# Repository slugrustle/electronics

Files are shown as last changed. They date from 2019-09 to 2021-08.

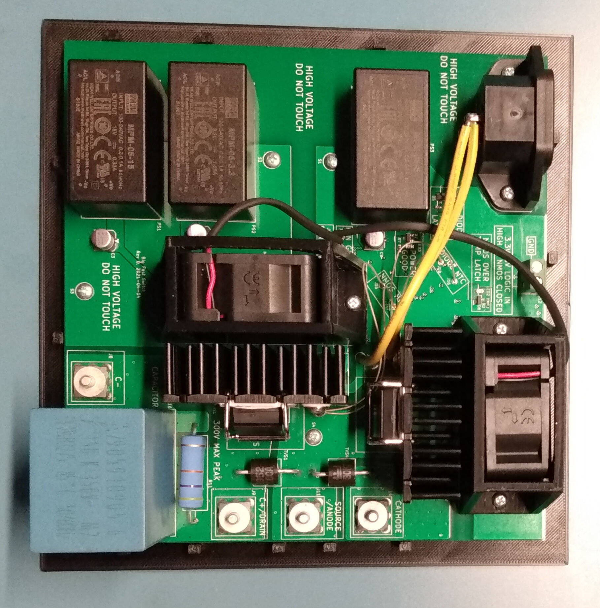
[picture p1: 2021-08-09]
Big_Fast_Switch/Assembled_Unit_Top.jpg

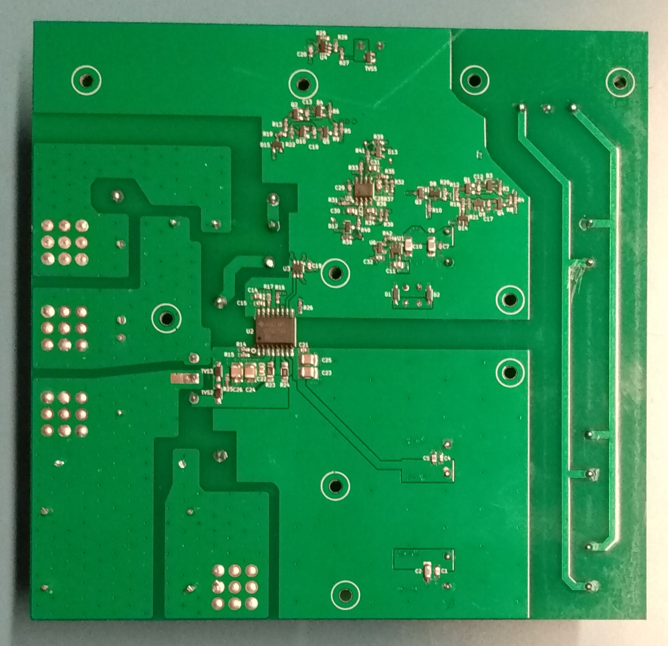
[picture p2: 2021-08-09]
Big_Fast_Switch/Board_Bottom_Soldered.jpg

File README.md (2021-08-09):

# Electronics

This repository includes various electronics projects in a sufficient state of completion to publish informally.

HighImpedanceBuffer is a two&#x2011;channel unity gain buffer amplifier with high impedance inputs and a &#xb1;17.5V input range.

SOT23ZenerTester is a fixture and set of software that can be used to obtain the voltage / current curves of SOT23&#x2011;3 case Zener diodes when used in conjunction with other test equipment.

TestSequencer is a fairly simple board that surrounds an 8&#x2011;bit PIC microcontroller with a power supply, programming header, and various inputs and outputs through ESD protected terminal blocks. I use it for controlling other equipment and running tests.

HH509R\_Logger is a command line program to log temperature measurements from an Omega Engineering HH509R thermocouple reader.

Big\_Fast\_Switch is a sizable combination of film capacitor, N-MOSFET, and rectifier intended for generating input voltage transients to test DC->DC converters.

## Getting Started

The README files the individual directories descibed above are a good place to start.

## Contributing

I would love to receive bug reports and user feedback. If you have improvements to the code, please get in touch.

## Author

Ben Tesch &#x2013; [slugrustle](https://github.com/slugrustle)

## License

All files in this repository that have been produced by the author are distributed under the [CC0 1.0 Universal Public Domain Dedication](https://creativecommons.org/publicdomain/zero/1.0/). See also LICENSE.txt in each project directory and the files themselves.

The projects in this repository store copies of datasheets for parts used in each project. These remain under the copyright of their respective owners and are provided for reference.

The SOT23ZenerTester project also includes copies of files from the redistributable software for the Diolan DLN&#x2011;4ME interface adapter. These files belong to Diolan; see https://diolan.com for more information.

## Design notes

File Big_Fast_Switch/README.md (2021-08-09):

## Big\_Fast\_Switch

This project is a single-board assembly containing the following power electronic devices

- Large, high-voltage film capacitor (B32756G8156K000)
- High-voltage, low Rds(on), wide SOA N-Channel MOSFET (STY145N65M5)
- High-voltage, high-current fast rectifier (VS-90EPF06L-M3)

and the following support electronics / devices

- An isolated gate driver for the N-MOSFET
- Input logic (3.3V level, 5V tolerant) to control the N-MOSFET
- Independent heatsinks, fans, and temperature sensors for the N-MOSFET and Rectifier
- Overtemperature detection and latch circuitry that opens the N-MOSFET if either the N-MOSFET or Rectifier exceeds a temperature limit
- Separate AC->DC power supplies for the gate drive voltage supply (floating) and for the input logic, overtemperature circuitry, and cooling fans

This assembly was designed to aid in generating input voltage transients for the testing of DC->DC power supplies, but it could perhaps find other uses.

WARNING: Dangerous high voltages are present on this board including AC line voltage and high DC voltages. The construction or operation of this device is solely at your own risk. Do not attempt unless you are competent to personally evaluate the safety of high voltage electronic systems.

### Other Info

- Pictures of an assembled unit are available in the root of this repository.
- Design files for the board and schematic (as well as PDF / SVG printouts) are stored in the KiCad directory. I ordered the boards from PCBWay as 4-layer FR-4 boards with 3oz copper on all layers.
- STL files for a PCB holder and mounts for the cooling fans are available in the OpenSCAD directory. I printed these with flame retardant ABS filament.
- A full bill of materials can be found in the Bill\_of\_Materials directory.
- I attempted to save datasheets for all utilized components in the Datasheets directory.
- An LTspice simulation of the overtemperature detection and latch circuitry can be found in the Simulation directory. There are ancillary files from my attempt to create a reasonable model of the APT2012SURCK red LED.
- See LICENSE.txt for licensing info. I have endeavored to clarify which data stored here is my own work and which data belongs to others; all work that is my own is released under the CC0 1.0 Universal Public Domain Dedication.

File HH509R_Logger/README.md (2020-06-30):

## Data Logging Program for HH509R Thermocouple Reader

HH509R\_Logger.exe (in the Release\ directory) is a command line program that records temperature data from an Omega Engineering HH509R datalogging thermocouple reader and saves this data to a .xlsx workbook file. Temperature data is also printed live to the screen while the program is running.

To use this program, run

```PS > .\HH509_Logger.exe COM1 output_file.xlsx```

from PowerShell or the command line. COM1 stands in for the COM port to which the HH509R is connected. The thermocouple reader should be powered on before running HH509\_Logger.exe.

The program ceases collecting data and saves its output .xlsx file under four conditions:

1. The user keys Ctrl+C in the PowerShell or command line window.
2. The program receives no data of any kind from the HH509R for 60 seconds.
3. The program receives no valid data from the HH509R for 300 seconds.
4. The amount of collected data has reached the row limit of a .xlsx workbook file.

See Release\example\_data.xlsx for an example output file.

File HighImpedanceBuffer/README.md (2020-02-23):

## 2&#x2011;Channel High Input Impedance Unity&#x2011;Gain Buffer Amplifier

This project is a 2&#x2011;channel unity&#x2011;gain buffer amplifier built around the Texas Instruments OPA192. The amplifier inputs have ESD protection and high input impedance. The amplifier will behave normally with up to &#xb1;17.5V signal on its inputs. It is powered from a 20VAC 200mA supply such as the Triad Magnetics WAU20&#x2011;200 or similar.

There is a 120&#x3a9; impedance inside the amplifier feedback loop after the internal opamp output pin which limits the output voltage range at heavier output loads. Due to this phenomenon and the thermal characteristics of the voltage regulators, it is recommended that the impedance of the load applied to the output of each amplifier be 1.1k&#x3a9; or higher.

To maintain high input impedance, there is no resistance biasing the external amplifier inputs to GND in a default state. Consequently, if a channel is unused, it is recommended to connect IN to COM (or GND) for that channel.

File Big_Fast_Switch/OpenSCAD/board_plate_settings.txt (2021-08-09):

Application version: 2.20.0.0
Estimated print time: 13h 45m
Material usage: 63.69m (152g)
Printer: Zortrax M200 Plus
Profile: Last settings
Support type: Automatic
Support: 30°
Material: ABS-based filament
Nozzle diameter: 0.4 mm
Layer: 0.14 mm
Quality: Default
Infill: 70%
Fan speed: Auto
Seam: Random
Outer contours: 0.00
Holes: 0.00
Contour-infill gap: 0.40
Contour-top gap: 0.30
Surface layers Top: 5
Surface layers Bottom: 5
Support Lite: Yes
Smart bridges: Yes
Max. wall thickness: 3.03 mm
First layer Density: 100%
First layer Print speed: 100%
First layer Flow ratio: 100%
First layer gap: 0.26 mm
Raft Enabled: Yes
Raft layers: 7
Platform-raft gap: 0.22 mm
Raft Density: 100%
Raft Print speed: 100%
Raft Flow ratio: 100%
Print speed: +0%
Extruder flow ratio: +0%
Top layer infill (%): 100
Bottom layer infill (%): 100
Extrusion temp.: 235
Platform temp.: 90
Retraction speed: 36
Retraction distance: 0.8
Support Density: 3.00 mm
Gap XY: 0.36
Cooling tower: No

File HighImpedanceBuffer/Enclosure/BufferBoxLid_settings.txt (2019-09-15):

Application version: 2.11.1.0
Estimated print time: 3h 34m
Material usage: 17.42m (41g)
Printer: Zortrax M200 Plus
Profile: Last settings
Support type: Automatic
Support: 20°
Material: Z-ULTRAT
Nozzle diameter: 0.4 mm
Layer: 0.14 mm
Quality: High
Infill: 70%
Fan speed: Auto
Seam: Normal
Outer contours: 0.00
Holes: 0.00
Surface layers Top: 5
Surface layers Bottom: 5
Support Lite: No
Smart bridges: No
Support offset: Yes
Max. wall thickness: 3.5 mm
First layer Density: 100%
First layer Print speed: 100%
First layer Flow ratio: 100%
First layer gap: 0.30 mm
Raft Enabled: Yes
Raft layers: 7
Platform-raft gap: 0.24 mm
Raft Density: 100%
Raft Print speed: 100%
Raft Flow ratio: 100%
Support Density: 2.00 mm
Gap XY: 0.36

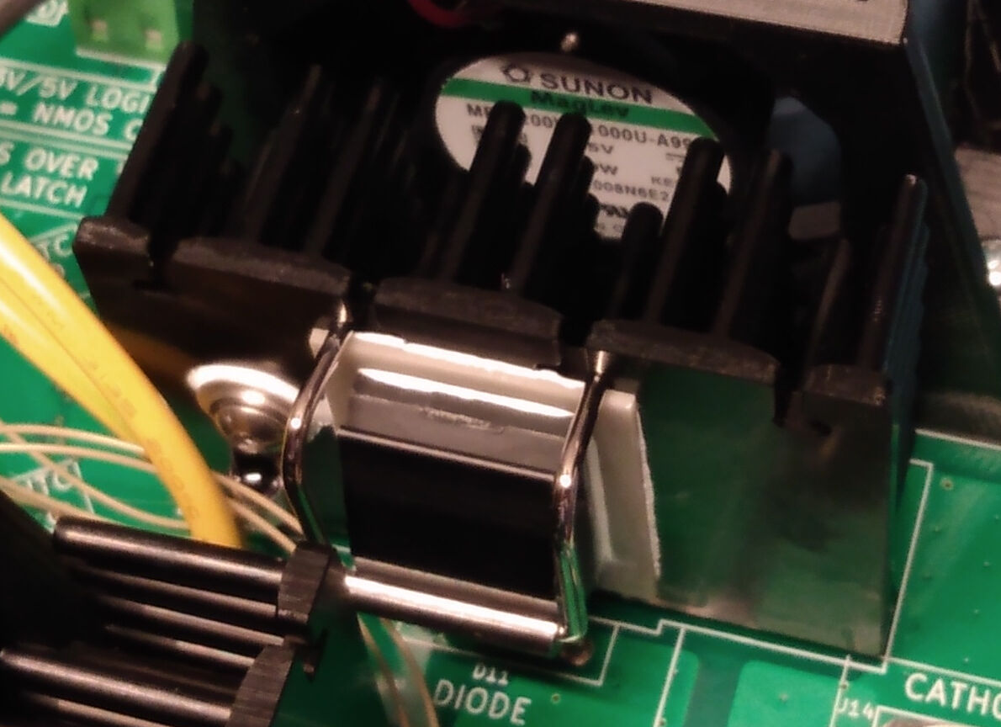
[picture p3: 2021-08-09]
Big_Fast_Switch/Diode_and_NTC_Heatsink_Mounting.jpg

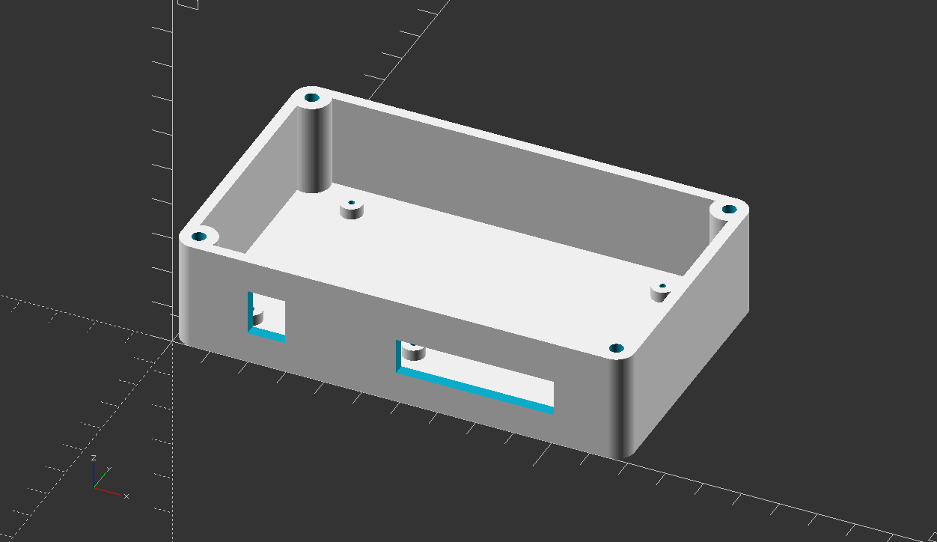
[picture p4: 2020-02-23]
HighImpedanceBuffer/Enclosure/BufferBox_DiagonalView.png

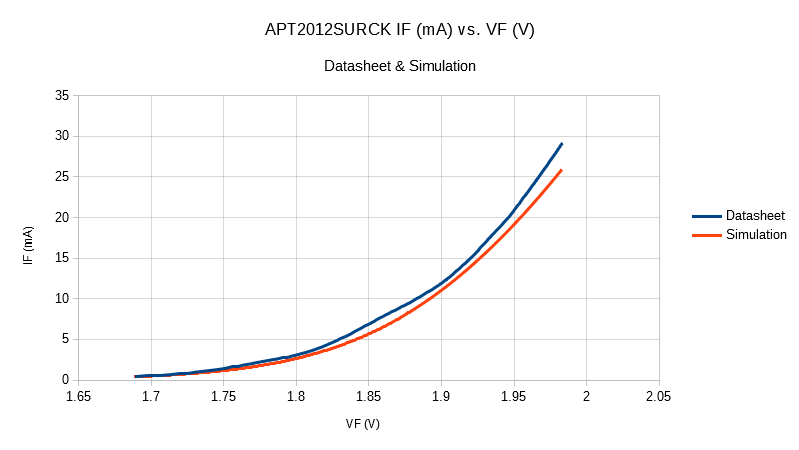
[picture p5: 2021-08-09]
Big_Fast_Switch/Simulation/APT2012SURCK_Model_Check.png

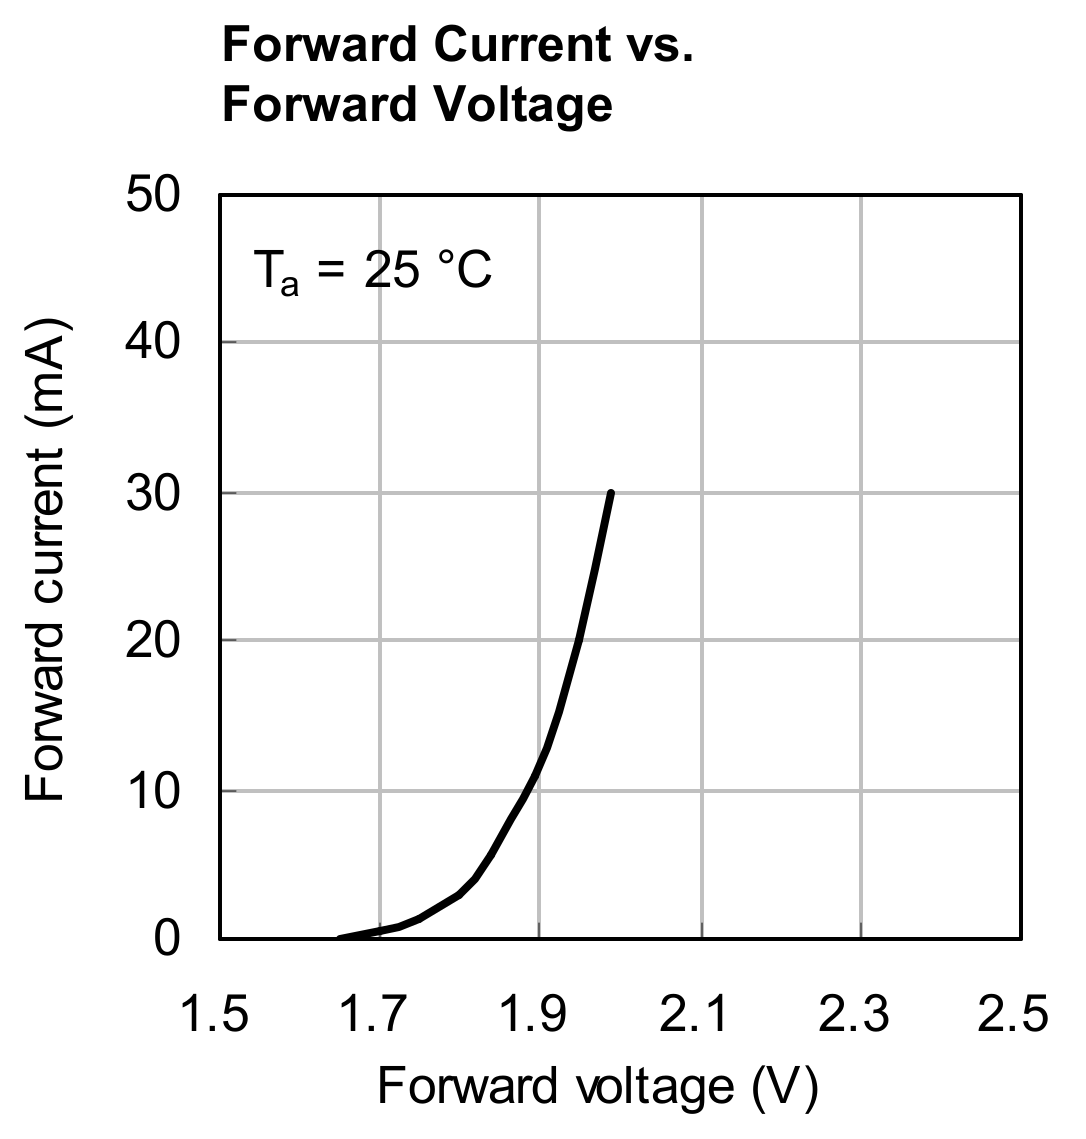
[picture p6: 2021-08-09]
Big_Fast_Switch/Simulation/APT2012SURCK_I-V_298K.png

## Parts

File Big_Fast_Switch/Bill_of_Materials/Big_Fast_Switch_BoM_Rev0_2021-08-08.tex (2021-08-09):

\documentclass[11pt,letterpaper]{article}
\usepackage[T1]{fontenc}
\usepackage{amsmath}
\usepackage{parskip}
\usepackage{longtable}
\usepackage[landscape]{geometry}
\usepackage{titling}
\usepackage{fancyhdr}
\usepackage{lastpage}
\usepackage[math-style=ISO]{unicode-math}
\usepackage{textgreek}
\usepackage{textcomp}
%\usepackage{showframe}

\geometry{
letterpaper,
top=0.5in,
bottom=0.5in,
left=0.5in,
right=0.5in,
includefoot
}

\setlength{\droptitle}{-0.55in}
\pretitle{\begin{flushleft}}
    \posttitle{\end{flushleft}}
\preauthor{\begin{flushleft}}
    \postauthor{\end{flushleft}}
\predate{}
\date{}
\postdate{}

\pagestyle{fancy}
\fancyhf{}
\renewcommand{\headrulewidth}{0pt}
\cfoot{\thepage\ / \pageref{LastPage}}

\begin{document}
\title{Big Fast Switch Rev0 Bill of Materials}
\author{2021{\textendash}08{\textendash}08}
\maketitle
\thispagestyle{fancy}

{\renewcommand{\arraystretch}{1.5}
\begin{longtable}{| l || l | p{4cm} | p{3.5cm} | p{9.5cm} |}
\hline\textbf{Part \#} & \textbf{Quantity} & \textbf{Designators} & \textbf{Manufacturer} & \textbf{Description}\\\hline\hline\endhead
C2012X7R1H104K085AA & 2 & C1, C22 & TDK & 100nF {\textpm}10\% 50V X7R capacitor, 0805 case\\\hline
CL31B225KBHNNNE & 1 & C2 & Samsung & 2.2{\textmu}F {\textpm}10\% 50V X7R capacitor, 1206 case\\\hline
25SVPF47M & 3 & C3, C6, C9 & Panasonic & 47{\textmu}F {\textpm}20\% 25V Aluminum polymer capacitor\\\hline
CL10B104KA8NFNC & 12 & C4, C7, C12, C13, C15, C17{\textendash}C21, C29, C32 & Samsung & 100nF {\textpm}10\% 25V X7R capacitor, 0603 case\\\hline
CL21B225KAFNNWE & 3 & C5, C11, C14 & Samsung & 2.2{\textmu}F {\textpm}10\% 25V X7R capacitor, 0805 case\\\hline
CL31B225KOHNNNE & 2 & C8, C10 & Samsung & 2.2{\textmu}F {\textpm}10\% 16V X7R capacitor, 1206 case\\\hline
B32756G8156K000 & 1 & C16 & TDK & 15{\textmu}F {\textpm}10\% 600V film capacitor\\\hline
CL32B106KAJNNNE & 4 & C23{\textendash}C26 & Samsung & 10{\textmu}F {\textpm}10\% 25V X7R capacitor, 1210 case\\\hline
CL21B475KOFNNNE & 2 & C27, C28 & Samsung & 4.7{\textmu}F {\textpm}10\% 16V X7R capacitor, 0805 case\\\hline
CL21B105KBFNNNG & 2 & C30, C31 & Samsung & 1{\textmu}F {\textpm}10\% 50V X7R capacitor, 0805 case\\\hline
1N4448W-7-F & 2 & D1, D2 & Diodes Inc. & 75V 250mA switching diode, SOD{\textendash}123 case\\\hline
BAS16,215 & 8 & D3{\textendash}D10 & Nexperia & 100V 215mA switching diode, SOT{\textendash}23{\textendash}3 case\\\hline
VS-90EPF06L-M3 & 1 & D11 & Vishay & 600V 90A fast soft recovery rectifier diode, TO{\textendash}247AD 2L case\\\hline
BAV199-7-F & 2 & D12, D13 & Diodes Inc. & Dual 85V 140mA low leakage diode, series connection, SOT{\textendash}23{\textendash}3 case\\\hline
BAS70-7-F & 2 & D14, D15 & Diodes Inc. & 70V 70mA Shottky diode, SOT{\textendash}23{\textendash}3 case\\\hline
PA-T21-38E & 2 & HS1, HS2 & Ohmite & Heatsink with clip for TO{\textendash}247 or TO{\textendash}264 devices\\\hline
NTCALUG02A103F161 & 2 & {\textemdash} & Vishay & 10k{\textOmega} {\textpm}1\% $\text{R}_{25}$ 3984K {\textpm}0.5\% $\text{\textbeta}_{25/85}$ ring lug mount NTC thermistor. Mount one to HS1 and wire to J15 \& J17. Mount the other to HS2 and wire to J16 \& J18.\\\hline
94500A221 & 2 & {\textemdash} & McMaster{\textendash}Carr & M3 x 0.5mm thread, 6mm long 2mm hex drive screw for mounting thermistors to heatsinks\\\hline
93237A102 & 2 & {\textemdash} & McMaster{\textendash}Carr & M3 Belleville washer for mounting thermistors to heatsinks\\\hline
3135-16-1-0500-011-1-TS & {\textemdash} & {\textemdash} & CnC Tech & Stranded 16AWG 600V wire for connecting HS1 (J10) \& HS2 (J13) to earth lug on back of J1\\\hline
703W-00/52 & 1 & J1 & Qualtek & IEC320-C14 AC power input receptacle\\\hline
74651194R & 4 & J8, J9, J11, J14 & Wurth & M4 shank solderable terminal\\\hline
282837-2 & 1 & J12 & TE Connectivity & 5.08mm pitch 2 position rising cage clamp terminal block\\\hline
APT2012SURCK & 3 & LED1{\textendash}LED3 & Kingbright & Red SMT LED, 0805 case\\\hline
{\textemdash} & 2 & M1, M2 & {\textemdash} & 3D printed mount for fan\\\hline
MF40200V1-1000U-A99 & 2 & {\textemdash} & Sunon & 5V 40mm x 40mm x 20mm BLDC fan\\\hline
MPM-05-15 & 1 & PS1 & Meanwell & 15V 5W Medical rated board mount AC/DC converter\\\hline
MPM-05-3.3 & 1 & PS2 & Meanwell & 3.3V 5W Medical rated board mount AC/DC converter\\\hline
MPM-05-5 & 1 & PS3 & Meanwell & 5V 5W Medical rated board mount AC/DC converter\\\hline
MMBT3906LT1G & 2 & Q1, Q2 & ON Semi & 40V 200mA PNP transistor, SOT{\textendash}23{\textendash}3 case\\\hline
MMBT3904LT1G & 3 & Q3{\textendash}Q5 & ON Semi & 40V 200mA NPN transistor, SOT{\textendash}23{\textendash}3 case\\\hline
STY145N65M5 & 1 & Q6 & ST & 650V 15m{\textOmega} 138A N{\textendash}MOSFET, Max247 case\\\hline
{\textemdash} & 2 & {\textemdash} & Shenzhen Jia Rifeng Tai Company & 22mm x 28mm x 1mm Aluminum Nitride insulator for D11 \& Q6. Solid{\textemdash}no mounting hole.\\\hline
249G & {\textemdash} & {\textemdash} & Aavid Thermalloy & Silicone grease for mounting D11 \& Q6.\\\hline
RC0603FR-07620RL & 3 & R1, R2, R7 & Yageo & 620{\textOmega} {\textpm}1\% {\textpm}100ppm/{\textcelsius} 100mW resistor, 0603 case\\\hline
RC0603FR-0733KL & 4 & R3, R6, R21, R22 & Yageo & 33k{\textOmega} {\textpm}1\% {\textpm}100ppm/{\textcelsius} 100mW resistor, 0603 case\\\hline
RC0603FR-0710KL & 7 & R4, R5, R25, R34, R35, R40, R41 & Yageo & 10k{\textOmega} {\textpm}1\% {\textpm}100ppm/{\textcelsius} 100mW resistor, 0603 case\\\hline
RC0603FR-0743KL & 2 & R8, R9 & Yageo & 43k{\textOmega} {\textpm}1\% {\textpm}100ppm/{\textcelsius} 100mW resistor, 0603 case\\\hline
RC0603FR-073K9L & 1 & R10 & Yageo & 3.9k{\textOmega} {\textpm}1\% {\textpm}100ppm/{\textcelsius} 100mW resistor, 0603 case\\\hline
ROX5SJ47K & 1 & R11 & TE Connectivity & 47k{\textOmega} {\textpm}5\% {\textpm}350ppm/{\textcelsius} 5W metal oxide film resistor, axial through hole\\\hline
RC0603FR-076K2L & 2 & R12, R13 & Yageo & 6.2k{\textOmega} {\textpm}1\% {\textpm}100ppm/{\textcelsius} 100mW resistor, 0603 case\\\hline
RC0603JR-07100RL & 2 & R14, R15 & Yageo & 100{\textOmega} {\textpm}5\% {\textpm}100ppm/{\textcelsius} 100mW resistor, 0603 case\\\hline
RC0603JR-0722RL & 2 & R16, R27 & Yageo & 22{\textOmega} {\textpm}5\% {\textpm}100ppm/{\textcelsius} 100mW resistor, 0603 case\\\hline
RC0603JR-071KL & 2 & R17, R26 & Yageo & 1k{\textOmega} {\textpm}5\% {\textpm}100ppm/{\textcelsius} 100mW resistor, 0603 case\\\hline
RC0603FR-072K7L & 2 & R18, R19 & Yageo & 2.7k{\textOmega} {\textpm}1\% {\textpm}100ppm/{\textcelsius} 100mW resistor, 0603 case\\\hline
RC0603FR-0756KL & 1 & R20 & Yageo & 56k{\textOmega} {\textpm}1\% {\textpm}100ppm/{\textcelsius} 100mW resistor, 0603 case\\\hline
CRCW12062R70JNEAHP & 1 & R23 & Vishay & 2.7{\textOmega} {\textpm}5\% {\textpm}200ppm/{\textcelsius} 750mW pulse withstanding resistor, 1206 case\\\hline
CRCW12061R00JNEAHP & 1 & R24 & Vishay & 1{\textOmega} {\textpm}5\% {\textpm}200ppm/{\textcelsius} 750mW pulse withstanding resistor, 1206 case\\\hline
RC0603JR-07100KL & 3 & R28, R29, R42 & Yageo & 100k{\textOmega} {\textpm}5\% {\textpm}100ppm/{\textcelsius} 100mW resistor, 0603 case\\\hline
ERJ-PB3B5230V & 6 & R30, R32, R36{\textendash}R39 & Panasonic & 523{\textOmega} {\textpm}0.1\% {\textpm}50ppm/{\textcelsius} 200mW resistor, 0603 case\\\hline
RC0603FR-077K5L & 2 & R31, R33 & Yageo & 7.5k{\textOmega} {\textpm}1\% {\textpm}100ppm/{\textcelsius} 100mW resistor, 0603 case\\\hline
90417A118 & 4 & S1{\textendash}S4 & McMaster{\textendash}Carr & \#4{\textendash}20 x 3/8" thread forming screw for plastics\\\hline
90417A119 & 6 & {\textemdash} & McMaster{\textendash}Carr & \#4{\textendash}20 x 1/2" thread forming screw for plastics. 2 each applied to J1, M1, and M2.\\\hline
{\textemdash} & 1 & {\textemdash} & {\textemdash} & 3D printed board support plate\\\hline
30KPA300CA & 2 & TVS1, TVS4 & Littelfuse & 300V V\textsubscript{WM} bidirectional TVS diode, P600 axial through hole case\\\hline
SMF15A-E3-08 & 1 & TVS2 & Vishay & 15V V\textsubscript{WM} unidirectional TVS diode, SMF case\\\hline
PTVS3V3S1UR & 1 & TVS3 & Nexperia & 3.3V V\textsubscript{WM} unidirectional TVS diode, SOD{\textendash}123W case\\\hline
DLP05LC-7-F & 1 & TVS5 & Diodes Inc. & 5V V\textsubscript{WM} low capacitance unidirectional TVS diode, SOT{\textendash}23{\textendash}3 case\\\hline
MIC5225-3.3YM5 & 1 & U1 & Microchip & 3.3V linear regulator, SOT{\textendash}23{\textendash}5 case\\\hline
UCC21750 & 1 & U2 & TI & Isolated MOSFET gate driver, Wide SOIC{\textendash}16 case\\\hline
SN74LVC1G11DBVR & 1 & U3 & TI & 3-Input AND gate, SOT{\textendash}23{\textendash}6 case\\\hline
SN74LVC1G17DBVR & 1 & U4 & TI & Non-inverting Schmitt trigger buffer, SOT{\textendash}23{\textendash}5 case\\\hline
LMV762MA & 1 & U5 & TI & Dual precision comparator, SOIC{\textendash}8 case\\\hline
TPS3839G33DBZR & 1 & U6 & TI & 3.08V threshold supply voltage monitor, active low output, SOT{\textendash}23{\textendash}3 case\\\hline
\end{longtable}}
\end{document}

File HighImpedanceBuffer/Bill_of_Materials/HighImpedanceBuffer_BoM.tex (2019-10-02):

\documentclass[11pt,letterpaper]{article}
\usepackage[T1]{fontenc}
\usepackage{amsmath}
\usepackage{parskip}
\usepackage{longtable}
\usepackage{geometry}
\usepackage{titling}
\usepackage{fancyhdr}
\usepackage{lastpage}
\usepackage[math-style=ISO]{unicode-math}
\usepackage{textgreek}
\usepackage{textcomp}
%\usepackage{showframe}

\geometry{
letterpaper,
top=0.5in,
bottom=0.5in,
left=0.5in,
right=0.5in,
includefoot
}

\setlength{\droptitle}{-0.5in}
\pretitle{\begin{flushleft}}
    \posttitle{\end{flushleft}}
\preauthor{\begin{flushleft}}
    \postauthor{\end{flushleft}}
\predate{}
\date{}
\postdate{}

\pagestyle{fancy}
\fancyhf{}
\renewcommand{\headrulewidth}{0pt}
\cfoot{\thepage\ / \pageref{LastPage}}

\begin{document}
\title{High Impedance Buffer Rev4 Bill of Materials}
\author{2019-10-01}
\maketitle
\thispagestyle{fancy}

{\renewcommand{\arraystretch}{1.5}
\begin{longtable}{| l || l | p{2.4cm} | p{3.3cm} | p{4.5cm} |}
\hline\textbf{Part \#} & \textbf{Quantity} & \textbf{Designators} & \textbf{Manufacturer} & \textbf{Description}\\\hline\hline\endhead
PJ-102AH & 1 & J1 & CUI Inc. & Jack for 2.1mm ID, 5.5mm OD barrel plug\\\hline
WAU20-200 & 1 & \textemdash & Triad Magnetics & 120VAC 60Hz input, 20VAC 200mA output wall adapter. 2.1mm ID, 5.5mm OD barrel plug\\\hline
SF-2410FP0375T-2‎ & 1 & F1 & Bourns & 375mA 125V 0.1502$\text{A}^{2}\text{s}$ fast fuse, 2410 case\\\hline
SMBJ36CA-13-F‎ & 1 & D3 & Diodes Inc. & 36V V$_{\text{WM}}$ bidirectional TVS diode, SMB case\\\hline
NRVTSA4100ET3G‎ & 2 & D4, D5 & ON Semiconductor & 100V low leakage, low V$_{\text{F}}$ Schottky diode, SMA case\\\hline
EEV-TG1H471M‎ & 2 & C5, C6 & Panasonic & 470{\textmu}F, 50V, 125{\textdegree}C, low ESR electrolytic capacitor\\\hline
CKG57NX7R2A106M500JH‎ & 4 & C3, C4, C9, C10 & TDK & 10{\textmu}F, 100V, X7R, dual stacked J-Lead capacitor\\\hline
SMBJ18A‎ & 2 & D1, D2 & Taiwan Semiconductor & 18V V$_{\text{WM}}$ unidirectional TVS diode, SMB case\\\hline
TPS7A4901DGNR & 1 & U1 & Texas Instruments & 36V linear regulator, 8-MSOP-EP\\\hline
TPS7A3001DGNR & 1 & U2 & Texas Instruments & 36V negative linear regulator, 8-MSOP-EP\\\hline
GRM1885C1H103JA01D‎ & 4 & C1, C2, C7, C8 & Murata Electronics & 10nF 50V NP0 capacitor, 0603 case\\\hline
DPAD1 & 4 & D6{\textendash}D9 & Linear Systems & Dual 45V picoamp diode, TO-78-5L case\\\hline
CC0805KRX7R9BB104‎ & 4 & C13{\textendash}C16 & Yageo & 100nF 50V X7R capacitor, 0805 case\\\hline
CL31B105KBHNNNE‎ & 4 & C11, C12, C17, C18 & Samsung Electro-Mechanics & 1{\textmu}F 50V X7R capacitor, 1206 case\\\hline
TBD & 2 & C19, C20 & TBD & TBDpF {\textpm}5\% 50V NP0 capacitor, 0603 case\\\hline
OPA192IDR & 2 & U3, U4 & Texas Instruments & {\textpm}18V low offset, low bias current, high input impedance rail-to-rail op amp\\\hline
CMDD6001 & 4 & D10{\textendash}D13 & Central Semiconductor & 75V Low leakage diode, SOD323 case\\\hline
MMBZ27VAL,215 & 2 & D14, D15 & Nexperia & Dual (common anode) low leakage 22V V$_{\text{WM}}$ TVS diode, SOT23-3 case\\\hline
1776540‎ & 1 & J2 & Phoenix Contact & 6 position, 5.08mm pitch right angle socket for terminal block plug\\\hline
1778027‎ & 1 & \textemdash & Phoenix Contact & 6 position 5.08mm pitch terminal block plug, screw clamp\\\hline
ERA-3ARB622V & 2 & R1, R2 & Panasonic & 6.2k{\textOmega} {\textpm}0.1\% {\textpm}10ppm/{\textdegree}C 0.1W resistor, 0603 case\\\hline
RQ73C1J88K7BTD‎ & 2 & R3, R4 & TE Connectivity & 88.7k{\textOmega} {\textpm}0.1\% {\textpm}10ppm/{\textdegree}C 0.1W resistor, 0603 case\\\hline
RC1206JR-072R2L‎ & 2 & R5, R6 & Yageo & 2.2{\textOmega} {\textpm}5\% {\textpm}200ppm/{\textdegree}C 0.25W resistor, 1206 case\\\hline
RC1206FR-0710KL & 2 & R7, R8 & Yageo & 10k{\textOmega} {\textpm}1\% {\textpm}100ppm/{\textdegree}C 0.25W resistor, 1206 case\\\hline
RC1206FR-072K7L‎ & 2 & R11, R13 & Yageo & 2.7k{\textOmega} {\textpm}1\% {\textpm}100ppm/{\textdegree}C 0.25W resistor, 1206 case\\\hline
RC0805FR-071KL & 4 & R9, R10, R12, R14 & Yageo & 1k{\textOmega} {\textpm}1\% {\textpm}100ppm/{\textdegree}C 0.125W resistor, 0805 case\\\hline
RC0805FR-0720RL‎ & 2 & R15, R16 & Yageo & 20{\textOmega} {\textpm}1\% {\textpm}100ppm/{\textdegree}C 0.125W resistor, 0805 case\\\hline
RC1206FR-07100RL‎ & 2 & R17, R18 & Yageo & 100{\textOmega} {\textpm}1\% {\textpm}100ppm/{\textdegree}C 0.25W resistor, 1206 case\\\hline
90380A008 & 6 & S1{\textendash}S6 & McMaster-Carr & \#2-28 thread, 0.3125" long shank, 0.167" head diameter thread forming screw for plastics\\\hline
94997A125 & 2 & \textemdash & McMaster-Carr & M2.2 x 6.5c thread forming screw\\\hline
93365A122 & 4 & \textemdash & McMaster-Carr & \#4-40 heat set threaded insert for plastic, 0.219" tall\\\hline
90272A107 & 4 & \textemdash & McMaster-Carr & \#4-40 thread, 0.3125" long shank machine screw\\\hline
\end{longtable}}

\end{document}

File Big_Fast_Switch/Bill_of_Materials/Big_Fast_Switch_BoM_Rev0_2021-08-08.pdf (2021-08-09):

Big Fast Switch Rev0 Bill of Materials
2021–08–08
Part # | Quantity | Designators | Manufacturer | Description
C2012X7R1H104K085AA | 2 | C1, C22 | TDK | 100nF ±10% 50V X7R capacitor, 0805 case
CL31B225KBHNNNE | 1 | C2 | Samsung | 2.2µF ±10% 50V X7R capacitor, 1206 case
25SVPF47M | 3 | C3, C6, C9 | Panasonic | 47µF ±20% 25V Aluminum polymer capacitor
CL10B104KA8NFNC | 12 | C4, C7, C12, C13, C15, C17–C21, C29, C32 | Samsung | 100nF ±10% 25V X7R capacitor, 0603 case
CL21B225KAFNNWE | 3 | C5, C11, C14 | Samsung | 2.2µF ±10% 25V X7R capacitor, 0805 case
CL31B225KOHNNNE | 2 | C8, C10 | Samsung | 2.2µF ±10% 16V X7R capacitor, 1206 case
B32756G8156K000 | 1 | C16 | TDK | 15µF ±10% 600V film capacitor
CL32B106KAJNNNE | 4 | C23–C26 | Samsung | 10µF ±10% 25V X7R capacitor, 1210 case
CL21B475KOFNNNE | 2 | C27, C28 | Samsung | 4.7µF ±10% 16V X7R capacitor, 0805 case
CL21B105KBFNNNG | 2 | C30, C31 | Samsung | 1µF ±10% 50V X7R capacitor, 0805 case
1N4448W-7-F | 2 | D1, D2 | Diodes Inc. | 75V 250mA switching diode, SOD–123 case
BAS16,215 | 8 | D3–D10 | Nexperia | 100V 215mA switching diode, SOT–23–3 case
VS-90EPF06L-M3 | 1 | D11 | Vishay | 600V 90A fast soft recovery rectifier diode, TO–247AD 2L case
BAV199-7-F | 2 | D12, D13 | Diodes Inc. | Dual 85V 140mA low leakage diode, series connection, SOT–23–3 case
BAS70-7-F | 2 | D14, D15 | Diodes Inc. | 70V 70mA Shottky diode, SOT–23–3 case
PA-T21-38E | 2 | HS1, HS2 | Ohmite | Heatsink with clip for TO–247 or TO–264 devices
NTCALUG02A103F161 | 2 | — | Vishay | 10kΩ ±1% R25 3984K ±0.5% β 25/85 ring lug mount NTC thermistor. Mount one to HS1 and wire to J15 & J17. Mount the other to HS2 and wire to J16 & J18.

Part # | Quantity | Designators | Manufacturer | Description
94500A221 | 2 | — | McMaster–Carr | M3 x 0.5mm thread, 6mm long 2mm hex drive screw for mounting thermistors to heatsinks
93237A102 | 2 | — | McMaster–Carr | M3 Belleville washer for mounting thermistors to heatsinks
3135-16-1-0500-011-1-TS | — | — | CnC Tech | Stranded 16AWG 600V wire for connecting HS1 (J10) & HS2 (J13) to earth lug on back of J1
703W-00/52 | 1 | J1 | Qualtek | IEC320-C14 AC power input receptacle
74651194R | 4 | J8, J9, J11, J14 | Wurth | M4 shank solderable terminal
282837-2 | 1 | J12 | TE Connectivity | 5.08mm pitch 2 position rising cage clamp terminal block
APT2012SURCK | 3 | LED1–LED3 | Kingbright | Red SMT LED, 0805 case
— | 2 | M1, M2 | — | 3D printed mount for fan
MF40200V1-1000U-A99 | 2 | — | Sunon | 5V 40mm x 40mm x 20mm BLDC fan
MPM-05-15 | 1 | PS1 | Meanwell | 15V 5W Medical rated board mount AC/DC converter
MPM-05-3.3 | 1 | PS2 | Meanwell | 3.3V 5W Medical rated board mount AC/DC converter
MPM-05-5 | 1 | PS3 | Meanwell | 5V 5W Medical rated board mount AC/DC converter
MMBT3906LT1G | 2 | Q1, Q2 | ON Semi | 40V 200mA PNP transistor, SOT–23–3 case
MMBT3904LT1G | 3 | Q3–Q5 | ON Semi | 40V 200mA NPN transistor, SOT–23–3 case
STY145N65M5 | 1 | Q6 | ST | 650V 15mΩ 138A N–MOSFET, Max247 case
— | 2 | — | Shenzhen Jia Rifeng Tai Company | 22mm x 28mm x 1mm Aluminum Nitride insulator for D11 & Q6. Solid—no mounting hole.
249G | — | — | Aavid Thermalloy | Silicone grease for mounting D11 & Q6.
RC0603FR-07620RL | 3 | R1, R2, R7 | Yageo | 620Ω ±1% ±100ppm/℃ 100mW resistor, 0603 case
RC0603FR-0733KL | 4 | R3, R6, R21, R22 | Yageo | 33kΩ ±1% ±100ppm/℃ 100mW resistor, 0603 case
RC0603FR-0710KL | 7 | R4, R5, R25, R34, R35, R40, R41 | Yageo | 10kΩ ±1% ±100ppm/℃ 100mW resistor, 0603 case

RC0603FR-0743KL | 2 | R8, R9 | Yageo | 43kΩ ±1% ±100ppm/℃ 100mW resistor, 0603 case
RC0603FR-073K9L | 1 | R10 | Yageo | 3.9kΩ ±1% ±100ppm/℃ 100mW resistor, 0603 case
ROX5SJ47K | 1 | R11 | TE Connectivity | 47kΩ ±5% ±350ppm/℃ 5W metal oxide film resistor, axial through hole
RC0603FR-076K2L | 2 | R12, R13 | Yageo | 6.2kΩ ±1% ±100ppm/℃ 100mW resistor, 0603 case
RC0603JR-07100RL | 2 | R14, R15 | Yageo | 100Ω ±5% ±100ppm/℃ 100mW resistor, 0603 case
RC0603JR-0722RL | 2 | R16, R27 | Yageo | 22Ω ±5% ±100ppm/℃ 100mW resistor, 0603 case
RC0603JR-071KL | 2 | R17, R26 | Yageo | 1kΩ ±5% ±100ppm/℃ 100mW resistor, 0603 case
RC0603FR-072K7L | 2 | R18, R19 | Yageo | 2.7kΩ ±1% ±100ppm/℃ 100mW resistor, 0603 case
RC0603FR-0756KL | 1 | R20 | Yageo | 56kΩ ±1% ±100ppm/℃ 100mW resistor, 0603 case
CRCW12062R70JNEAHP | 1 | R23 | Vishay | 2.7Ω ±5% ±200ppm/℃ 750mW pulse withstanding re-sistor, 1206 case
CRCW12061R00JNEAHP | 1 | R24 | Vishay | 1Ω ±5% ±200ppm/℃ 750mW pulse withstanding resis-tor, 1206 case
RC0603JR-07100KL | 3 | R28, R29, R42 | Yageo | 100kΩ ±5% ±100ppm/℃ 100mW resistor, 0603 case
ERJ-PB3B5230V | 6 | R30, R32, R36–R39 | Panasonic | 523Ω ±0.1% ±50ppm/℃ 200mW resistor, 0603 case
RC0603FR-077K5L | 2 | R31, R33 | Yageo | 7.5kΩ ±1% ±100ppm/℃ 100mW resistor, 0603 case
90417A118 | 4 | S1–S4 | McMaster–Carr | #4–20 x 3/8” thread forming screw for plastics
90417A119 | 6 | — | McMaster–Carr | #4–20 x 1/2” thread forming screw for plastics. 2 each applied to J1, M1, and M2.
— | 1 | — | — | 3D printed board support plate
30KPA300CA | 2 | TVS1, TVS4 | Littelfuse | 300V VWM bidirectional TVS diode, P600 axial through hole case
SMF15A-E3-08 | 1 | TVS2 | Vishay | 15V VWM unidirectional TVS diode, SMF case
PTVS3V3S1UR | 1 | TVS3 | Nexperia | 3.3V VWM unidirectional TVS diode, SOD–123W case

DLP05LC-7-F | 1 | TVS5 | Diodes Inc. | 5V VWM low capacitance unidirectional TVS diode, SOT–23–3 case
MIC5225-3.3YM5 | 1 | U1 | Microchip | 3.3V linear regulator, SOT–23–5 case
UCC21750 | 1 | U2 | TI | Isolated MOSFET gate driver, Wide SOIC–16 case
SN74LVC1G11DBVR | 1 | U3 | TI | 3-Input AND gate, SOT–23–6 case
SN74LVC1G17DBVR | 1 | U4 | TI | Non-inverting Schmitt trigger buffer, SOT–23–5 case
LMV762MA | 1 | U5 | TI | Dual precision comparator, SOIC–8 case
TPS3839G33DBZR | 1 | U6 | TI | 3.08V threshold supply voltage monitor, active low out-put, SOT–23–3 case

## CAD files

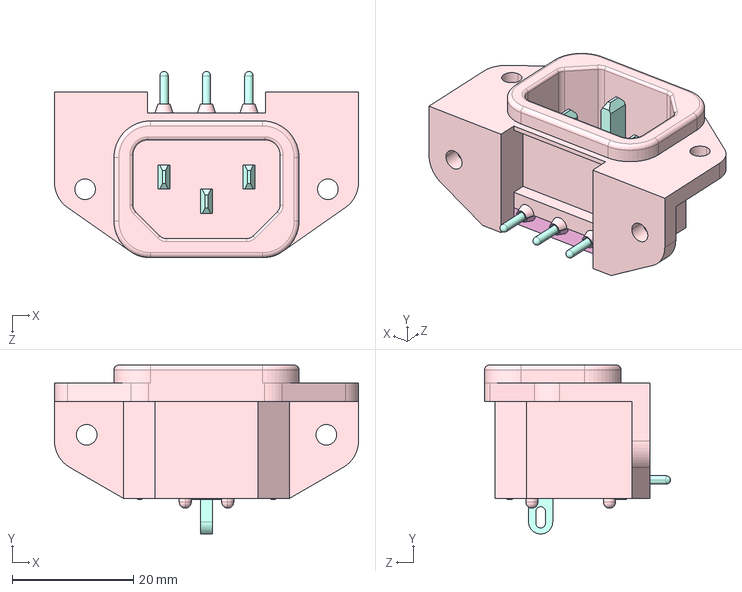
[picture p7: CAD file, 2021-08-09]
Big_Fast_Switch/Datasheets/703W-00-52_Qualtek.step
50.1 x 27.8 x 30.6 mm

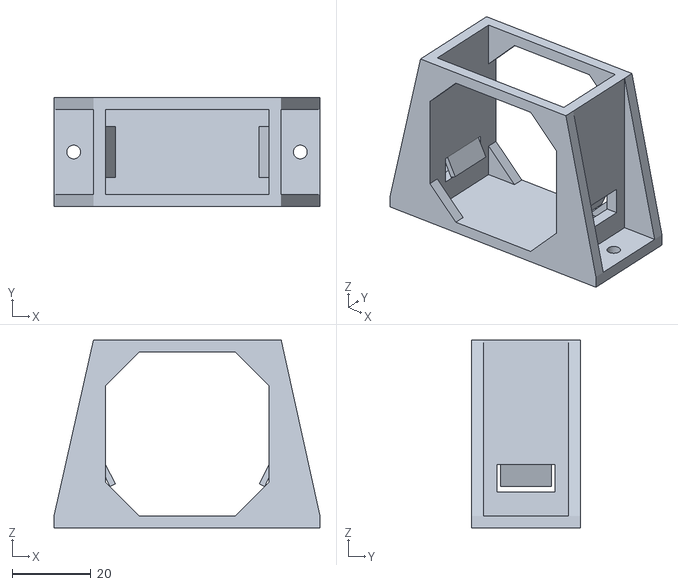
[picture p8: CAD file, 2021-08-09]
Big_Fast_Switch/OpenSCAD/fan_mount.stl
67.5 x 27.7 x 47.7

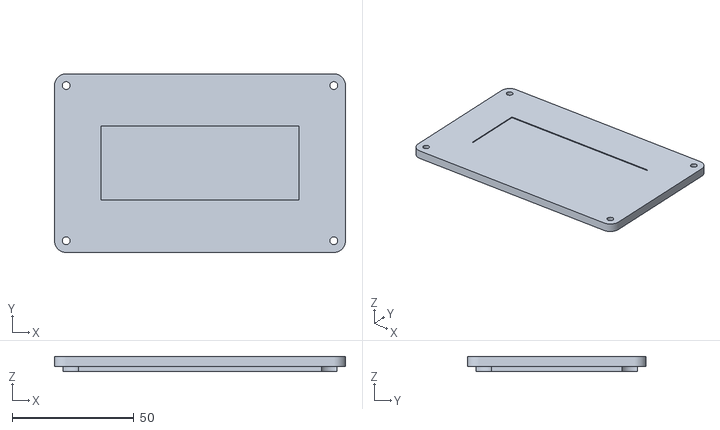
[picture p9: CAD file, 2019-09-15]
HighImpedanceBuffer/Enclosure/BufferBoxLid.stl
119.6 x 76.0 x 6.16

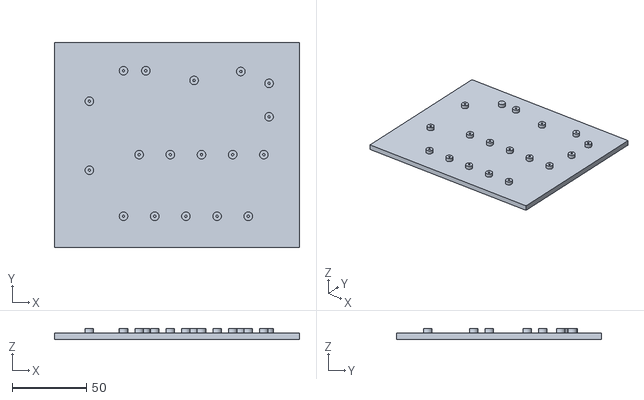
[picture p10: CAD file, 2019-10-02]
SOT23ZenerTester/SupportPlate/SOT23ZenerTester_Plate.stl
165.0 x 138.0 x 7.28

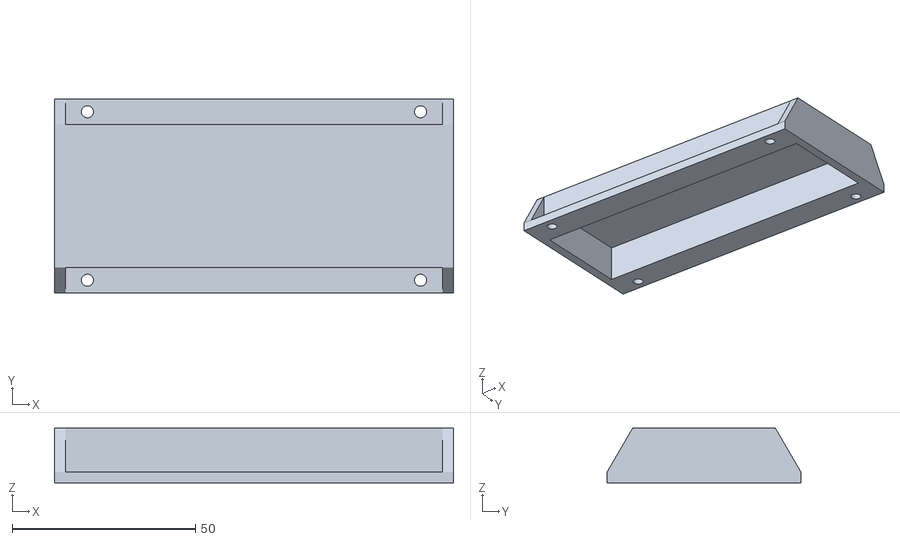
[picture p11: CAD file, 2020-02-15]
TestSequencer/Enclosure/TestSequencer_TopCover.stl
109.0 x 53.0 x 14.9

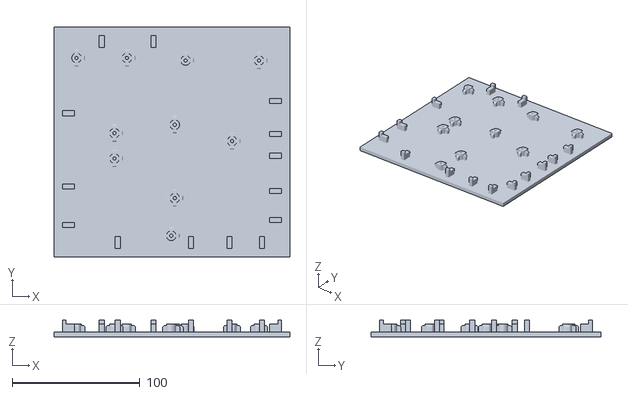
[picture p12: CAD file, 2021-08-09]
Big_Fast_Switch/OpenSCAD/board_plate.stl
185.0 x 180.0 x 13.2

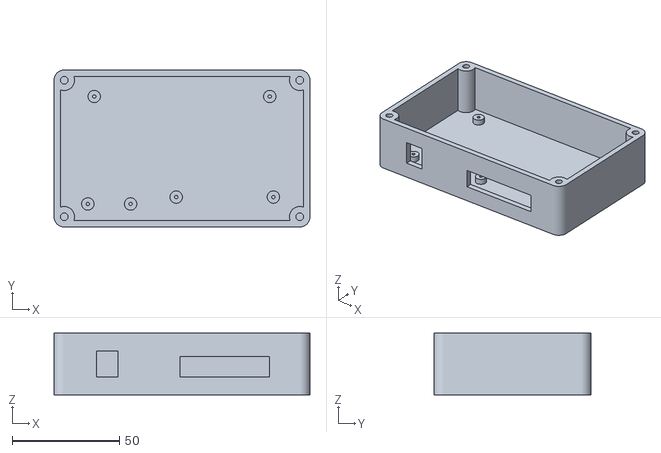
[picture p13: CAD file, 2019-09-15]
HighImpedanceBuffer/Enclosure/BufferBox.stl
119.6 x 73.4 x 28.9

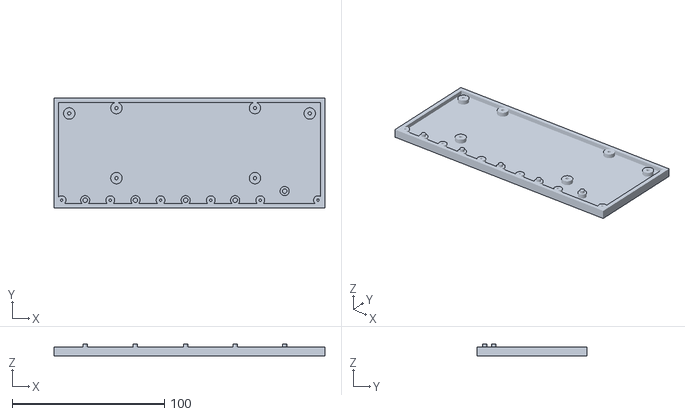
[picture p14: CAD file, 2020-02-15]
TestSequencer/Enclosure/TestSequencer_BottomPlate.stl
178.0 x 72.0 x 7.84

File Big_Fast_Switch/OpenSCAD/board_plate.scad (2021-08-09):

// This file is meant for use with OpenSCAD, a
// constructive solid geometry 3D CAD program.
// See https://www.openscad.org/
$fa = 6;
$fs = 0.05;

// Dimensional constants. Lengths are in millimeters.
// Some dimensions are rounded to 0.14mm layer height
platethick = 4.06;
bossheight = 6.16;
boss_outer_radius = 3.75;
screw_hole_radius = 1.3;
screw_hole_depth = 8.12;
ribthick = 3;
riblength = 3;
ribheight = 4.76;
ribchamfer = 0.98;
supportheight = bossheight;
supportinset = 6;
supportthick = 4;
notchheight = 3;
notchlength = 3;
supportgap = 0.5;
plateborder = 10;
boardwidth = 165;
boardlength = 160;

// Screw boss locations and rib selections
// [[X, Y], [N, S, E, W]]
// First 2 are screw boss center locations on board in millimeters
// Last 4 are ribs to enable (true) or disable (false)
screwbosses = [
  [[7.65, 145.9], [true, true, true, false]], 
  [[47.15, 145.9], [true, true, true, true]],
  [[37.4, 86.9], [true, true, true, true]],
  [[37.4, 67.1], [true, true, true, true]],
  [[81.9, 6.5], [true, false, true, true]],
  [[129.6, 80.7], [true, true, true, true]],
  [[84.7, 36.025], [true, true, true, true]],
  [[84.7, 93.525], [true, true, false, true]],
  [[93.175, 143.9], [true, false, true, true]],
  [[150.675, 143.9], [true, true, true, true]]
];

// Board north side support locations
// millimeters east of northwest board corner
northsupports = [27.4, 68];

// Board south side support locations
// millimeters east of southwest board corner
southsupports = [40, 97.3, 127.5, 153];

// Board east side support locations
// millimeters north of southeast board corner
eastsupports = [19, 41.7, 69.2, 86.3, 112];

// Board west side support locations
// millimeters north of southwest board corner
westsupports = [15, 45, 102.5];

module screwboss(boardloc2d, ribenables)
{
  module bossrib()
  {
    translate([0,ribthick/2,0])
    {
      rotate([90,0,0])
      {
        linear_extrude(height=ribthick)
        {
          polygon(points = [[0,0], [riblength+0.2,0],[riblength+0.2,ribheight-ribchamfer],[riblength+0.2-ribchamfer,ribheight],[0,ribheight]]);
        }
      }
    }
  }
  
  union()
  {
    translate(concat(boardloc2d, [0]) + [plateborder,plateborder,platethick])
    {
      cylinder(r=boss_outer_radius, h=bossheight);
    }
    
    if (ribenables[0])
    {
      translate(concat(boardloc2d, [0]) + [plateborder,plateborder,platethick] + [0, boss_outer_radius-0.2, 0])
      {
        rotate([0,0,90])
        {
          bossrib();
        }
      }
    }
    
    if (ribenables[1])
    {
      translate(concat(boardloc2d, [0]) + [plateborder,plateborder,platethick] + [0, -boss_outer_radius+0.2, 0])
      {
        rotate([0,0,-90])
        {
          bossrib();
        }
      }
    }
    
    if (ribenables[2])
    {
      translate(concat(boardloc2d, [0]) + [plateborder,plateborder,platethick] + [boss_outer_radius-0.2, 0, 0])
      {
        bossrib();
      }
    }
    
    if (ribenables[3])
    {
      translate(concat(boardloc2d, [0]) + [plateborder,plateborder,platethick] + [-boss_outer_radius+0.2, 0, 0])
      {
        rotate([0,0,180])
        {
          bossrib();
        }
      }
    }
  }
}

module boardsupport()
{
  // Default orientation is for an east support centered at 0 along  a fictitious board edge formed by the Y axis
  translate([-supportinset,supportthick/2,0])
  {
    rotate([90, 0, 0])
    {
      linear_extrude(height = supportthick)
      {
        polygon(points = [[0,0], [supportinset+supportgap+notchlength,0], [supportinset+supportgap+notchlength,supportheight+notchheight], [supportinset+supportgap,supportheight+notchheight], [supportinset+supportgap,supportheight], [0,supportheight]]);
      }
    }
  }
}

// Put everything together
difference()
{
  union()
  {
    // Bottom plate
    cube([2*plateborder+boardwidth, 2*plateborder+boardlength, platethick]);
    
    // Screw bosses but not screw holes
    for(sb = screwbosses)
    {
      screwboss(sb[0], sb[1]);
    }
    
    // North side board supports
    for (ns = northsupports)
    {
      translate([plateborder + ns, plateborder + boardlength, platethick])
      {
        rotate([0, 0, 90])
        {
          boardsupport();
        }
      }
    }
    
    // South side board supports
    for (ss = southsupports)
    {
      translate([plateborder + ss, plateborder, platethick])
      {
        rotate([0, 0, -90])
        {
          boardsupport();
        }
      }
    }
    
    // East side board supports
    for (es = eastsupports)
    {
      translate([plateborder + boardwidth, plateborder + es, platethick])
      {
        boardsupport();
      }
    }
    
    // West side board supports
    for (ws = westsupports)
    {
      translate([plateborder, plateborder + ws, platethick])
      {
        rotate([0, 0, 180])
        {
          boardsupport();
        }
      }
    }
    
  }
  
  // Holes for screws
  for(sb = screwbosses)
  {
    translate([plateborder + sb[0][0], plateborder + sb[0][1], platethick + bossheight - screw_hole_depth])
    {
      cylinder(r=screw_hole_radius, h=screw_hole_depth);
    }
  }
}

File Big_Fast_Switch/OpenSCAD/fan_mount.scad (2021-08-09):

$fa = 6;
$fs = 0.05;

$wallthick = 3.08;
$totalwidth = 67.5;
$cornerside = 6*sqrt(2);
$fanside = 41.5;
$totalheight = $fanside+2*$wallthick;
$bendheight = 13+$wallthick;
$bendwidth = 12.88;
$bendgap = 0.98;
$shortvertheight = 6+$wallthick;
$betweenplates = 21.56;
$screwholedia = 3.5;
$screwholecenterinset = 5;
$sidesupport = 2*$screwholecenterinset;

module face_plate()
{
  linear_extrude($wallthick)
  {
    polygon(points=[[0,0],[0,$wallthick],[$sidesupport,$totalheight],[$totalheight+$sidesupport,$totalheight],[$totalwidth,$wallthick],[$totalwidth,0],[$sidesupport+$wallthick+$cornerside,$wallthick],[$sidesupport+$wallthick,$wallthick+$cornerside],[$sidesupport+$wallthick,$fanside+$wallthick-$cornerside],[$sidesupport+$wallthick+$cornerside,$fanside+$wallthick],[$fanside+$sidesupport+$wallthick-$cornerside,$fanside+$wallthick],[$fanside+$sidesupport+$wallthick,$fanside+$wallthick-$cornerside],[$fanside+$sidesupport+$wallthick,$wallthick+$cornerside],[$fanside+$sidesupport+$wallthick-$cornerside,$wallthick]], paths=[[0,1,2,3,4,5],[6,7,8,9,10,11,12,13]]);
  }
}

module bend()
{
  linear_extrude($bendwidth)
  {
    polygon(points=[[-2.5,-2*sqrt(6)],[0,0],[$wallthick/2,0],[-2.5+$wallthick*2*sqrt(6)/11,-2*sqrt(6)-$wallthick*5/22]]);
  }
}

difference()
{
  union()
  {
    // bottom plate
    cube([$totalwidth,2*$wallthick+$betweenplates,$wallthick]);
    
    // left lower side plate
    translate([$sidesupport,0,0])
    {
      cube([$wallthick,2*$wallthick+$betweenplates,$shortvertheight]);
    }
    
    // left bend sides
    translate([$sidesupport,0,0])
    {
      cube([$wallthick,$wallthick+($betweenplates-$bendwidth-2*$bendgap)/2,$wallthick+$bendheight+0.001]);
    }
    
    translate([$sidesupport,$wallthick+$betweenplates-($betweenplates-$bendwidth-2*$bendgap)/2,0])
    {
      cube([$wallthick,$wallthick+($betweenplates-$bendwidth-2*$bendgap)/2,$wallthick+$bendheight+0.001]);
    }
    
    // left upper side plate
    translate([$sidesupport,0,$bendheight])
    {
      cube([$wallthick,2*$wallthick+$betweenplates,$totalheight-$bendheight]);
    }
    
    // leftt bend
    translate([$sidesupport+$wallthick,(2*$wallthick+$betweenplates-$bendwidth)/2,$bendheight])
    {
      rotate([0,0,180])
      {
        rotate([90,0,0])
        {
          bend();
        }
      }
    }
    
    // right lower side plate
    translate([$fanside+$sidesupport+$wallthick,0,0])
    {
      cube([$wallthick,2*$wallthick+$betweenplates,$shortvertheight]);
    }
    
    // right bend sides
    translate([$fanside+$sidesupport+$wallthick,0,0])
    {
      cube([$wallthick,$wallthick+($betweenplates-$bendwidth-2*$bendgap)/2,$wallthick+$bendheight+0.001]);
    }
    
    translate([$fanside+$sidesupport+$wallthick,$wallthick+$betweenplates-($betweenplates-$bendwidth-2*$bendgap)/2,0])
    {
      cube([$wallthick,$wallthick+($betweenplates-$bendwidth-2*$bendgap)/2,$wallthick+$bendheight+0.001]);
    }
    
    // right upper side plate
    translate([$fanside+$sidesupport+$wallthick,0,$bendheight])
    {
      cube([$wallthick,2*$wallthick+$betweenplates,$totalheight-$bendheight]);
    }
    
    // right bend
    translate([$fanside+$sidesupport+$wallthick,(2*$wallthick+$betweenplates+$bendwidth)/2,$bendheight])
    {
      rotate([90,0,0])
      {
        bend();
      }
    }
    
    // rear face
    translate([0,$wallthick,0])
    {
      rotate([90,0,0])
      {
        face_plate();
      }
    }

    // front face
    translate([0,2*$wallthick+$betweenplates,0])
    {
      rotate([90,0,0])
      {
        face_plate();
      }
    }
  }

  // screw holes
  translate([$screwholecenterinset,(2*$wallthick+$betweenplates)/2,0])
  {
    cylinder(r=$screwholedia/2,h=$wallthick);
  }
  
  translate([$totalwidth-$screwholecenterinset,(2*$wallthick+$betweenplates)/2,0])
  {
    cylinder(r=$screwholedia/2,h=$wallthick);
  }  
}

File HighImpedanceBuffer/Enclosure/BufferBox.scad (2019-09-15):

// This file is meant for use with OpenSCAD, a
// constructive solid geometry 3D CAD program.
// See https://www.openscad.org/
// The height dimensions have been rounded to best
// support a 0.14mm layer height.
$fa = 3;
$fs = 0.05;

$wallthick = 3;
$bottomthick = 4.34;
$insertholedia = 3.6;
$insertholedepth = 5.6;
$cornerdia = 2*$wallthick+$insertholedia;
$boardcornerrad = 6;
$screwblind = 0.7;
$standoffheight = 2.94;
$standoff_inner_radius = 0.8;
$standoff_outer_radius = 2.9;
$boardwidth = 110;
$boarddepth = 61.8;
$boardoffsetfront = 0.5*$cornerdia - 0.8;
// $boardoffsetback has extra margin because the connectors
// hang off the front edge of the board by 4mm
$boardoffsetback = 0.5*$cornerdia + 2.8;
$boardoffsetside = 0.5*$cornerdia;
$boardthick = 1.6;
$depth = $boardoffsetfront + $boardoffsetback + $boarddepth;
$width = 2*$boardoffsetside + $boardwidth;
$height = $bottomthick + $standoffheight + $boardthick + 20.02;
$standoff1_boardx = 11;
$standoff1_boardy = 6.8;
$standoff2_boardx = 31;
$standoff2_boardy = 6.8;
$standoff3_boardx = 52.3;
$standoff3_boardy = 10;
$standoff4_boardx = 97.7;
$standoff4_boardy = 10;
$standoff5_boardx = 14;
$standoff5_boardy = 57;
$standoff6_boardx = 96;
$standoff6_boardy = 57;
$standoff1_x = $boardoffsetside + $standoff1_boardx;
$standoff1_y = $boardoffsetfront + $standoff1_boardy;
$standoff2_x = $boardoffsetside + $standoff2_boardx;
$standoff2_y = $boardoffsetfront + $standoff2_boardy;
$standoff3_x = $boardoffsetside + $standoff3_boardx;
$standoff3_y = $boardoffsetfront + $standoff3_boardy;
$standoff4_x = $boardoffsetside + $standoff4_boardx;
$standoff4_y = $boardoffsetfront + $standoff4_boardy;
$standoff5_x = $boardoffsetside + $standoff5_boardx;
$standoff5_y = $boardoffsetfront + $standoff5_boardy;
$standoff6_x = $boardoffsetside + $standoff6_boardx;
$standoff6_y = $boardoffsetfront + $standoff6_boardy;
$dcjack_x = $boardoffsetside + 15;
$dcjack_z = $bottomthick + $standoffheight + $boardthick - 0.62;
$dcjackwidth = 10;
$dcjackheight = 12.18;
$termsocket_x = $boardoffsetside + 54.18;
$termsocket_z = $bottomthick + $standoffheight + $boardthick - 0.62;
$termsocketwidth = 41.64;
$termsocketheight = 9.66;

// circuit board, for debugging. prepended with *
// so it doesn't show up during STL export.
*translate([$boardoffsetside, $boardoffsetfront, $bottomthick+$standoffheight])
{
  difference()
  {
    cube([$boardwidth, $boarddepth, $boardthick]);
    cube([$boardcornerrad, 0.8, $boardthick]);
    translate([$boardwidth-$boardcornerrad, 0, 0])
    {
      cube([$boardcornerrad, 0.8, $boardthick]);
    }
    translate([0, 0.8, 0])
    {
      cylinder(r=$boardcornerrad, h=$boardthick);
    }
    translate([$boardwidth, 0.8, 0])
    {
      cylinder(r=$boardcornerrad, h=$boardthick);
    }
    translate([0, $boarddepth, 0])
    {
      cylinder(r=$boardcornerrad, h=$boardthick);
    }
    translate([$boardwidth, $boarddepth, 0])
    {
      cylinder(r=$boardcornerrad, h=$boardthick);
    }
    translate([$standoff1_boardx, $standoff1_boardy, 0])
    {
      cylinder(r=$standoff_inner_radius, h=$boardthick);
    }
    translate([$standoff2_boardx, $standoff2_boardy, 0])
    {
      cylinder(r=$standoff_inner_radius, h=$boardthick);
    }
    translate([$standoff3_boardx, $standoff3_boardy, 0])
    {
      cylinder(r=$standoff_inner_radius, h=$boardthick);
    }
    translate([$standoff4_boardx, $standoff4_boardy, 0])
    {
      cylinder(r=$standoff_inner_radius, h=$boardthick);
    }
    translate([$standoff5_boardx, $standoff5_boardy, 0])
    {
      cylinder(r=$standoff_inner_radius, h=$boardthick);
    }
    translate([$standoff6_boardx, $standoff6_boardy, 0])
    {
      cylinder(r=$standoff_inner_radius, h=$boardthick);
    }
  }
}

difference()
{
  union()
  {
    // Corner pillars
    translate([0.5*$cornerdia, 0.5*$cornerdia, 0])
    {
      cylinder(d=$cornerdia, h=$height);
    }

    translate([$width-0.5*$cornerdia, 0.5*$cornerdia, 0])
    {
      cylinder(d=$cornerdia, h=$height);
    }

    translate([0.5*$cornerdia, $depth-0.5*$cornerdia, 0])
    {
      cylinder(d=$cornerdia, h=$height);
    }

    translate([$width-0.5*$cornerdia, $depth-0.5*$cornerdia, 0])
    {
      cylinder(d=$cornerdia, h=$height);
    }
    
    // Walls
    translate([0.5*$cornerdia, 0, 0])
    {
      cube([$width-$cornerdia, $wallthick, $height]);
    }
    
    translate([0, 0.5*$cornerdia, 0])
    {
      cube([$wallthick, $depth-$cornerdia, $height]);
    }
    
    translate([0.5*$cornerdia, $depth - $wallthick, 0])
    {
      cube([$width-$cornerdia, $wallthick, $height]);
    }
    
    translate([$width - $wallthick, 0.5*$cornerdia, 0])
    {
      cube([$wallthick, $depth-$cornerdia, $height]);
    }
    
    // Bottom plate
    translate([0.5*$wallthick, 0.5*$wallthick, 0])
    {
      cube([$width - $wallthick, $depth - $wallthick, $bottomthick]);
    }
    
    // Board standoffs
    translate([$standoff1_x, $standoff1_y, $bottomthick])
    {
      cylinder(r=$standoff_outer_radius, h=$standoffheight);
    }
    
    translate([$standoff2_x, $standoff2_y, $bottomthick])
    {
      cylinder(r=$standoff_outer_radius, h=$standoffheight);
    }
    
    translate([$standoff3_x, $standoff3_y, $bottomthick])
    {
      cylinder(r=$standoff_outer_radius, h=$standoffheight);
    }
    
    translate([$standoff4_x, $standoff4_y, $bottomthick])
    {
      cylinder(r=$standoff_outer_radius, h=$standoffheight);
    }
    
    translate([$standoff5_x, $standoff5_y, $bottomthick])
    {
      cylinder(r=$standoff_outer_radius, h=$standoffheight);
    }
    
    translate([$standoff6_x, $standoff6_y, $bottomthick])
    {
      cylinder(r=$standoff_outer_radius, h=$standoffheight);
    }
  }
  
  // Standoff screw holes
  translate([$standoff1_x, $standoff1_y, $screwblind])
  {
    cylinder(r=$standoff_inner_radius, h=$bottomthick+$standoffheight-$screwblind);
  }
  
  translate([$standoff2_x, $standoff2_y, $screwblind])
  {
    cylinder(r=$standoff_inner_radius, h=$bottomthick+$standoffheight-$screwblind);
  }
  
  translate([$standoff3_x, $standoff3_y, $screwblind])
  {
    cylinder(r=$standoff_inner_radius, h=$bottomthick+$standoffheight-$screwblind);
  }
  
  translate([$standoff4_x, $standoff4_y, $screwblind])
  {
    cylinder(r=$standoff_inner_radius, h=$bottomthick+$standoffheight-$screwblind);
  }
  
  translate([$standoff5_x, $standoff5_y, $screwblind])
  {
    cylinder(r=$standoff_inner_radius, h=$bottomthick+$standoffheight-$screwblind);
  }
  
  translate([$standoff6_x, $standoff6_y, $screwblind])
  {
    cylinder(r=$standoff_inner_radius, h=$bottomthick+$standoffheight-$screwblind);
  }
  
  // Holes for lid screw threaded inserts
  translate([0.5*$cornerdia, 0.5*$cornerdia, $height - $insertholedepth])
  {
    cylinder(d=$insertholedia, h=$insertholedepth);
  }
  
  translate([$width-0.5*$cornerdia, 0.5*$cornerdia, $height - $insertholedepth])
  {
    cylinder(d=$insertholedia, h=$insertholedepth);
  }

  translate([0.5*$cornerdia, $depth-0.5*$cornerdia, $height - $insertholedepth])
  {
    cylinder(d=$insertholedia, h=$insertholedepth);
  }

  translate([$width-0.5*$cornerdia, $depth-0.5*$cornerdia, $height - $insertholedepth])
  {
    cylinder(d=$insertholedia, h=$insertholedepth);
  }
  
  // Front wall opening for DC jack
  translate([$dcjack_x, 0, $dcjack_z])
  {
    cube([$dcjackwidth, $wallthick, $dcjackheight]);
  }
  
  // Front wall opening for terminal block socket
  translate([$termsocket_x, 0, $termsocket_z])
  {
    cube([$termsocketwidth, $wallthick, $termsocketheight]);
  }
}

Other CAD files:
HighImpedanceBuffer/Enclosure/BufferBoxLid.scad
SOT23ZenerTester/SupportPlate/SOT23ZenerTester_Plate.scad
TestSequencer/Enclosure/TestSequencer_BottomPlate.scad
TestSequencer/Enclosure/TestSequencer_TopCover.scad

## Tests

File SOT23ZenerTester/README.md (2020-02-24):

## Fixture and Software for Testing SOT23&#x2011;3 Zener Diodes

This project includes a circuit board designed to obtain the voltage / current characteristics
of SOT23&#x2011;3 package Zener diodes when used in conjunction with the following test equipment:

1. A Diolan DLN&#x2011;4ME interface adapter to control the fixture board relays for selecting the Zener diode and pullup resistor to use in testing
2. An ITECH IT6100B series power supply (the IT6123B is a good choice) to bias the Zener diode under test via the selected fixture pullup resistor
3. A Rigol DM3068 digital multimeter to measure the Zener diode cathode voltage when the diode is biased
4. A PC with at least 1 USB2 port (for the Diolan DLN&#x2011;4ME) and at least 2 RS232 ports (for the power supply and DMM)

This project also includes software to control the test equipment, calculate the Zener diode voltage / current characteristics from measurement data, and output the results in a .xlsx workbook.

Many elements of the test setup can be specified in a text&#x2011;based configuration file; examples of these can be found in the FixtureProgram/Release directory. There are two test programs: TestZeners, which obtains a full voltage / current curve, and SingleShot, which measures the Zener diode voltage / current at a single fixture setting after a \~1ms delay. Example output files for each program can be found in the FixtureProgram/Release directory.

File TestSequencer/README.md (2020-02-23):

## Test Sequencer

This project surrounds an 8&#x2011;bit PIC microcontroller (PIC16F15324) with

1. Power supply from a DC barrel jack with both ESD and reverse polarity protection. A 5V linear regulator runs the MCU and output buffers.
2. A 32MHz external oscillator
3. A 6p6c modular jack with ESD protection for ICSP programming with an ICD3 or ICD4
4. 7 32mA capable logic&#x2011;level output buffers broken out to terminal blocks with ESD protection
5. An input for a toggle switch or pushbutton broken out to a terminal block with ESD protection
6. A slightly hacky but functional enclosure

After many times wanting to write some very basic assembly code to debounce a button and generate some simple logic&#x2011;level waveforms
to control other equipment or directly interface with a circuit under test, I decided to build a board to serve this role.

The PIC16F15324 was chosen primarily out of familiarity but also for its reasonable specs and capability (relative to this application) and for having no serious errata.

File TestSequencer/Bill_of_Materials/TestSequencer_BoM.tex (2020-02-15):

\documentclass[11pt,letterpaper]{article}
\usepackage[T1]{fontenc}
\usepackage{amsmath}
\usepackage{parskip}
\usepackage{longtable}
\usepackage{geometry}
\usepackage{titling}
\usepackage{fancyhdr}
\usepackage{lastpage}
\usepackage[math-style=ISO]{unicode-math}
\usepackage{textgreek}
\usepackage{textcomp}
%\usepackage{showframe}

\geometry{
letterpaper,
top=0.5in,
bottom=0.5in,
left=0.5in,
right=0.5in,
includefoot
}

\setlength{\droptitle}{-0.5in}
\pretitle{\begin{flushleft}}
    \posttitle{\end{flushleft}}
\preauthor{\begin{flushleft}}
    \postauthor{\end{flushleft}}
\predate{}
\date{}
\postdate{}

\pagestyle{fancy}
\fancyhf{}
\renewcommand{\headrulewidth}{0pt}
\cfoot{\thepage\ / \pageref{LastPage}}

\begin{document}
\title{Test Sequencer Rev0 Bill of Materials}
\author{2020-02-15}
\maketitle
\thispagestyle{fancy}

{\renewcommand{\arraystretch}{1.5}
\begin{longtable}{| l || l | p{2.4cm} | p{3.3cm} | p{4.5cm} |}
\hline\textbf{Part \#} & \textbf{Quantity} & \textbf{Designators} & \textbf{Manufacturer} & \textbf{Description}\\\hline\hline\endhead
CL10B104KO8NNNC & 9 & C1, C2, C6{\textendash}C11, C13 & Samsung Electro-Mechanics & 100nF {\textpm}10\% 16V X7R 0603\\\hline
HHXA500ARA470MHA0G & 1 & C3 & United Chemi-Con & 47{\textmu}F {\textpm}20\% 50V 8.3mm x 8.3mm x 10.3mm Aluminum-polymer\\\hline
CL31B105KBHNNNE & 1 & C4 & Samsung Electro-Mechanics & 1{\textmu}F {\textpm}10\% 50V X7R 1206\\\hline
CGA5L1X7R1C106K160AC & 1 & C5 & TDK & 10{\textmu}F {\textpm}10\% 16V X7R 1206\\\hline
CL10B103KO8NNNC & 2 & C12, C14 & Samsung Electro-Mechanics & 10nF {\textpm}10\% 16V X7R 0603\\\hline
PMEG60T10ELPX & 1 & D1 & Nexperia & 60V 1A SOD128 Shottky Diode\\\hline
SMAJ15CA-E3 & 1 & D2 & Vishay & Bidirectional 15V V$_{\text{WM}}$ TVS, SMA\\\hline
0685T1500-01 & 1 & F1 & Bel Fuse Inc. & 1.5A slow blow 1206 case fuse\\\hline
PJ-102AH & 1 & J1 & CUI Inc. & Jack for 2.0mm ID, 5.5mm OD barrel plug\\\hline
282837-2 & 8 & J2{\textendash}J9 & TE Connectivity & 2 position 5.08mm pitch through hole terminal block\\\hline
0438600002 & 1 & J10 & Molex & 6p6c right angle through hole RJ25 modular jack\\\hline
CRCW060310R0FKEAHP & 7 & R1, R2, R5, R6, R9, R10, R13 & Vishay Dale & 10{\textOmega} {\textpm}1\% {\textpm}100ppm/{\textdegree}C 0.33W pulse withstanding 0603\\\hline
RMCF0603JT47K0 & 7 & R3, R4, R7, R8, R11, R12, R14 & Stackpole Electronics Inc. & 47k{\textOmega} {\textpm}5\% {\textpm}200ppm/{\textdegree}C 0.1W 0603\\\hline
CRCW0603220RFKEAHP & 1 & R15 & Vishay Dale & 220{\textOmega} {\textpm}1\% {\textpm}100ppm/{\textdegree}C 0.33W pulse withstanding 0603\\\hline
CRCW060310K0JNEAHP & 2 & R16, R19 & Vishay Dale & 10k{\textOmega} {\textpm}5\% {\textpm}200ppm/{\textdegree}C 0.33W pulse withstanding 0603\\\hline
CRCW060322R0FKEAHP & 3 & R17, R20, R21 & Vishay Dale & 22{\textOmega} {\textpm}1\% {\textpm}100ppm/{\textdegree}C 0.33W pulse withstanding 0603\\\hline
ERJ-PA3F2401V & 1 & R18 & Panasonic Electronic Components & 2.4k{\textOmega} {\textpm}1\% {\textpm}100ppm/{\textdegree}C 0.25W pulse withstanding 0603\\\hline
90380A107 & 4 & S1{\textendash}S4 & McMaster-Carr & \#4-20 thread, 0.3125" long shank, 0.219" head diameter thread forming screw for plastics\\\hline
90380A005 & 6 & S5{\textendash}S10 & McMaster-Carr & \#2-28 thread, 0.25" long shank, 0.167" head diameter thread forming screw for plastics\\\hline
90380A106 & 2 & S11, S12 & McMaster-Carr & \#4-20 thread, 0.25" long shank, 0.219" head diameter thread forming screw for plastics\\\hline
DLP05LC-7-F & 11 & TVS1{\textendash}TVS7, TVS10{\textendash}TVS13 & Diodes Inc. & Low capacitance 5V V$_{\text{WM}}$ unidirectional TVS, SOT23-3\\\hline
IFX24401TEV50ATMA1 & 1 & U1 & Infineon & 45V input, 5V {\textpm}2\% output, low quiescent current, low dropout linear regulator, TO252-5\\\hline
NL17SZ17DFT2G & 7 & U2{\textendash}U8 & ON Semiconductor & 32mA capable non-inverting Schmitt trigger buffer, SC-70-5\\\hline
KC5032A32\_0000CMGE00 & 1 & U9 & Kyocera & 32MHz {\textpm}50ppm {\textminus}40{\textdegree}C to 85{\textdegree}C 5V oscillator module\\\hline
PIC16F15324-E/SN & 1 & U10 & Microchip & 4k instruction word, 512 byte RAM, 32MHz / 8MIPS 8-bit MCU, 14-SOIC\\\hline
\end{longtable}}
\end{document}

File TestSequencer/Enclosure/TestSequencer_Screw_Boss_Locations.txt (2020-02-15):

board width: 178mm
board depth: 72mm

#4 screw has 2.2mm dia hole, 7.5mm dia support.
#2 screw has 1.6mm dia hole, 5.8mm dia support.
boss has 6mm dia support, 3mm dia 2mm tall post

#2 screw coordinates relative to board southwest corner
+X points east; +Y points north. Units: mm.
  S5:  135.5, 5
  S6:  5, 5
  S7:  103, 5
  S8:  37, 5
  S9:  173.4, 5
  S10: 70, 5

boss coordinates relative to board southwest corner
+X points east; +Y points north. Units: mm.
  B1: 151.5, 11
  B2: 86.5, 5
  B3: 53.5, 5
  B4: 20.5, 5
  B5: 119, 5

#4 screw coordinates relative to board southwest corner
+X points east; +Y points north. Units: mm.
  S1:  41, 19.5
  S2:  132, 19.5
  S3:  41, 65.5
  S4:  132, 65.5
  S11: 10, 62
  S12: 168, 62

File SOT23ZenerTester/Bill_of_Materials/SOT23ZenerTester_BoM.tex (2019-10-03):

\documentclass[11pt,letterpaper]{article}
\usepackage[T1]{fontenc}
\usepackage{amsmath}
\usepackage{parskip}
\usepackage{longtable}
\usepackage{geometry}
\usepackage{titling}
\usepackage{fancyhdr}
\usepackage{lastpage}
\usepackage[math-style=ISO]{unicode-math}
\usepackage{textgreek}
\usepackage{textcomp}
%\usepackage{showframe}

\geometry{
letterpaper,
top=0.5in,
bottom=0.5in,
left=0.5in,
right=0.5in,
includefoot
}

\setlength{\droptitle}{-0.5in}
\pretitle{\begin{flushleft}}
    \posttitle{\end{flushleft}}
\preauthor{\begin{flushleft}}
    \postauthor{\end{flushleft}}
\predate{}
\date{}
\postdate{}

\pagestyle{fancy}
\fancyhf{}
\renewcommand{\headrulewidth}{0pt}
\cfoot{\thepage\ / \pageref{LastPage}}

\begin{document}
\title{SOT23 Zener Tester Rev1 Bill of Materials}
\author{2019-10-02}
\maketitle
\thispagestyle{fancy}

{\renewcommand{\arraystretch}{1.5}
\begin{longtable}{| l || l | p{2.4cm} | p{3.3cm} | p{4.5cm} |}
\hline\textbf{Part \#} & \textbf{Quantity} & \textbf{Designators} & \textbf{Manufacturer} & \textbf{Description}\\\hline\hline\endhead
PJ-102AH & 1 & J1 & CUI Inc. & Jack for 2.1mm ID, 5.5mm OD barrel plug\\\hline
0679L0375-05‎ & 1 & F1 & Bourns & 375mA 125V 0.04$\text{A}^{2}\text{s}$ fast fuse, 2410 case\\\hline
SMBJ13CA‎ & 1 & D2 & Taiwan Semiconductor & 13V V$_{\text{WM}}$ bidirectional TVS diode, SMB case\\\hline
NRVTSA4100ET3G‎ & 1 & D1 & ON Semiconductor & 100V low leakage, low V$_{\text{F}}$ Schottky diode, SMA case\\\hline
HHXC350ARA680MF80G‎ & 1 & C1 & Nippon Chemi-Con & 68{\textmu}F, 35V, 125{\textdegree}C, polymer hybrid aluminum electrolytic capacitor\\\hline
282837-3 & 1 & J2 & TE Connectivity & 3 position, 5.08mm pitch, through hole terminal block\\\hline
282837-4 & 1 & J4 & TE Connectivity & 4 position, 5.08mm pitch, through hole terminal block\\\hline
L17HTHAS4F1C & 1 & J3 & Amphenol & Female, right angle, through hole, 26 position HD DSUB connector\\\hline
YR1B100RCC & 1 & R1 & TE Connectivity & 100{\textOmega} {\textpm}0.1\% {\textpm}15ppm/{\textdegree}C 0.25W through hole resistor\\\hline
YR1B1K0CC & 1 & R2 & TE Connectivity & 1k{\textOmega} {\textpm}0.1\% {\textpm}15ppm/{\textdegree}C 0.25W through hole resistor\\\hline
YR1B10KCC & 1 & R3 & TE Connectivity & 10k{\textOmega} {\textpm}0.1\% {\textpm}15ppm/{\textdegree}C 0.25W through hole resistor\\\hline
YR1B100KCC & 1 & R4 & TE Connectivity & 100k{\textOmega} {\textpm}0.1\% {\textpm}15ppm/{\textdegree}C 0.25W through hole resistor\\\hline
YR1B1M0CC & 1 & R5 & TE Connectivity & 1M{\textOmega} {\textpm}0.1\% {\textpm}15ppm/{\textdegree}C 0.25W through hole resistor\\\hline
PESD5V0L1UA & 15 & D3{\textendash}D17 & Nexperia & 5V V$_{\text{WM}}$ low capacitance TVS diode, SOD323 case\\\hline
PDTC123JT & 15 & Q1{\textendash}Q15 & Nexperia & Pre-biased 50V V$_{\text{CE}}$ NPN transistor 2.2k{\textOmega}/47k{\textOmega}, SOT23{\textendash}3 case\\\hline
3570.1331.123 & 15 & RLY1{\textendash}RLY15 & COMUS & SPST reed relay, 12V coil, integrated diode\\\hline
{\textemdash} & 5 & J5{\textendash}J9 & CSD Technology Limited & Dual SOT23{\textendash}3 ZIF Socket. Ali Express item 32729140003\\\hline
90380A008 & 18 & S1{\textendash}S18 & McMaster-Carr & \#2-28 thread, 0.3125" long shank, 0.167" head diameter thread forming screw for plastics\\\hline
\end{longtable}}

\end{document}

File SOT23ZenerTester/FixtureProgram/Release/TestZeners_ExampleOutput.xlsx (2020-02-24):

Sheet: J5L
PSU Voltage Setting (V) | Measured PSU Voltage (V) | Measured Zener Voltage (V) | Nominal Test Resistance (Ohms) | Calculated Zener Current (A)
2.000 | 1.997160 | 1.956224 | 1000000.0
3.000 | 2.997470 | 2.483536 | 1000000.0
4.000 | 3.996620 | 2.707873 | 1000000.0
5.000 | 4.996960 | 2.842568 | 1000000.0
6.000 | 5.997140 | 2.938680 | 1000000.0
7.000 | 6.997570 | 3.013511 | 1000000.0
8.000 | 7.997860 | 3.074857 | 1000000.0
9.000 | 8.998220 | 3.126930 | 1000000.0
10.000 | 9.998500 | 3.172201 | 1000000.0
11.000 | 10.998700 | 3.212293 | 1000000.0
12.000 | 11.997800 | 3.248236 | 1000000.0
13.000 | 12.998100 | 3.280904 | 1000000.0
14.000 | 13.998500 | 3.310823 | 1000000.0
15.000 | 14.998600 | 3.338428 | 1000000.0
16.000 | 15.999000 | 3.364073 | 1000000.0
17.000 | 16.999200 | 3.388004 | 1000000.0
18.000 | 17.999600 | 3.410449 | 1000000.0
19.000 | 18.999900 | 3.431584 | 1000000.0
20.000 | 19.998900 | 3.451537 | 1000000.0
21.000 | 20.999200 | 3.470479 | 1000000.0
22.000 | 21.999400 | 3.488482 | 1000000.0
23.000 | 22.999700 | 3.505636 | 1000000.0
24.000 | 24.000000 | 3.522033 | 1000000.0
25.000 | 25.000000 | 3.537725 | 1000000.0
26.000 | 26.000300 | 3.552781 | 1000000.0
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

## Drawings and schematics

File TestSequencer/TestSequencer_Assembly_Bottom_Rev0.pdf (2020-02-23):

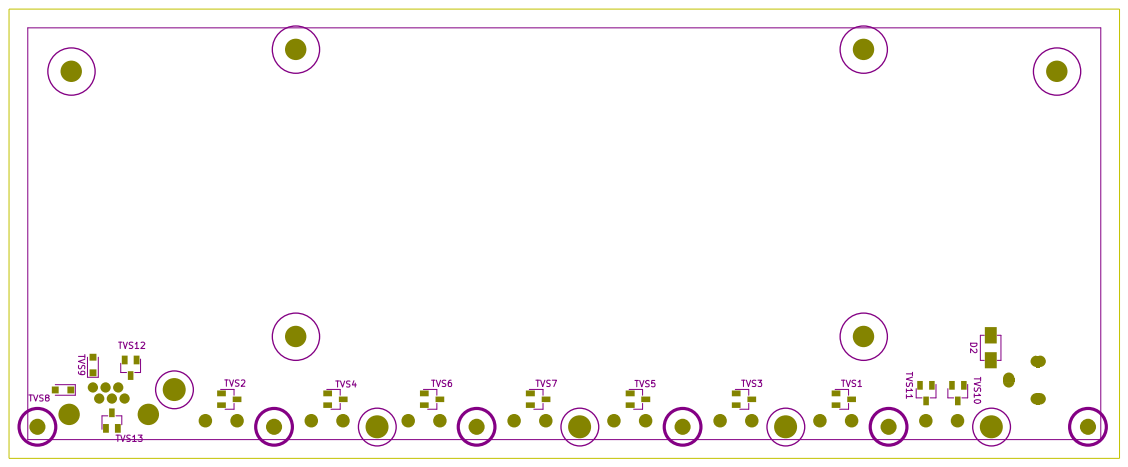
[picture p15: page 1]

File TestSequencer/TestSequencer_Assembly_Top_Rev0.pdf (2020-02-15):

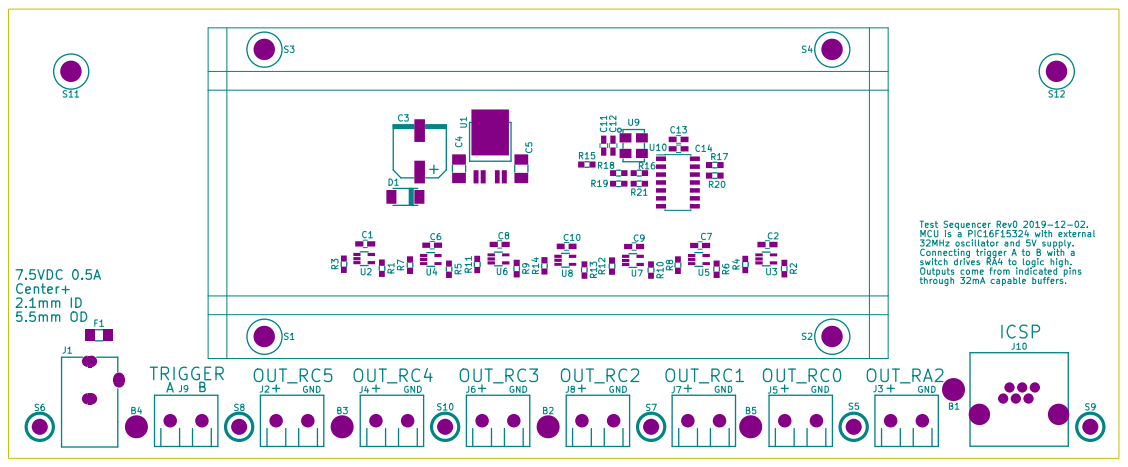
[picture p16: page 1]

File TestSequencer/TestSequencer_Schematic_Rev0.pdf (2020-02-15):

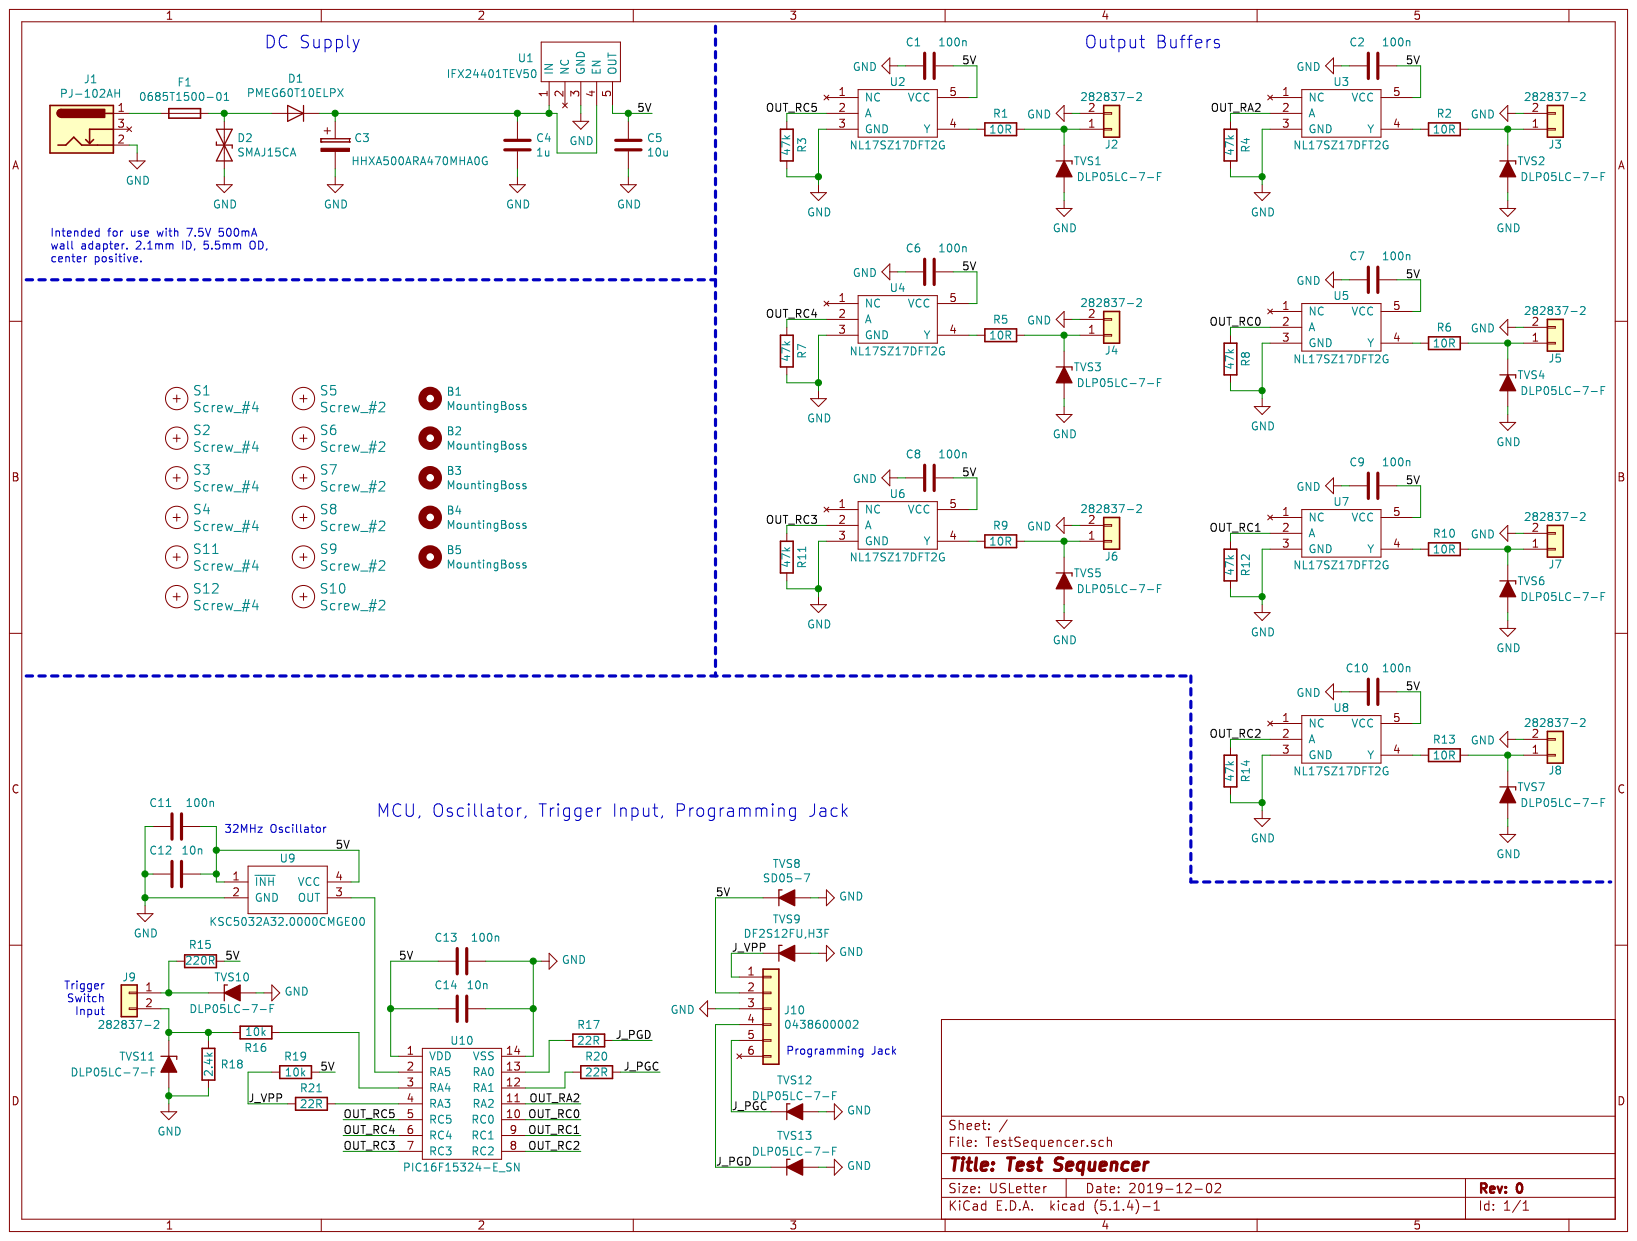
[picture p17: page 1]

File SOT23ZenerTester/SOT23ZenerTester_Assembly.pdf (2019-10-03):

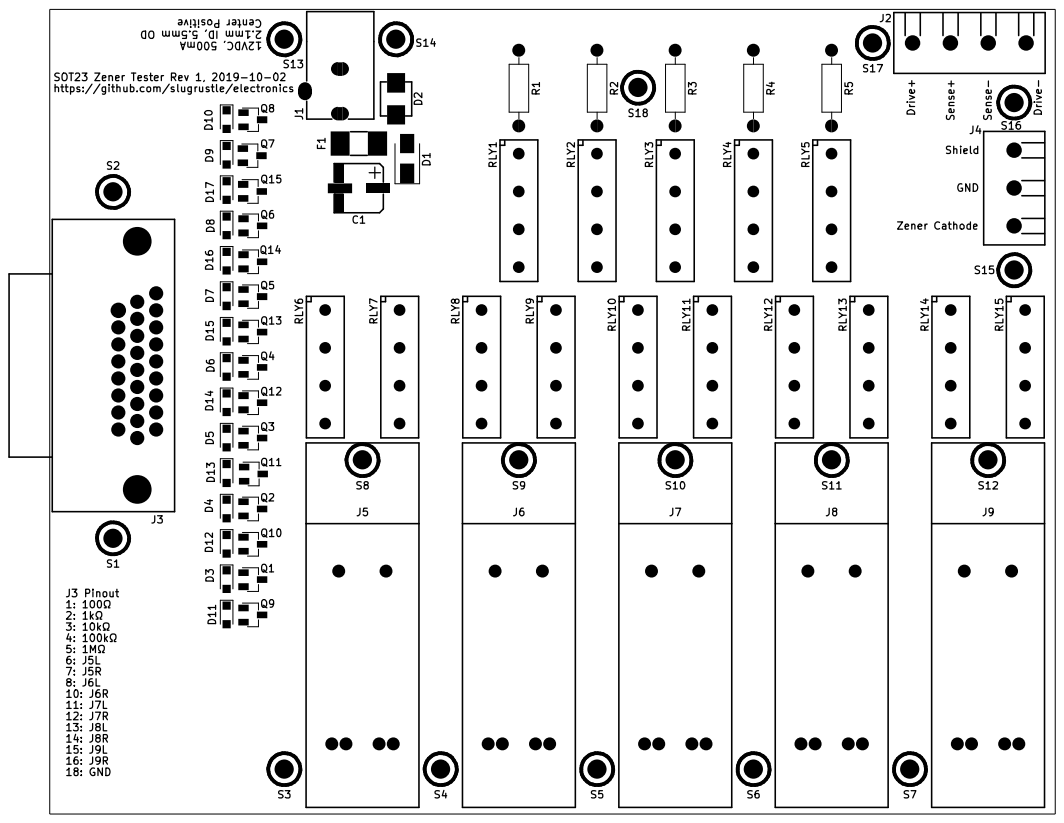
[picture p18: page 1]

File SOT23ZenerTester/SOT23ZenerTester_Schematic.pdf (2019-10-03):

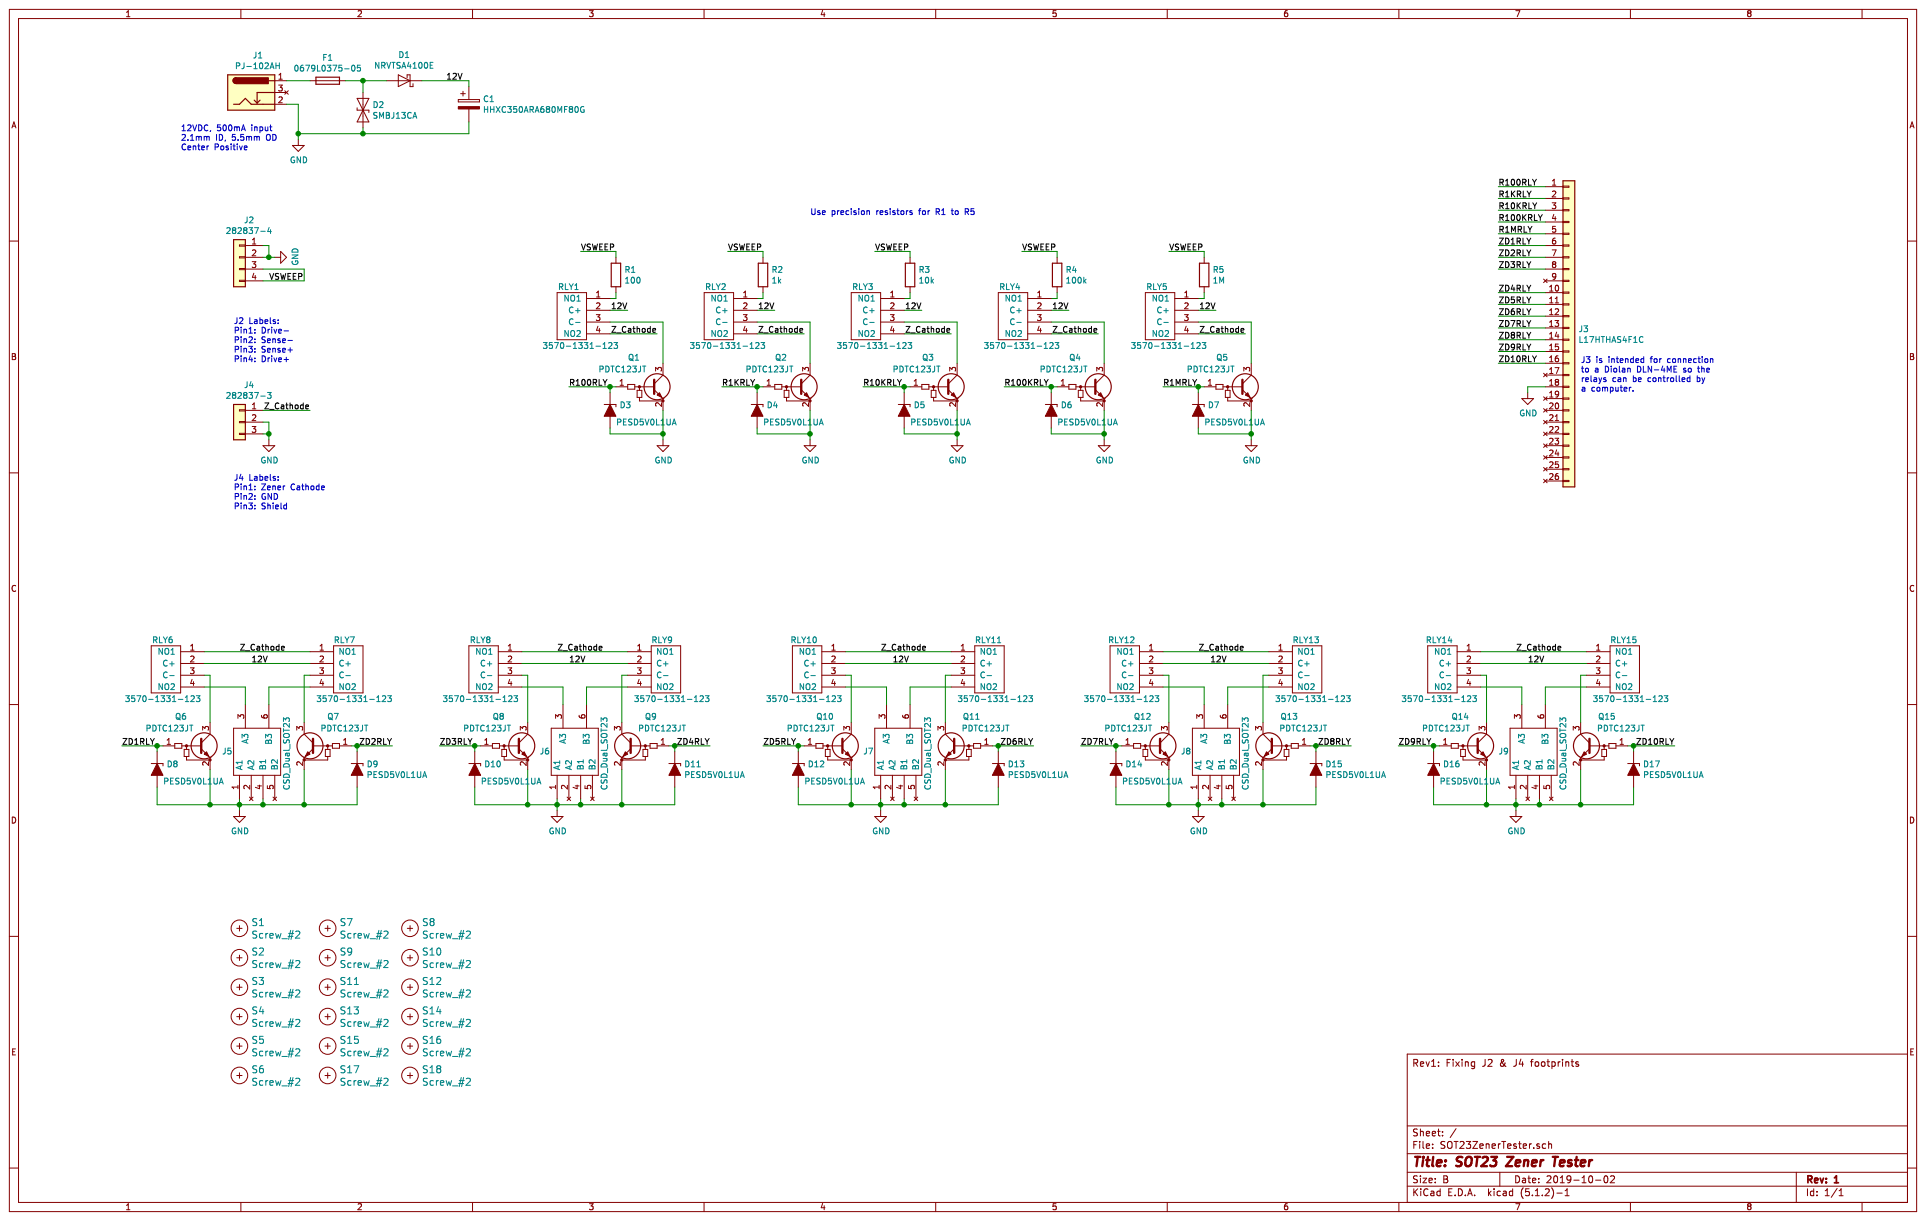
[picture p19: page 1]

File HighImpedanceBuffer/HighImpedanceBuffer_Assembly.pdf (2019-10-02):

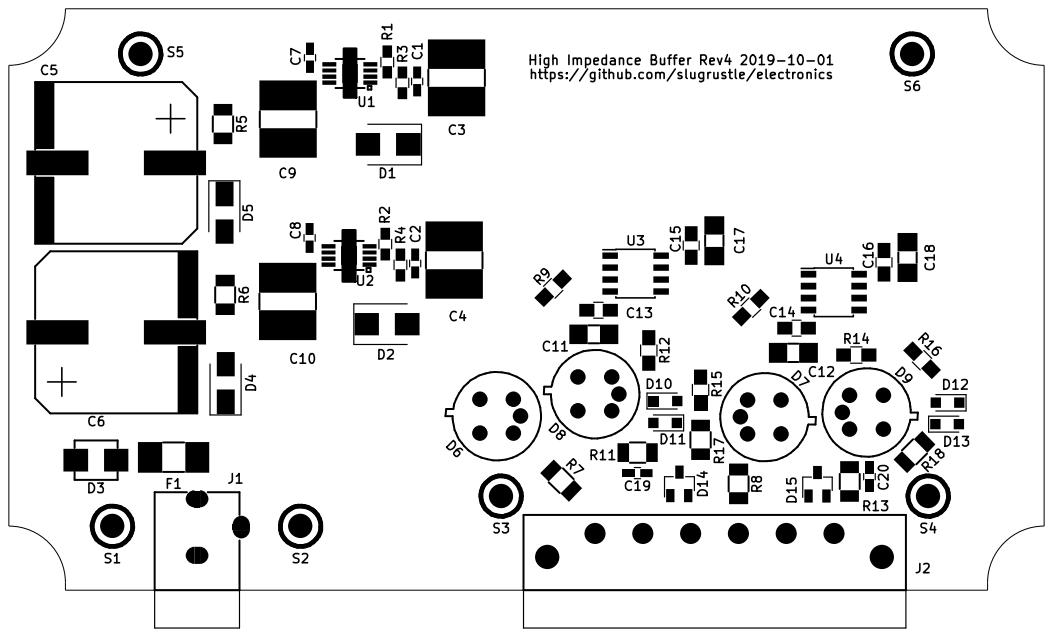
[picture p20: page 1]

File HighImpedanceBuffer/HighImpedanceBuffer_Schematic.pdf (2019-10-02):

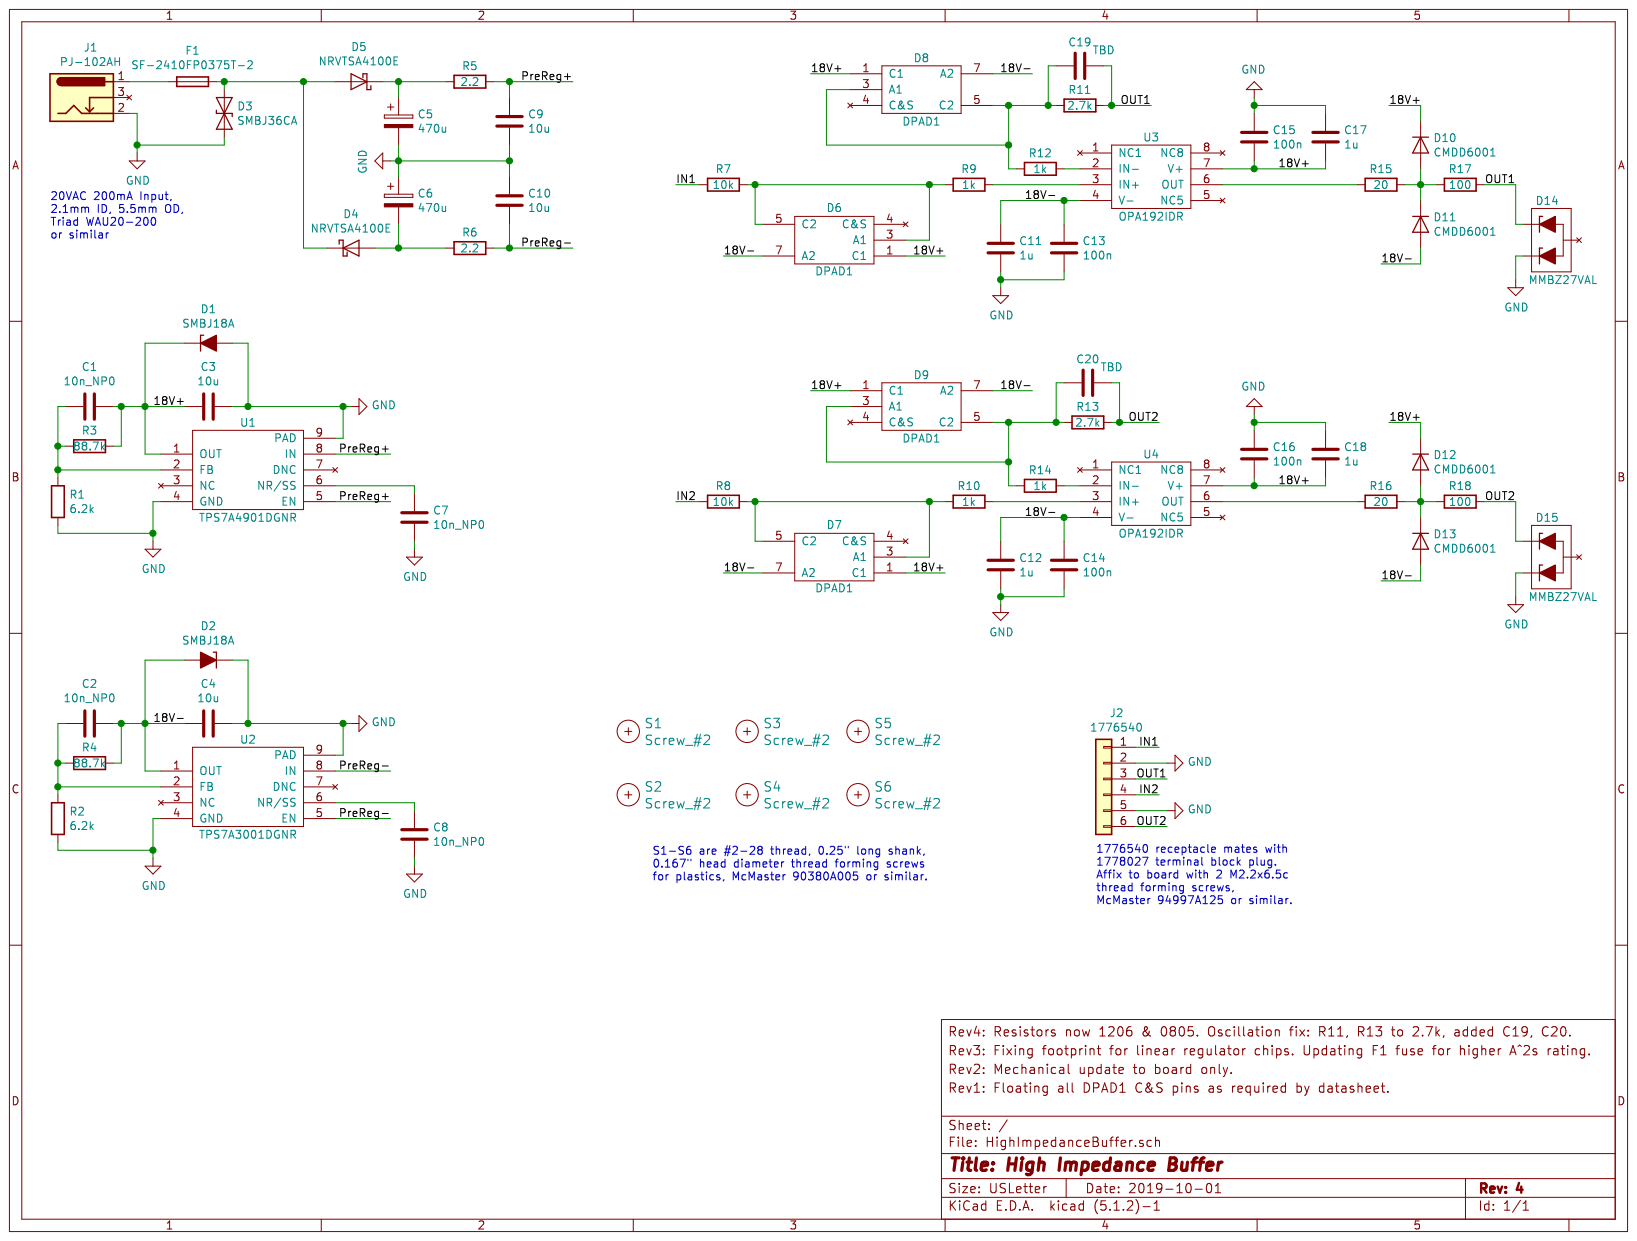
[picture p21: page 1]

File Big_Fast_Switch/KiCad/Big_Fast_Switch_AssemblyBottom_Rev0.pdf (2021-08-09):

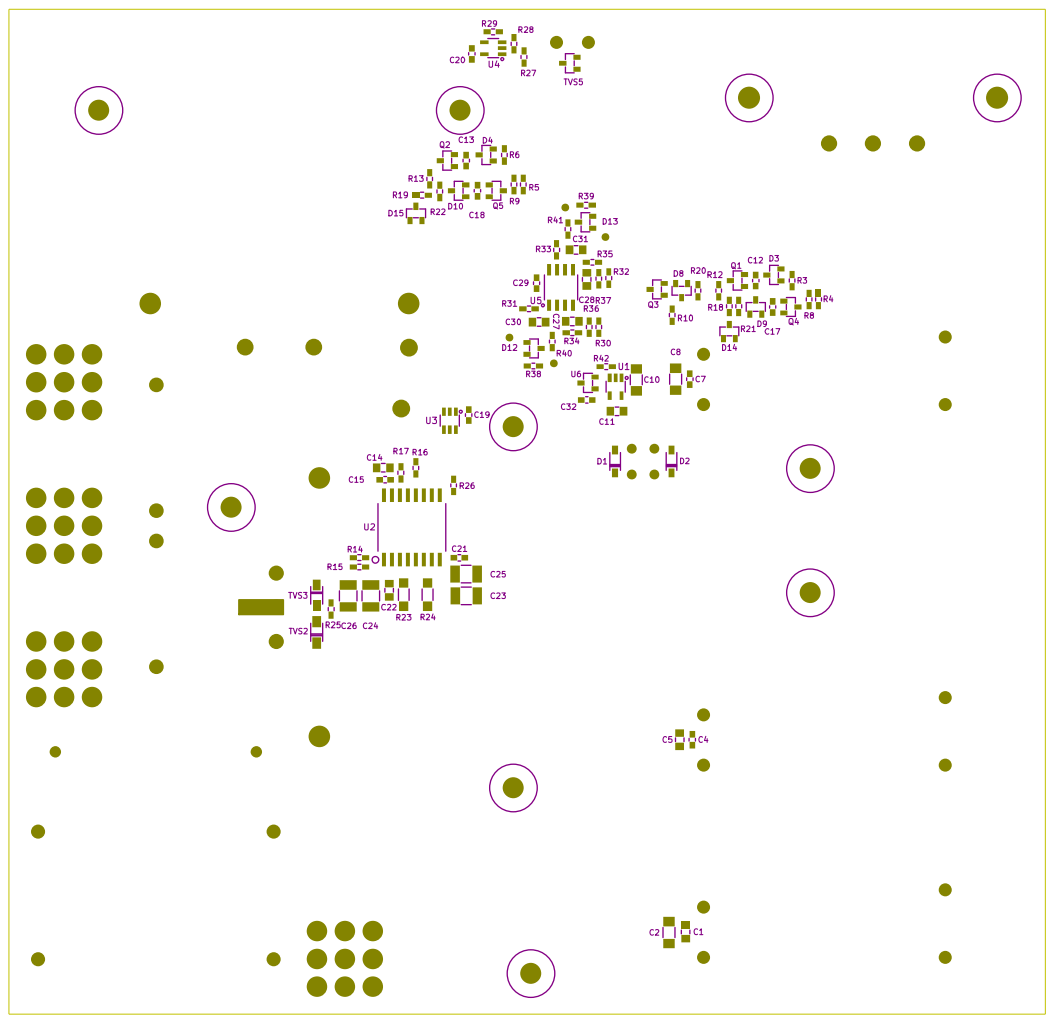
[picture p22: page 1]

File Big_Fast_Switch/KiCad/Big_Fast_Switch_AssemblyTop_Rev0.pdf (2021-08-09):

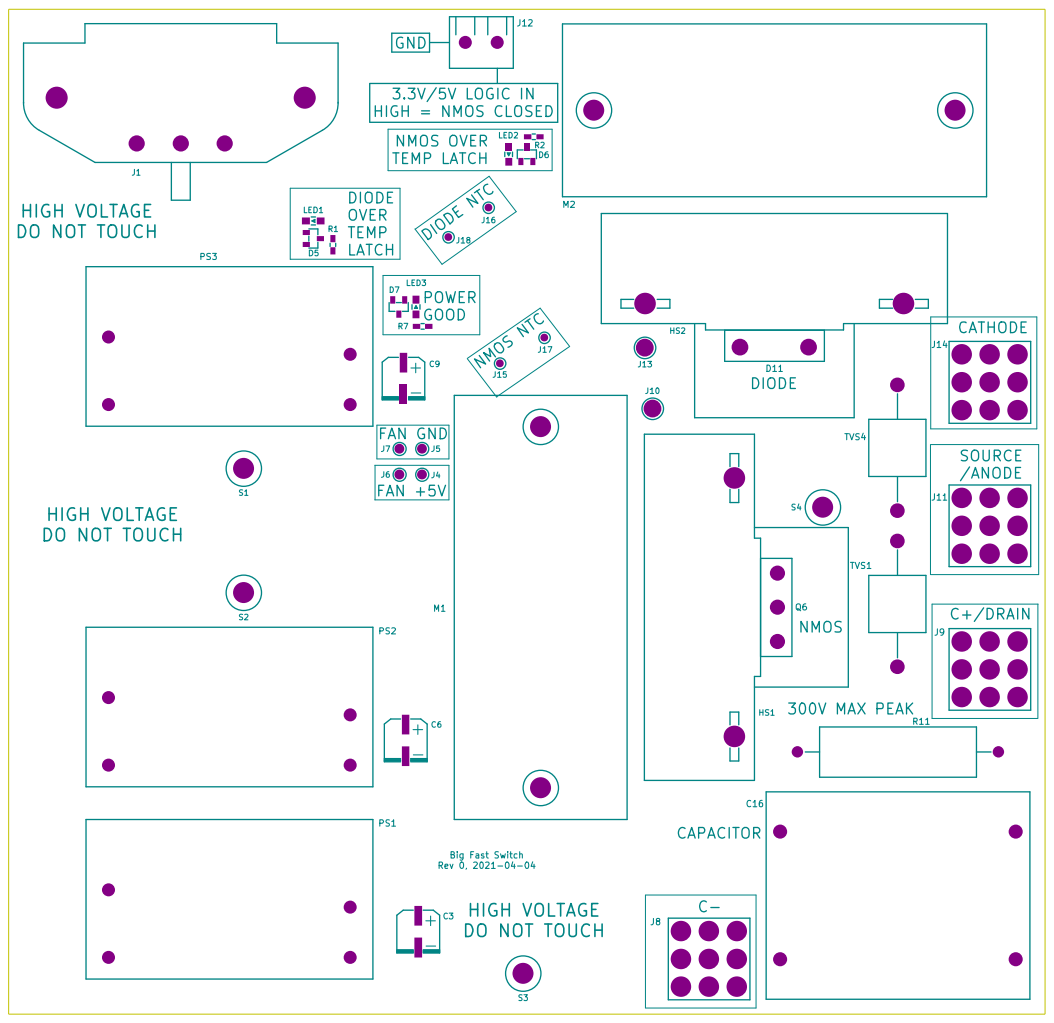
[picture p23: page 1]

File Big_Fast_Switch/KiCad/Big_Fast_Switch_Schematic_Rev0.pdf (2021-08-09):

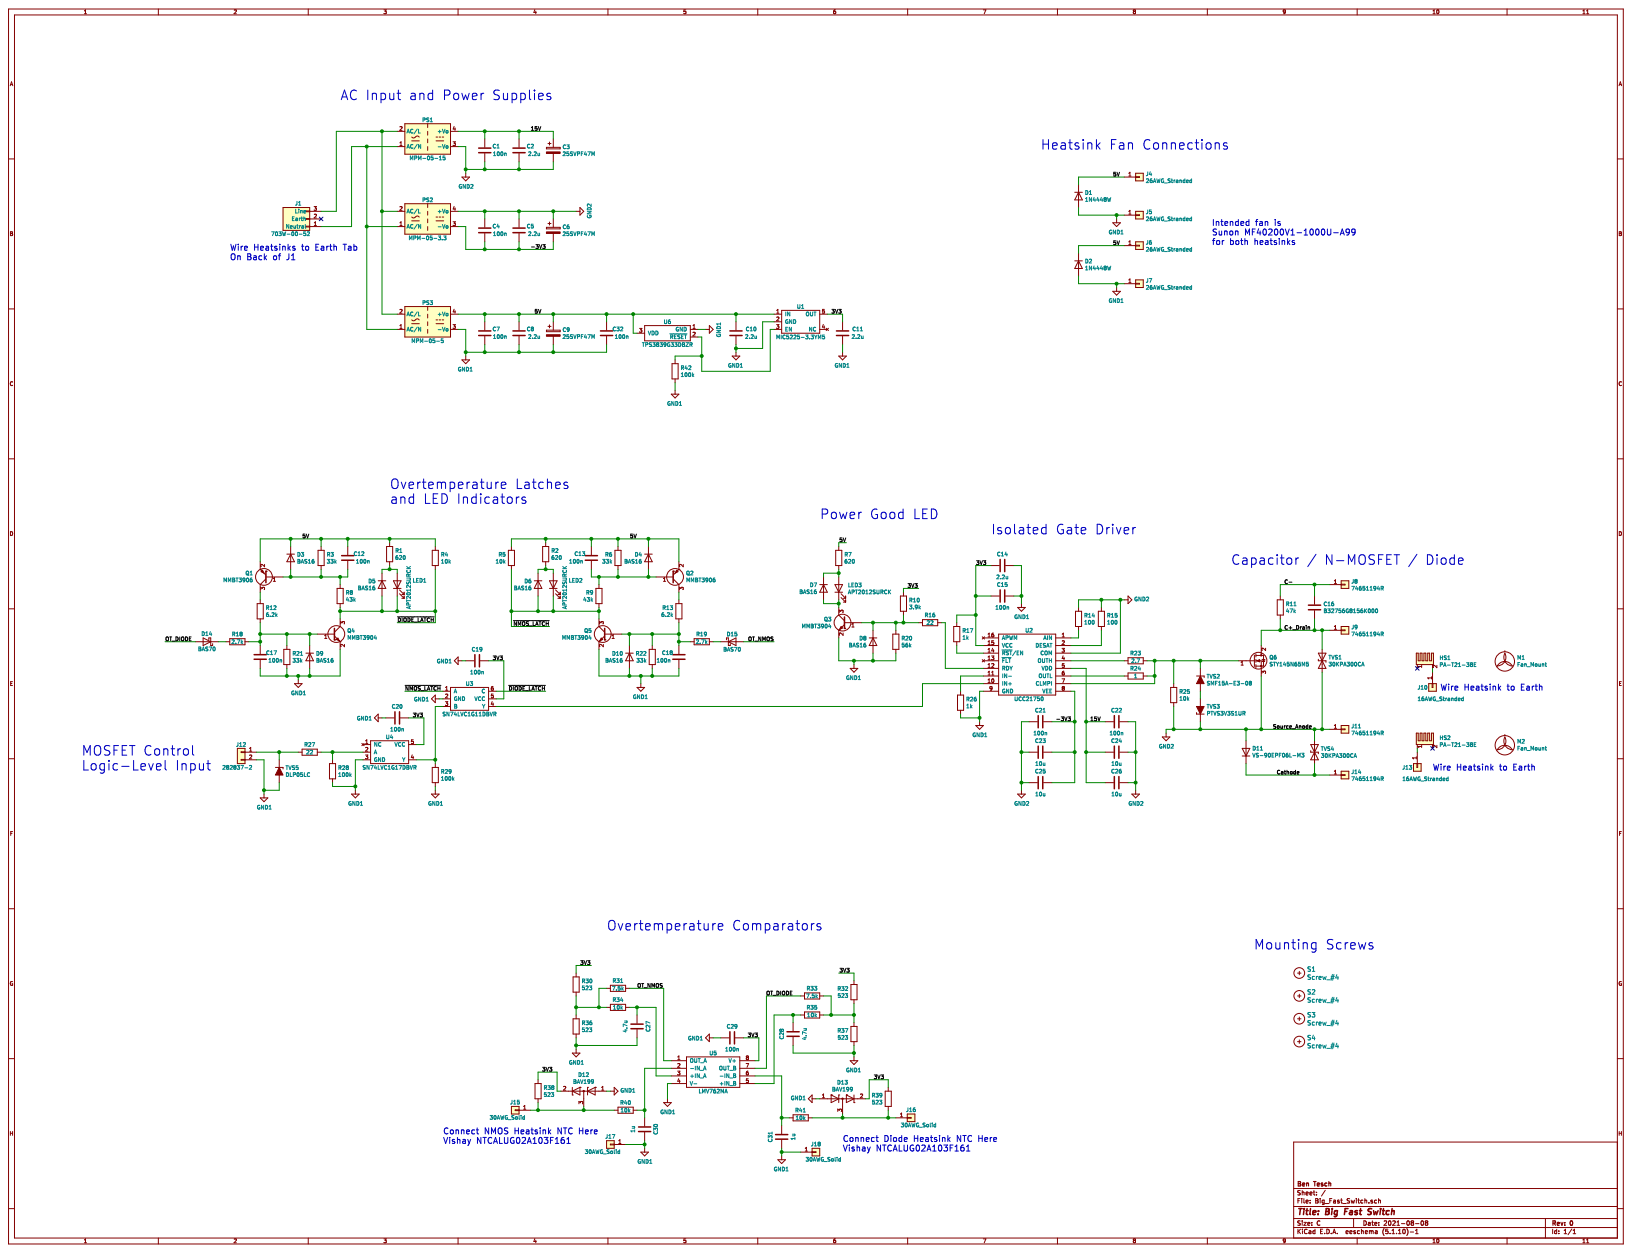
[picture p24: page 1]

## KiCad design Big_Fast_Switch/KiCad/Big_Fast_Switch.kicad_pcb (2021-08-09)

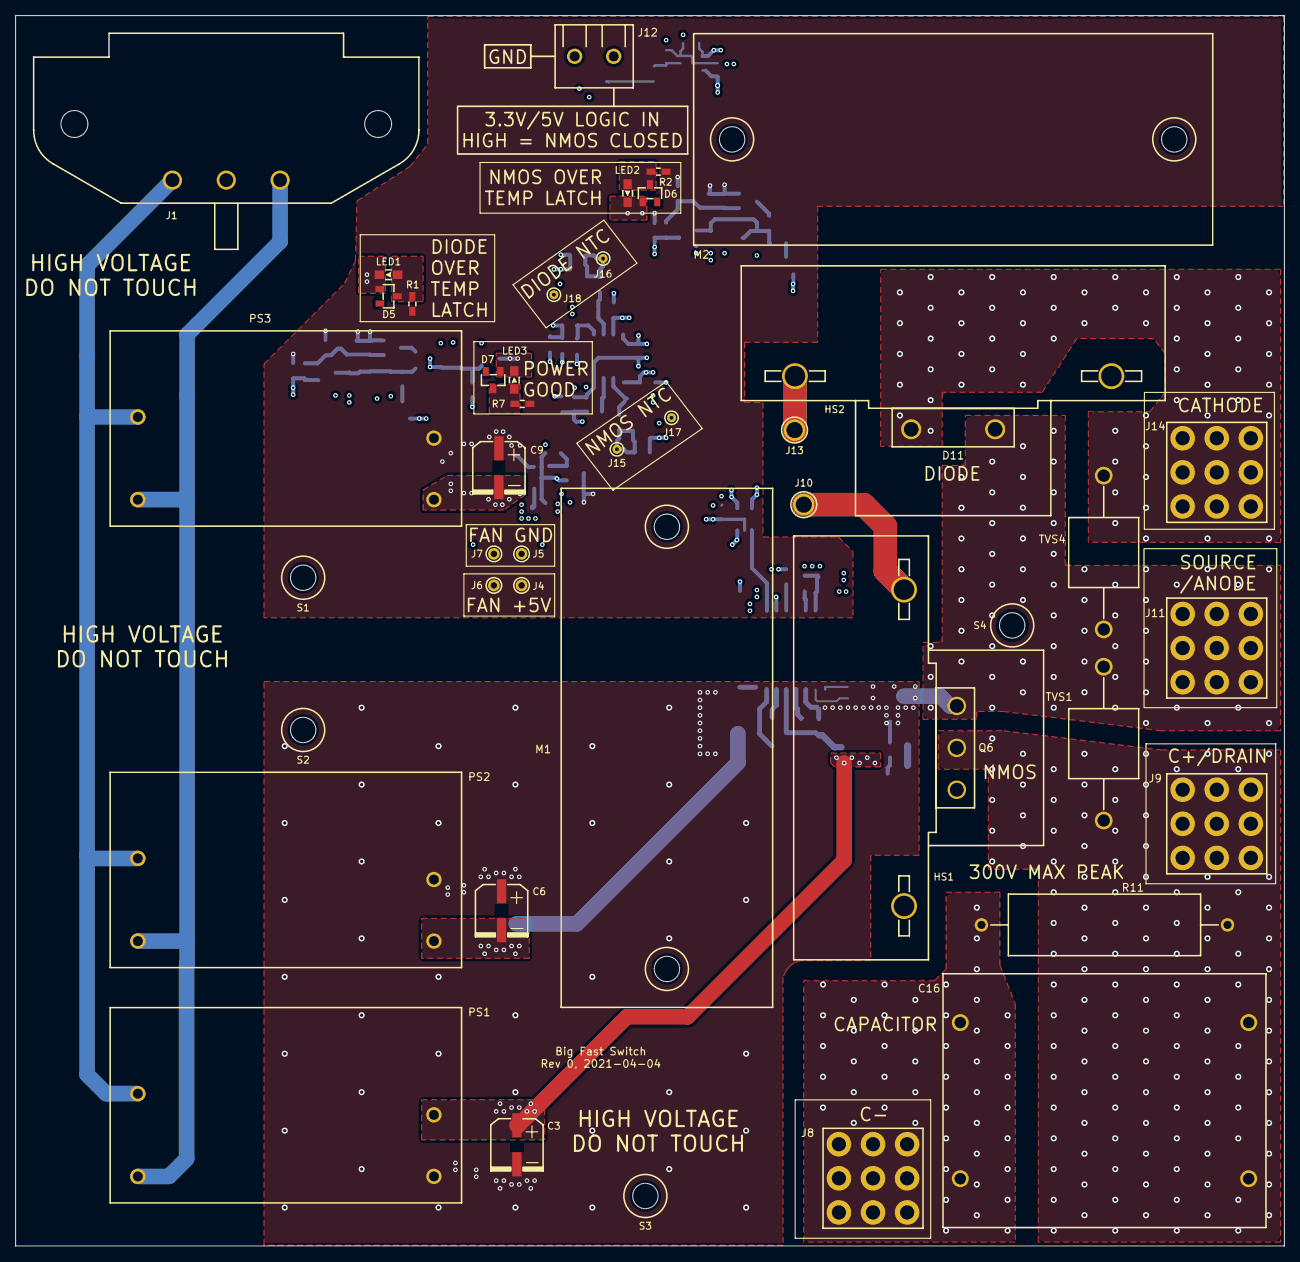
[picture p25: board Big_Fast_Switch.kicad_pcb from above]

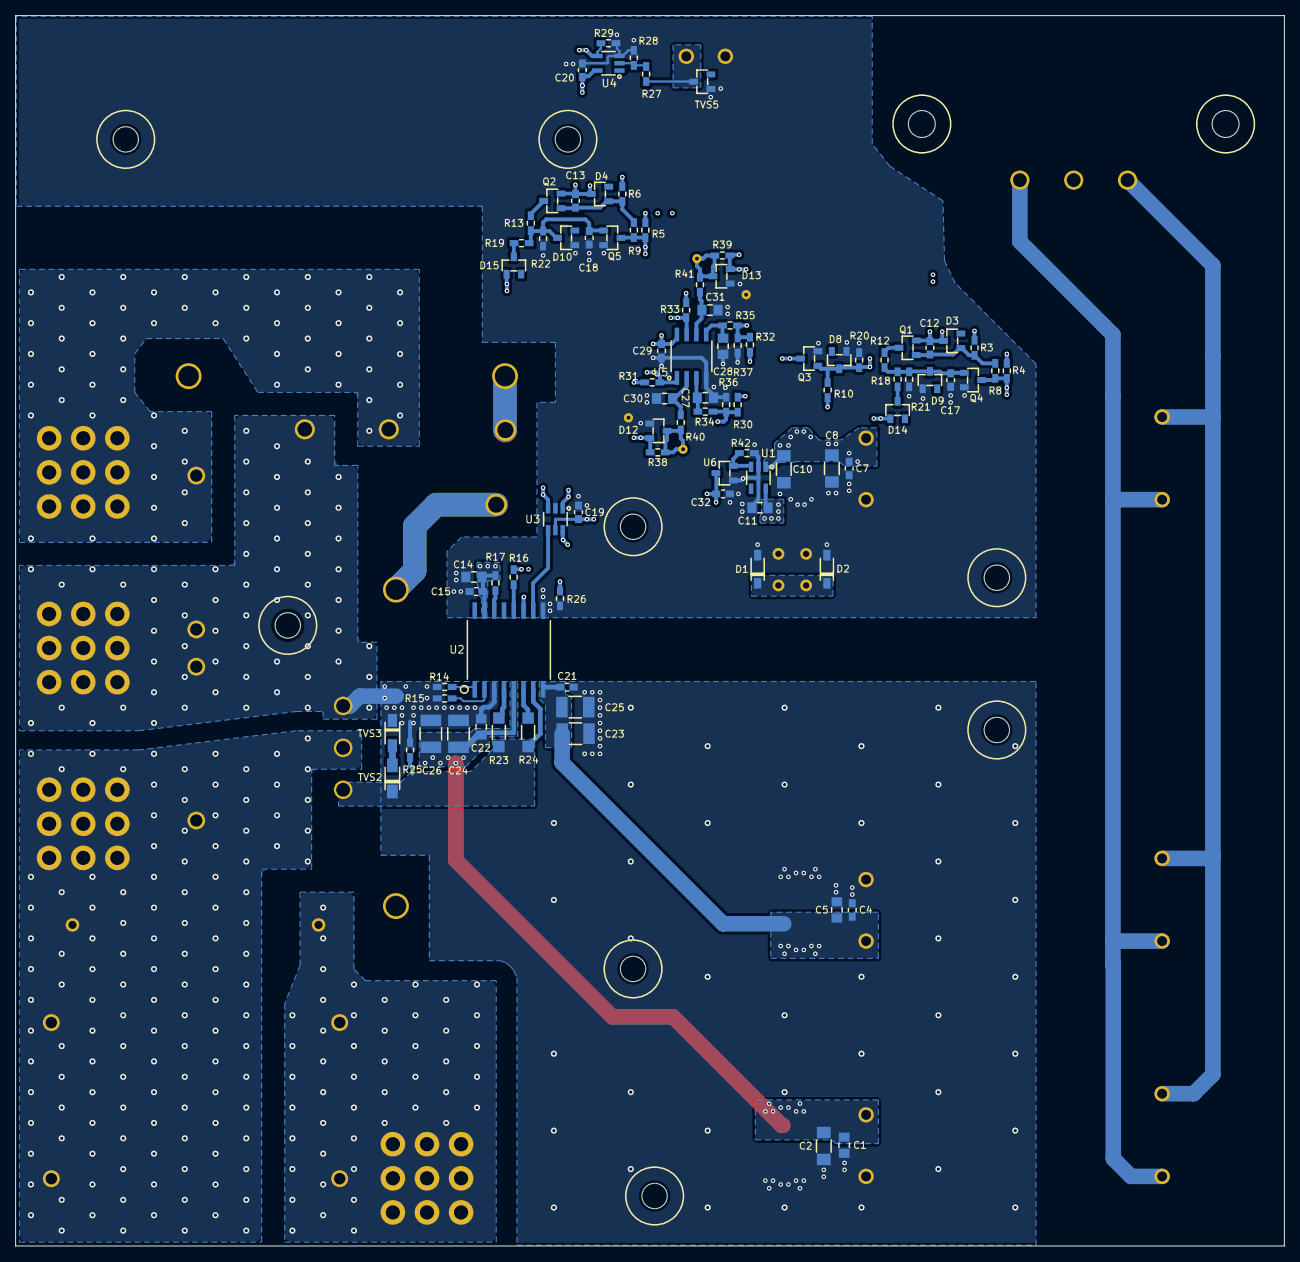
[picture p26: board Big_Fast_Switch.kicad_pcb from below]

Board: 4 copper layers, 165.0 x 160.0 mm, 136 parts (91 on the bottom side), 52 nets.

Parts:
C1, C22: 100n; C0805
C2, C8, C10: 2.2u; C1206
C3, C6, C9: 25SVPF47M; SVPF_C26
C4, C7, C15, C19, C20, C21, C29, C32: 100n; C0603
C5, C11, C14: 2.2u; C0805
C12, C13, C17, C18: 10n; C0603
C16: B32756G8156K000; B32756G
C23, C24, C25, C26: 10u; C1210
C27, C28: 4.7u; C0805
C30, C31: 1u; C0805
D1, D2: 1N4448W; SOD-123
D3, D4, D5, D6, D7, D8, D9, D10: BAS16; SOT-23-3
D11: VS-90EPF06L-M3; TO-247AD_2L
D12, D13: BAV199; SOT-23-3
D14, D15: BAS70; SOT-23-3
HS1, HS2: PA-T21-38E
J1: 703W-00-52
J4, J5, J6, J7: 26AWG_Stranded
J8, J9, J11, J14: 74651194R
J10, J13: 16AWG_Stranded
J12: 282837-2
J15, J16, J17, J18: 30AWG_Solid
LED1, LED2, LED3: APT2012SURCK
M1, M2: Fan_Mount
PS1: MPM-05-15; MPM-05
PS2: MPM-05-3.3; MPM-05
PS3: MPM-05-5; MPM-05
Q1, Q2: MMBT3906; SOT-23-3
Q3, Q4, Q5: MMBT3904; SOT-23-3
Q6: STY145N65M5; MAX247
R1, R2, R7: 620; R0603
R3, R6, R21, R22: 33k; R0603
R4, R5, R25, R34, R35, R40, R41: 10k; R0603
R8, R9: 43k; R0603
R10: 3.9k; R0603
R11: 47k; ROX5S
R12, R13: 6.2k; R0603
R14, R15: 100; R0603
R16, R27: 22; R0603
R17, R26: 1k; R0603
R18, R19: 2.7k; R0603
R20: 56k; R0603
R23: 2.7; R1206
R24: 1; R1206
R28, R29, R42: 100k; R0603
R30, R32, R36, R37, R38, R39: 523; R0603
R31, R33: 7.5k; R0603
S1, S2, S3, S4: Screw_#4
TVS1, TVS4: 30KPA300CA; 30KPA_Bidir
TVS2: SMF15A-E3-08; SMF
TVS3: PTVS3V3S1UR; SOD-123W
TVS5: DLP05LC; SOT-23-3
U1: MIC5225-3.3YM5; SOT-23-5
U2: UCC21750; UCC21750DW
U3: SN74LVC1G11DBVR; SOT-23-6
U4: SN74LVC1G17DBVR; SOT-23-5
U5: LMV762MA; SOIC-8
U6: TPS3839G33DBZR; SOT-23-3

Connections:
/3V3: C11.2, C14.2, C15.2, C19.1, C20.1, C29.1, D12.2, D13.2, R10.1, R17.1, R30.1, R32.1, R38.1, R39.1, U1.5, U2.15, U3.5, U4.5, U5.8
/5V: C7.2, C8.2, C9.1, C10.2, C12.2, C13.2, C32.2, D1.1, D2.1, D3.3, D4.3, J4.1, J6.1, PS3.4, Q1.2, Q2.2, R1.1, R2.1, R3.1, R4.1, R5.1, R6.1, R7.1, U1.1, U6.3
/15V: C1.2, C2.2, C3.1, C22.2, C24.2, C26.2, PS1.4, U2.5
/-3V3: C4.1, C5.1, C6.2, C21.1, C23.1, C25.1, PS2.3, U2.8
/C+_Drain: C16.2, J9.1, Q6.2, R11.2, TVS1.1
/C-: C16.1, J8.1, R11.1
/Cathode: D11.1, J14.1, TVS4.2
/OT_DIODE: D14.1, R33.1, U5.7
/OT_NMOS: D15.1, R31.1, U5.1
/~DIODE_LATCH: D5.1, LED1.1, Q4.3, R4.2, R8.2, U3.6
/~NMOS_LATCH: D6.1, LED2.1, Q5.3, R5.2, R9.2, U3.1
GND1: C7.1, C8.1, C9.2, C10.1, C11.1, C14.1, C15.1, C17.1, C18.1, C19.2, C20.2, C27.1, C28.1, C29.2, C30.1, C31.1, C32.1, D1.2, D2.2, D8.1, D9.1, D10.1, D12.1, D13.1, J5.1, J7.1, J12.2, J17.1, J18.1, PS3.3, Q3.2, Q4.2, Q5.2, R20.2, R21.2, R22.2, R26.2, R28.2, R29.2, R36.2, R37.2, R42.2, TVS5.1, U1.2, U2.9, U3.2, U4.3, U5.4, U6.1
GND2: C1.1, C2.1, C3.2, C4.2, C5.2, C6.1, C21.2, C22.1, C23.2, C24.1, C25.2, C26.1, D11.2, J11.1, PS1.3, PS2.4, Q6.3, R14.1, R15.1, R25.2, TVS1.2, TVS3.1, TVS4.1, U2.3
unnamed: C12.1, D3.1, Q1.1, R3.2, R8.1
unnamed: C13.1, D4.1, Q2.1, R6.2, R9.1
unnamed: C17.2, D9.3, Q4.1, R12.2, R18.1, R21.1
unnamed: C18.2, D10.3, Q5.1, R13.2, R19.1, R22.1
unnamed: C27.2, R34.1, U5.3
unnamed: C28.2, R35.1, U5.5
unnamed: C30.2, R40.1, U5.2
unnamed: C31.2, R41.1, U5.6
unnamed: D5.3, LED1.2, R1.2
unnamed: D6.3, LED2.2, R2.2
unnamed: D7.1, LED3.1, Q3.3
unnamed: D7.3, LED3.2, R7.2
unnamed: D8.3, Q3.1, R10.2, R16.2, R20.1
unnamed: D12.3, J15.1, R38.2, R40.2
unnamed: D13.3, J16.1, R39.2, R41.2
unnamed: D14.3, R18.2
unnamed: D15.3, R19.2
unnamed: HS1.2, J10.1
unnamed: HS2.1, J13.1
unnamed: J1.1, PS1.1, PS2.1, PS3.1
unnamed: J1.3, PS1.2, PS2.2, PS3.2
unnamed: J12.1, R27.2, TVS5.3
unnamed: Q1.3, R12.1
unnamed: Q2.3, R13.1
unnamed: Q6.1, R23.1, R24.1, R25.1, TVS2.1, U2.7
unnamed: R14.2, U2.1
unnamed: R15.2, U2.2
unnamed: R16.1, U2.12
unnamed: R17.2, U2.14
unnamed: R23.2, U2.4
unnamed: R24.2, U2.6
unnamed: R26.1, U2.11
unnamed: R27.1, R28.1, U4.2
unnamed: R29.1, U3.3, U4.4
unnamed: R30.2, R31.2, R34.2, R36.1
unnamed: R32.2, R33.2, R35.2, R37.1
unnamed: R42.1, U1.3, U6.2
unnamed: TVS2.2, TVS3.2
unnamed: U2.10, U3.4

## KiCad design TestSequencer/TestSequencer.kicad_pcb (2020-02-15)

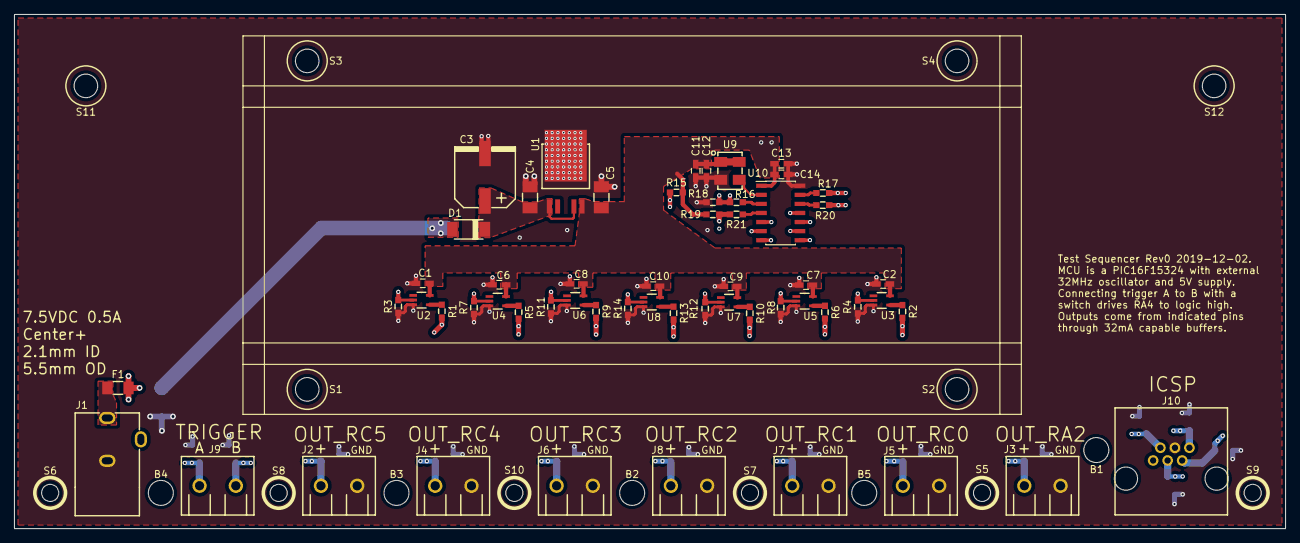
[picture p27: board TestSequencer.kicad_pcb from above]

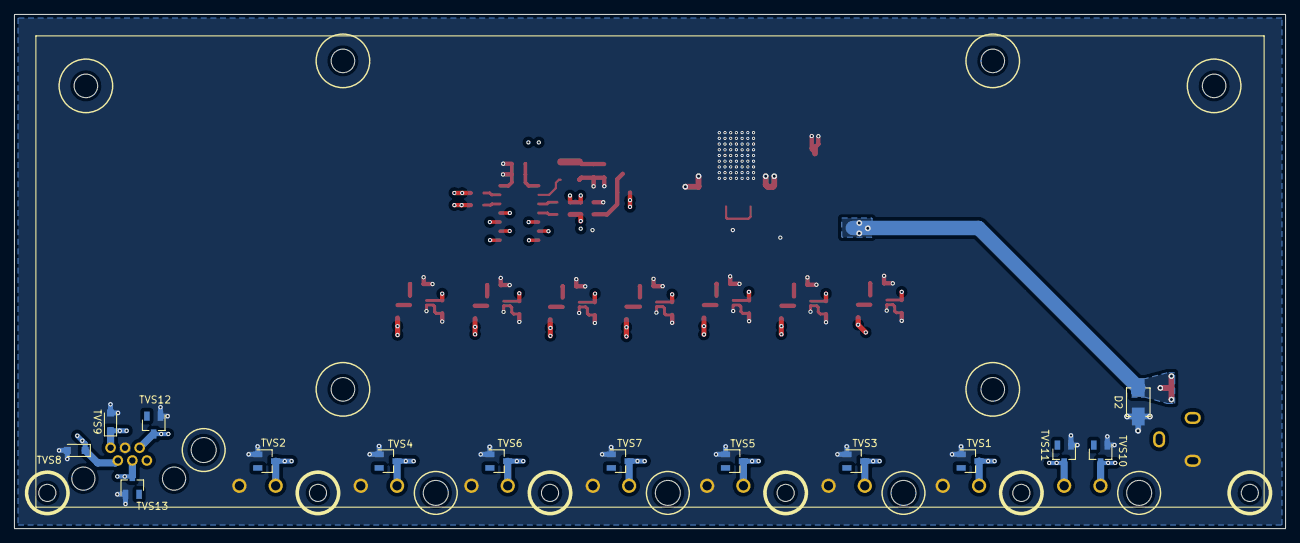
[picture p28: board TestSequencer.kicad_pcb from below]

Board: 4 copper layers, 178.0 x 72.0 mm, 88 parts (14 on the bottom side), 36 nets.

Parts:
B1, B2, B3, B4, B5: MountingBoss
C1, C2, C6, C7, C8, C9, C10, C11, C13: 100n; C_0603_HandSoldering
C3: HHXA500ARA470MHA0G; HXA_HA0
C4: 1u; C_1206
C5: 10u; C_1206
C12, C14: 10n; C_0603_HandSoldering
D1: PMEG60T10ELPX; SOD-128
D2: SMAJ15CA; D_SMA_Bidir
F1: 0685T1500-01; F_1206
J1: PJ-102AH
J2, J3, J4, J5, J6, J7, J8, J9: 282837-2
J10: 0438600002
R1, R2, R5, R6, R9, R10, R13: 10R; R_0603
R3, R4, R7, R8, R11, R12, R14: 47k; R_0603
R15: 220R; R_0603
R16, R19: 10k; R_0603
R17, R20, R21: 22R; R_0603
R18: 2.4k; R_0603
S1, S2, S3, S4, S11, S12: Screw_#4
S5, S6, S7, S8, S9, S10: Screw_#2
TVS1, TVS2, TVS3, TVS4, TVS5, TVS6, TVS7, TVS10, TVS11, TVS12, TVS13: DLP05LC-7-F; SOT-23
TVS8: SD05-7; D_SOD-323_HandSoldering
TVS9: DF2S12FU,H3F; D_SOD-323_HandSoldering
U1: IFX24401TEV50; IFX24401TEV
U2, U3, U4, U5, U6, U7, U8: NL17SZ17DFT2G; SC-70-5
U9: KC5032A32.0000CMGE00; KC5032A-CM
U10: PIC16F15324-E_SN; SOIC-14_3.9x8.7mm_Pitch1.27mm

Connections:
/5V: C1.1, C2.1, C5.1, C6.1, C7.1, C8.1, C9.1, C10.1, C11.1, C12.1, C13.2, C14.2, J10.2, R15.2, R19.1, TVS8.1, U1.5, U2.5, U3.5, U4.5, U5.5, U6.5, U7.5, U8.5, U9.1, U9.4, U10.1
/J_PGC: J10.5, R20.1, TVS12.3
/J_PGD: J10.4, R17.1, TVS13.3
/J_VPP: J10.1, R19.2, R21.2, TVS9.1
/OUT_RA2: R4.2, U3.2, U10.11
/OUT_RC0: R8.2, U5.2, U10.10
/OUT_RC1: R12.2, U7.2, U10.9
/OUT_RC2: R14.2, U8.2, U10.8
/OUT_RC3: R11.2, U6.2, U10.7
/OUT_RC4: R7.2, U4.2, U10.6
/OUT_RC5: R3.2, U2.2, U10.5
GND: C1.2, C2.2, C3.2, C4.2, C5.2, C6.2, C7.2, C8.2, C9.2, C10.2, C11.2, C12.2, C13.1, C14.1, D2.2, J1.2, J2.2, J3.2, J4.2, J5.2, J6.2, J7.2, J8.2, J10.3, R3.1, R4.1, R7.1, R8.1, R11.1, R12.1, R14.1, R18.2, TVS1.1, TVS2.1, TVS3.1, TVS4.1, TVS5.1, TVS6.1, TVS7.1, TVS8.2, TVS9.2, TVS10.1, TVS11.1, TVS12.1, TVS13.1, U1.3, U2.3, U3.3, U4.3, U5.3, U6.3, U7.3, U8.3, U9.2, U10.14
unnamed: C3.1, C4.1, D1.1, U1.1, U1.4
unnamed: D1.2, D2.1, F1.1
unnamed: F1.2, J1.1
unnamed: J2.1, R1.1, TVS1.3
unnamed: J3.1, R2.1, TVS2.3
unnamed: J4.1, R5.1, TVS3.3
unnamed: J5.1, R6.1, TVS4.3
unnamed: J6.1, R9.1, TVS5.3
unnamed: J7.1, R10.1, TVS6.3
unnamed: J8.1, R13.1, TVS7.3
unnamed: J9.1, R15.1, TVS10.3
unnamed: J9.2, R16.1, R18.1, TVS11.3
unnamed: R1.2, U2.4
unnamed: R2.2, U3.4
unnamed: R5.2, U4.4
unnamed: R6.2, U5.4
unnamed: R9.2, U6.4
unnamed: R10.2, U7.4
unnamed: R13.2, U8.4
unnamed: R16.2, U10.3
unnamed: R17.2, U10.13
unnamed: R20.2, U10.12
unnamed: R21.1, U10.4
unnamed: U9.3, U10.2

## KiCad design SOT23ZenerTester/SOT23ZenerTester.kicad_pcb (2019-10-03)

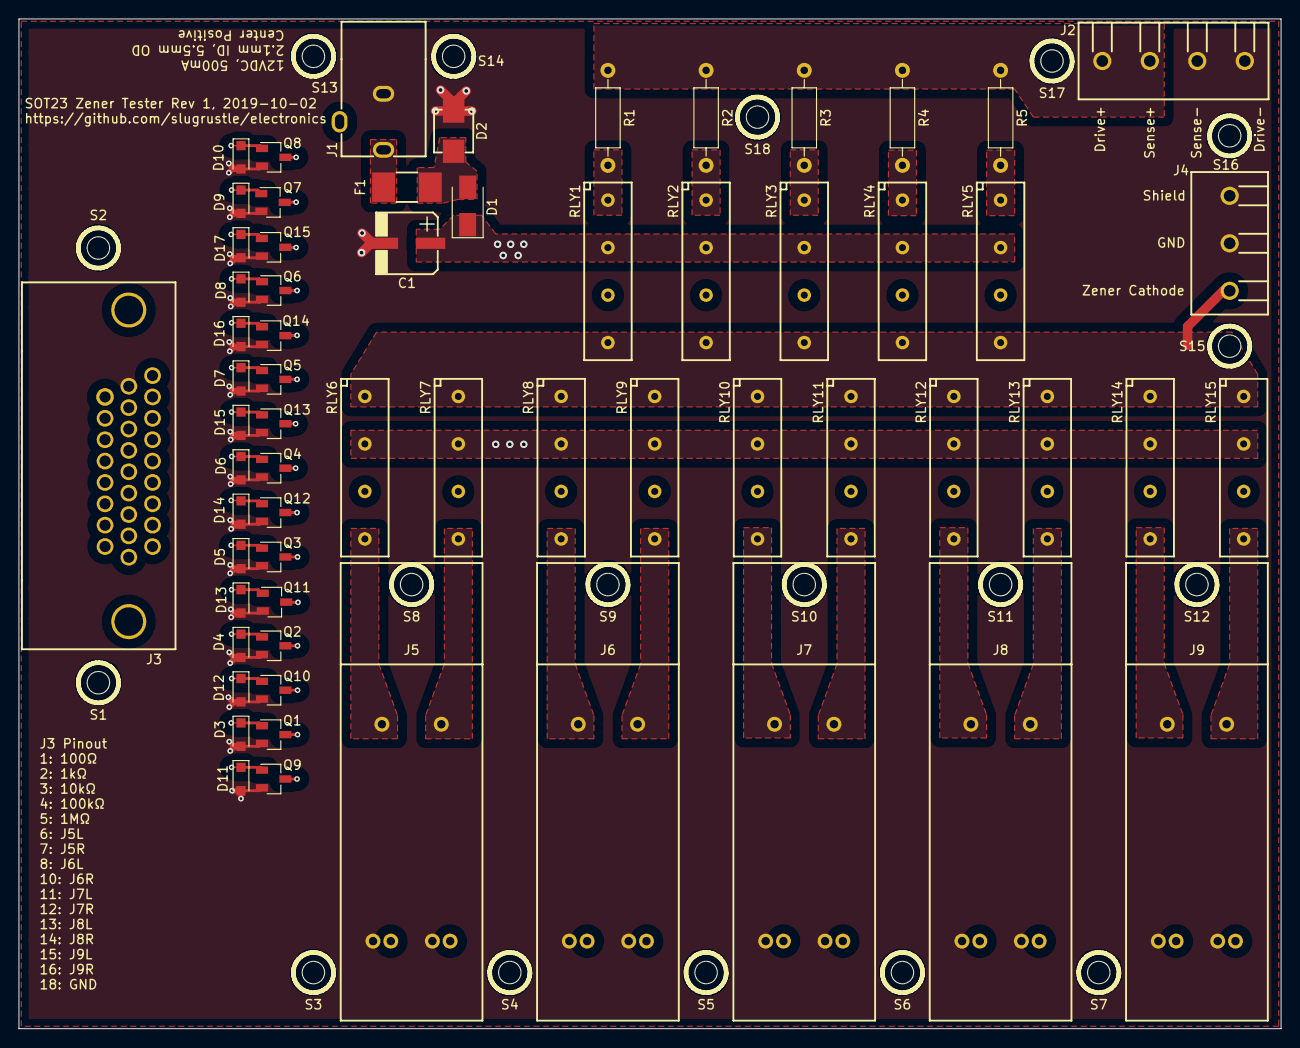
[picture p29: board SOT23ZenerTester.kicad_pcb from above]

Board: 4 copper layers, 135.0 x 108.0 mm, 81 parts (0 on the bottom side), 51 nets.

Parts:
C1: HHXC350ARA680MF80G; HHXC_F80
D1: NRVTSA4100E; D_SMA
D2: SMBJ13CA; D_SMB_Bidir
D3, D4, D5, D6, D7, D8, D9, D10, D11, D12, D13, D14, D15, D16, D17: PESD5V0L1UA; D_SOD-323_HandSoldering
F1: 0679L0375-05; Fuse_2410
J1: PJ-102AH
J2: 282837-4
J3: L17HTHAS4F1C
J4: 282837-3
J5, J6, J7, J8, J9: CSD_Dual_SOT23; CSD_Technology_Dual_SOT23_ZIF
Q1, Q2, Q3, Q4, Q5, Q6, Q7, Q8, Q9, Q10, Q11, Q12, Q13, Q14, Q15: PDTC123JT; SOT-23
R1: 100; R_Axial_DIN0207_L6.3mm_D2.5mm_P10.16mm_Horizontal
R2: 1k; R_Axial_DIN0207_L6.3mm_D2.5mm_P10.16mm_Horizontal
R3: 10k; R_Axial_DIN0207_L6.3mm_D2.5mm_P10.16mm_Horizontal
R4: 100k; R_Axial_DIN0207_L6.3mm_D2.5mm_P10.16mm_Horizontal
R5: 1M; R_Axial_DIN0207_L6.3mm_D2.5mm_P10.16mm_Horizontal
RLY1, RLY2, RLY3, RLY4, RLY5, RLY6, RLY7, RLY8, RLY9, RLY10, RLY11, RLY12, RLY13, RLY14, RLY15: 3570-1331-123
S1, S2, S3, S4, S5, S6, S7, S8, S9, S10, S11, S12, S13, S14, S15, S16, S17, S18: Screw_#2

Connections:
/12V: C1.1, D1.1, RLY1.2, RLY2.2, RLY3.2, RLY4.2, RLY5.2, RLY6.2, RLY7.2, RLY8.2, RLY9.2, RLY10.2, RLY11.2, RLY12.2, RLY13.2, RLY14.2, RLY15.2
/R1KRLY: D4.1, J3.2, Q2.1
/R1MRLY: D7.1, J3.5, Q5.1
/R10KRLY: D5.1, J3.3, Q3.1
/R100KRLY: D6.1, J3.4, Q4.1
/R100RLY: D3.1, J3.1, Q1.1
/VSWEEP: J2.3, J2.4, R1.1, R2.1, R3.1, R4.1, R5.1
/ZD1RLY: D8.1, J3.6, Q6.1
/ZD2RLY: D9.1, J3.7, Q7.1
/ZD3RLY: D10.1, J3.8, Q8.1
/ZD4RLY: D11.1, J3.10, Q9.1
/ZD5RLY: D12.1, J3.11, Q10.1
/ZD6RLY: D13.1, J3.12, Q11.1
/ZD7RLY: D14.1, J3.13, Q12.1
/ZD8RLY: D15.1, J3.14, Q13.1
/ZD9RLY: D16.1, J3.15, Q14.1
/ZD10RLY: D17.1, J3.16, Q15.1
/Z_Cathode: J4.1, RLY1.4, RLY2.4, RLY3.4, RLY4.4, RLY5.4, RLY6.1, RLY7.1, RLY8.1, RLY9.1, RLY10.1, RLY11.1, RLY12.1, RLY13.1, RLY14.1, RLY15.1
GND: C1.2, D2.2, D3.2, D4.2, D5.2, D6.2, D7.2, D8.2, D9.2, D10.2, D11.2, D12.2, D13.2, D14.2, D15.2, D16.2, D17.2, J1.2, J2.1, J2.2, J3.18, J4.2, J4.3, J5.1, J5.4, J6.1, J6.4, J7.1, J7.4, J8.1, J8.4, J9.1, J9.4, Q1.2, Q2.2, Q3.2, Q4.2, Q5.2, Q6.2, Q7.2, Q8.2, Q9.2, Q10.2, Q11.2, Q12.2, Q13.2, Q14.2, Q15.2
unnamed: D1.2, D2.1, F1.1
unnamed: F1.2, J1.1
unnamed: J5.3, RLY6.4
unnamed: J5.6, RLY7.4
unnamed: J6.3, RLY8.4
unnamed: J6.6, RLY9.4
unnamed: J7.3, RLY10.4
unnamed: J7.6, RLY11.4
unnamed: J8.3, RLY12.4
unnamed: J8.6, RLY13.4
unnamed: J9.3, RLY14.4
unnamed: J9.6, RLY15.4
unnamed: Q1.3, RLY1.3
unnamed: Q2.3, RLY2.3
unnamed: Q3.3, RLY3.3
unnamed: Q4.3, RLY4.3
unnamed: Q5.3, RLY5.3
unnamed: Q6.3, RLY6.3
unnamed: Q7.3, RLY7.3
unnamed: Q8.3, RLY8.3
unnamed: Q9.3, RLY9.3
unnamed: Q10.3, RLY10.3
unnamed: Q11.3, RLY11.3
unnamed: Q12.3, RLY12.3
unnamed: Q13.3, RLY13.3
unnamed: Q14.3, RLY14.3
unnamed: Q15.3, RLY15.3
unnamed: R1.2, RLY1.1
unnamed: R2.2, RLY2.1
unnamed: R3.2, RLY3.1
unnamed: R4.2, RLY4.1
unnamed: R5.2, RLY5.1

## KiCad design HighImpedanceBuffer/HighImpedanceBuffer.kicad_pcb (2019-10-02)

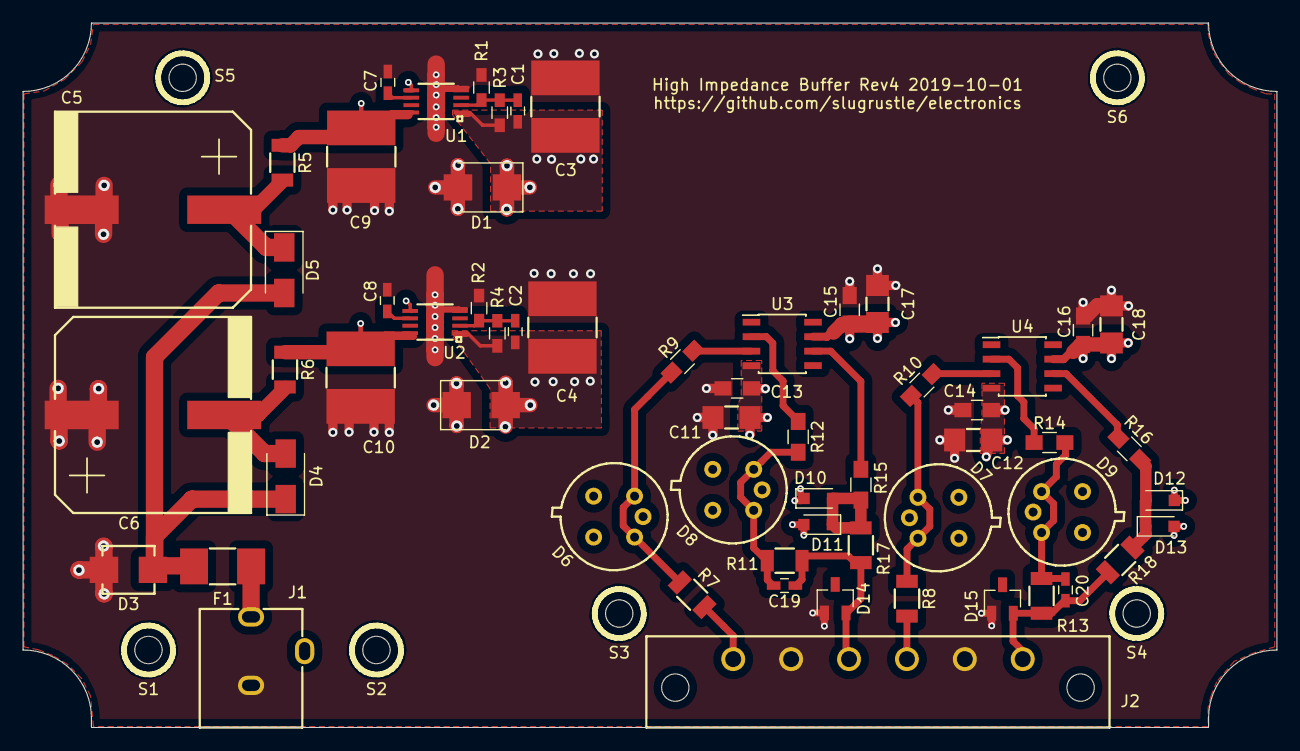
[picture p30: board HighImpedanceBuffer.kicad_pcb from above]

Board: 4 copper layers, 110.0 x 61.8 mm, 66 parts (0 on the bottom side), 29 nets.

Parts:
C1, C2, C7, C8: 10n_NP0; C_0603_HandSoldering
C3, C4, C9, C10: 10u; C_2220
C5, C6: 470u; TG_J16
C11, C12, C17, C18: 1u; C_1206
C13, C14, C15, C16: 100n; C_0805_HandSoldering
C19, C20: TBD; C_0603_HandSoldering
D1, D2: SMBJ18A; D_SMB
D3: SMBJ36CA; D_SMB_Bidir
D4, D5: NRVTSA4100E; D_SMA
D6, D7, D8, D9: DPAD1; TO-78-5
D10, D11, D12, D13: CMDD6001; D_SOD-323_HandSoldering
D14, D15: MMBZ27VAL; SOT-23
F1: SF-2410FP0375T-2; Fuse_2410
J1: PJ-102AH
J2: 1776540
R1, R2: 6.2k; R_0603_HandSoldering
R3, R4: 88.7k; R_0603_HandSoldering
R5, R6: 2.2; R_1206
R7, R8: 10k; R_1206
R9, R10, R12, R14: 1k; R_0805_HandSoldering
R11, R13: 2.7k; R_1206
R15, R16: 20; R_0805_HandSoldering
R17, R18: 100; R_1206
S1, S2, S3, S4, S5, S6: Screw_#2
U1: TPS7A4901DGNR; MSOP-8-EP
U2: TPS7A3001DGNR; MSOP-8-EP
U3, U4: OPA192IDR; SOIC-8_3.9x4.9mm_Pitch1.27mm

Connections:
/18V+: C1.1, C3.2, C15.2, C16.2, C17.2, C18.2, D1.1, D6.1, D7.1, D8.1, D9.1, D10.1, D12.1, R3.1, U1.1, U3.7, U4.7
/18V-: C2.1, C4.2, C11.1, C12.1, C13.1, C14.1, D2.2, D6.7, D7.7, D8.7, D9.7, D11.2, D13.2, R4.1, U2.1, U3.4, U4.4
/IN1: J2.1, R7.2
/IN2: J2.4, R8.2
/OUT1: C19.1, D14.2, J2.3, R11.1, R17.1
/OUT2: C20.1, D15.2, J2.6, R13.1, R18.1
/PreReg+: C9.1, R5.1, U1.5, U1.8
/PreReg-: C10.2, R6.1, U2.5, U2.8
GND: C3.1, C4.1, C5.2, C6.1, C7.2, C8.2, C9.2, C10.1, C11.2, C12.2, C13.2, C14.2, C15.1, C16.1, C17.1, C18.1, D1.2, D2.1, D3.2, D14.1, D15.1, J1.2, J2.2, J2.5, R1.2, R2.2, U1.4, U1.9, U2.4, U2.9
unnamed: C1.2, R1.1, R3.2, U1.2
unnamed: C2.2, R2.1, R4.2, U2.2
unnamed: C5.1, D5.1, R5.2
unnamed: C6.2, D4.2, R6.2
unnamed: C7.1, U1.6
unnamed: C8.1, U2.6
unnamed: C19.2, D8.3, D8.5, R11.2, R12.2
unnamed: C20.2, D9.3, D9.5, R13.2, R14.2
unnamed: D3.1, D4.1, D5.2, F1.1
unnamed: D6.3, D6.5, R7.1, R9.2
unnamed: D7.3, D7.5, R8.1, R10.2
unnamed: D10.2, D11.1, R15.1, R17.2
unnamed: D12.2, D13.1, R16.1, R18.2
unnamed: F1.2, J1.1
unnamed: R9.1, U3.3
unnamed: R10.1, U4.3
unnamed: R12.1, U3.2
unnamed: R14.1, U4.2
unnamed: R15.2, U3.6
unnamed: R16.2, U4.6

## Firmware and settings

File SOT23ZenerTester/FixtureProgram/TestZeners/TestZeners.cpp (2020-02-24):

/**
 * TestZeners.cpp
 * 
 * TestZeners obtains a full voltage / current curve for the Zener diodes
 * under test by using multiple supply voltages and pullup resistors in
 * sequence to vary the Zener bias current. Test results are stored in an
 * office open xml workbook (.xlsx file).
 * 
 * Written in 2019 by Ben Tesch.
 * Originally distributed at https://github.com/slugrustle/electronics
 *
 * To the extent possible under law, the author has dedicated all copyright
 * and related and neighboring rights to this software to the public domain
 * worldwide. This software is distributed without any warranty.
 * The text of the CC0 Public Domain Dedication should be reproduced at the
 * end of this file. If not, see http://creativecommons.org/publicdomain/zero/1.0/
 */

#include <cinttypes>
#include <cstdio>
#include <string>
#include <thread>
#include <chrono>
#include <cmath>
#include <iomanip>
#define NOMINMAX
#include <Windows.h>
#include <WinBase.h>
#include "dln.h"
#include "dln_generic.h"
#include "dln_gpio.h"
#include "parse_config_file.h"
#include "SCPI_helpers.h"
#include "SCPI_transactions.h"
#include "BasicWorkbook.h"

/**
 * Globals
 */
HDLN diolan_handle;
bool diolan_opened = false;
bool ctrl_c_happened = false;
bool GPIO_initialized = false;
HANDLE psu_com_port_handle;
bool psu_com_port_opened = false;
bool psu_modified = false;
HANDLE dmm_com_port_handle;
bool dmm_com_port_opened = false;
bool dmm_modified = false;
BasicWorkbook::Workbook workbook;
std::string workbook_filename;
bool workbook_started = false;

/**
 * Clean up function.
 * To be called before exiting normally or abnormally.
 * Should release all acquired resources.
 */
void exit_cleanup(void)
{
  DLN_RESULT dln_res;

  if (GPIO_initialized)
  {
    for (size_t jZener = 0u; jZener < NUM_ZENER_SOCKETS; jZener++)
    {
      dln_res = DlnGpioPinSetOutVal(diolan_handle, ZENER_RELAY_PIN.at(jZener), 0u);
      if (!DLN_SUCCEEDED(dln_res))
      {
        std::printf("Error: Could not set the level of GPIO pin %u.\n\n", ZENER_RELAY_PIN.at(jZener));
      }
    }
    for (size_t jResistor = 0u; jResistor < NUM_FIXTURE_RESISTORS; jResistor++)
    {
      dln_res = DlnGpioPinSetOutVal(diolan_handle, RESISTOR_RELAY_PIN.at(jResistor), 0u);
      if (!DLN_SUCCEEDED(dln_res))
      {
        std::printf("Error: Could not set the level of GPIO pin %u.\n\n", RESISTOR_RELAY_PIN.at(jResistor));
      }
    }
  }

  if (diolan_opened)
  {
    dln_res = DlnCloseHandle(diolan_handle);
    if (!DLN_SUCCEEDED(dln_res))
    {
      std::printf("Error: Could not properly close Diolan device.\n\n");
    }
  }

  if (psu_modified)
  {
    KnownStateStatus known_state_ret = set_known_PSU_state(psu_com_port_handle);
    if (known_state_ret != KnownStateStatus::ALL_OK)
    {
      std::printf("Error putting PSU into known state on exit.\n\n");
    }
  }

  if (psu_com_port_opened)
  {
    CloseHandle(psu_com_port_handle);
  }

  if (dmm_com_port_opened)
  {
    CloseHandle(dmm_com_port_handle);
  }

  if (workbook_started)
  {
    try
    {
      workbook.publish(workbook_filename);
    }
    catch (std::exception &e)
    {
      std::printf("Error creating workbook file %s.\n%s\n\n", workbook_filename.c_str(), e.what());
    }
  }
}

/**
 * A custom Ctrl + C handler to break the main loop.
 */
BOOL WINAPI CtrlHandler(DWORD fdwCtrlType)
{
  if (fdwCtrlType == CTRL_C_EVENT || fdwCtrlType == CTRL_CLOSE_EVENT)
  {
    ctrl_c_happened = true;
    return true;
  }

  return false;
}

int main (int argc, char** argv)
{
  std::printf("Usage:\n\n");
  std::printf(".\\TestZeners.exe config_file.txt output_file.xlsx\n\n");

  if (argc != 3)
  {
    std::printf("This program requires exactly two input arguments.\n\n");
    exit_cleanup();
    return EXIT_FAILURE;
  }

  if (!SetConsoleCtrlHandler(CtrlHandler, TRUE))
  {
    std::printf("Error: Could not set control handler.\n\n");
    exit_cleanup();
    return EXIT_FAILURE;
  }

  std::ifstream config_stream(argv[1]);
  if (!config_stream.is_open())
  {
    std::printf("Error: Could not open configuration file \"%s\" for reading.\n\n", argv[1]);
    exit_cleanup();
    return EXIT_FAILURE;
  }

  test_config_t test_config = parse_config_file(config_stream);
  config_stream.close();
  if (!test_config.read_ok)
  {
    std::printf("Error reading configuration file. Exiting.\n\n");
    exit_cleanup();
    return EXIT_FAILURE;
  }

  workbook_filename = argv[2];

  DLN_RESULT dln_res;

  uint32_t num_diolan_devices = 0u;
  dln_res = DlnGetDeviceCount(&num_diolan_devices);
  if (!DLN_SUCCEEDED(dln_res))
  {
    std::printf("Error: Could not get Diolan device count.\n\n");
    exit_cleanup();
    return EXIT_FAILURE;
  }

  if (num_diolan_devices == 0u)
  {
    std::printf("Error: No Diolan device is connected.\n\n");
    exit_cleanup();
    return EXIT_FAILURE;
  }

  if (num_diolan_devices > 1u)
  {
    if (!test_config.diolan_serial_present)
    {
      std::printf("Error: %u Diolan devices are connected, but no\n", num_diolan_devices);
      std::printf("  DIOLAN_SERIAL_NUMBER was specified in the configuration\n");
      std::printf("  file to pick which one to open.\n\n");
      std::printf("  Either connect only one Diolan device, or specify\n");
      std::printf("  which one to open by serial number.\n\n");
      exit_cleanup();
      return EXIT_FAILURE;
    }
    else
    {
      dln_res = DlnOpenDeviceBySn(test_config.diolan_serial_number, &diolan_handle);
      if (!DLN_SUCCEEDED(dln_res))
      {
        std::printf("Error: Could not open a Diolan device with serial number 0x%08X.\n\n", test_config.diolan_serial_number);
        exit_cleanup();
        return EXIT_FAILURE;
      }
    }
  }
  else
  {
    dln_res = DlnOpenDevice(0u, &diolan_handle);
    if (!DLN_SUCCEEDED(dln_res))
    {
      std::printf("Error: Could not open the only connected Diolan device.\n\n");
      exit_cleanup();
      return EXIT_FAILURE;
    }
  }

  diolan_opened = true;
  std::printf("Opened diolan device");

  uint32_t diolan_serial = 0u;
  dln_res = DlnGetDeviceSn(diolan_handle, &diolan_serial);
  if (!DLN_SUCCEEDED(dln_res))
  {
    std::printf("\nError: Could not retrieve serial number from Diolan device.\n\n");
    exit_cleanup();
    return EXIT_FAILURE;
  }

  std::printf(" with serial 0x%08X.\n", diolan_serial);

  uint16_t pin_count = 0u;
  dln_res = DlnGpioGetPinCount(diolan_handle, &pin_count);
  if (!DLN_SUCCEEDED(dln_res))
  {
    std::printf("Error: Could not get Diolan device pin count\n\n");
    exit_cleanup();
    return EXIT_FAILURE;
  }

  if (pin_count < test_config.num_gpio_required)
  {
    std::printf("Error: Connected Diolan device only has %u GPIO pins.\n", pin_count);
    std::printf("  This program requires at least %u GPIO pins.\n\n", test_config.num_gpio_required);
    exit_cleanup();
    return EXIT_FAILURE;
  }

  for (size_t jZener = 0u; jZener < NUM_ZENER_SOCKETS; jZener++)
  {
    uint16_t this_pin = ZENER_RELAY_PIN.at(jZener);

    dln_res = DlnGpioPinSetOutVal(diolan_handle, this_pin, 0u);
    if (!DLN_SUCCEEDED(dln_res))
    {
      std::printf("Error: Could not set the level of GPIO pin %u.\n\n", this_pin);
      exit_cleanup();
      return EXIT_FAILURE;
    }

    dln_res = DlnGpioPinSetDirection(diolan_handle, this_pin, 1u);
    if (!DLN_SUCCEEDED(dln_res))
    {
      std::printf("Error: Could not set GPIO pin %u to be an output.\n\n", this_pin);
      exit_cleanup();
      return EXIT_FAILURE;
    }

    dln_res = DlnGpioPinEnable(diolan_handle, this_pin);
    if (!DLN_SUCCEEDED(dln_res))
    {
      std::printf("Error: Could not enable GPIO pin %u.\n\n", this_pin);
      exit_cleanup();
      return EXIT_FAILURE;
    }
  }

  for (size_t jResistor = 0u; jResistor < NUM_FIXTURE_RESISTORS; jResistor++)
  {
    uint16_t this_pin = RESISTOR_RELAY_PIN.at(jResistor);

    dln_res = DlnGpioPinSetOutVal(diolan_handle, this_pin, 0u);
    if (!DLN_SUCCEEDED(dln_res))
    {
      std::printf("Error: Could not set the level of GPIO pin %u.\n\n", this_pin);
      exit_cleanup();
      return EXIT_FAILURE;
    }

    dln_res = DlnGpioPinSetDirection(diolan_handle, this_pin, 1u);
    if (!DLN_SUCCEEDED(dln_res))
    {
      std::printf("Error: Could not set GPIO pin %u to be an output.\n\n", this_pin);
      exit_cleanup();
      return EXIT_FAILURE;
    }

    dln_res = DlnGpioPinEnable(diolan_handle, this_pin);
    if (!DLN_SUCCEEDED(dln_res))
    {
      std::printf("Error: Could not enable GPIO pin %u.\n\n", this_pin);
      exit_cleanup();
      return EXIT_FAILURE;
    }
  }

  GPIO_initialized = true;

  dmm_com_port_handle = CreateFile(test_config.com_ports.at(static_cast<size_t>(SerialDevice::DMM)).c_str(), 
    GENERIC_READ | GENERIC_WRITE,
    0, NULL, OPEN_EXISTING, 0, NULL);

  if (dmm_com_port_handle == INVALID_HANDLE_VALUE)
  {
    std::printf("Error opening COM port for DMM, %s.\n\n", test_config.com_port_printables.at(static_cast<size_t>(SerialDevice::DMM)).c_str());
    exit_cleanup();
    return EXIT_FAILURE;
  }

  dmm_com_port_opened = true;

  DCB dcbSerialParams = { 0 };
  dcbSerialParams.DCBlength = sizeof(dcbSerialParams);

  if (!GetCommState(dmm_com_port_handle, &dcbSerialParams))
  {
    std::printf("Error: Could not retrieve parameters for DMM COM port, %s.\n\n", test_config.com_port_printables.at(static_cast<size_t>(SerialDevice::DMM)).c_str());
    exit_cleanup();
    return EXIT_FAILURE;
  }

  dcbSerialParams.BaudRate          = static_cast<DWORD>(test_config.baud_rates.at(static_cast<size_t>(SerialDevice::DMM)));
  dcbSerialParams.fBinary           = true;
  dcbSerialParams.fParity           = (test_config.parities.at(static_cast<size_t>(SerialDevice::DMM)) != ParityType::NONE);
  dcbSerialParams.fOutxCtsFlow      = false;
  dcbSerialParams.fOutxDsrFlow      = false;
  dcbSerialParams.fDtrControl       = DTR_CONTROL_DISABLE;
  dcbSerialParams.fDsrSensitivity   = false;
  dcbSerialParams.fTXContinueOnXoff = true;
  dcbSerialParams.fOutX             = false;
  dcbSerialParams.fInX              = false;
  dcbSerialParams.fErrorChar        = false;
  dcbSerialParams.fNull             = false;
  dcbSerialParams.fRtsControl       = RTS_CONTROL_DISABLE;
  dcbSerialParams.fAbortOnError     = false;
  dcbSerialParams.wReserved         = 0;
  dcbSerialParams.ByteSize          = 8;
  dcbSerialParams.Parity            = static_cast<DWORD>(test_config.parities.at(static_cast<size_t>(SerialDevice::DMM)));
  dcbSerialParams.StopBits          = ONESTOPBIT;

  if (!SetCommState(dmm_com_port_handle, &dcbSerialParams))
  {
    std::printf("Error: Could not set parameters for DMM COM port, %s.\n\n", test_config.com_port_printables.at(static_cast<size_t>(SerialDevice::DMM)).c_str());
    exit_cleanup();
    return EXIT_FAILURE;
  }

  COMMTIMEOUTS timeouts = { 0 };
  timeouts.ReadIntervalTimeout         = MAXDWORD;
  timeouts.ReadTotalTimeoutConstant    = 50;
  timeouts.ReadTotalTimeoutMultiplier  = MAXDWORD;
  timeouts.WriteTotalTimeoutConstant   = 10;
  timeouts.WriteTotalTimeoutMultiplier = static_cast<DWORD>(std::ceil(1.1 * 10.0 * 1000.0 / static_cast<double>(test_config.baud_rates.at(static_cast<size_t>(SerialDevice::DMM)))));

  if (!SetCommTimeouts(dmm_com_port_handle, &timeouts))
  {
    std::printf("Error: Could not set timeouts for DMM COM port, %s.\n\n", test_config.com_port_printables.at(static_cast<size_t>(SerialDevice::DMM)).c_str());
    exit_cleanup();
    return EXIT_FAILURE;
  }  

  std::printf("Opened COM port for DMM, %s.\n", test_config.com_port_printables.at(static_cast<size_t>(SerialDevice::DMM)).c_str());

  std::string dmm_id;
  Check_ID_status dmm_id_ret = check_DMM_ID(dmm_com_port_handle, dmm_id);
  if (dmm_id_ret == Check_ID_status::COM_ERROR)
  {
    std::printf("Error when trying to identify DMM over COM port.\n\n");
    exit_cleanup();
    return EXIT_FAILURE;
  }
  if (dmm_id_ret == Check_ID_status::ZERO_DATA)
  {
    std::printf("Error: No reply to SCPI *IDN? (identify device) query on DMM COM port.\n");
    std::printf("       Check your connections, baud rate settings, and configuration file.\n\n");
    exit_cleanup();
    return EXIT_FAILURE;
  }
  if (dmm_id_ret == Check_ID_status::ID_MISMATCH)
  {
    std::printf("Warning: Device on DMM COM port did not identify as a Rigol DM3068\n");
    std::printf("         multimeter. Other DMMs might not function properly with the\n");
    std::printf("         programmed command set. Continuing anyway.\n\n");
  }
  if (dmm_id_ret == Check_ID_status::ID_MATCH)
  {
    std::printf("DMM identified as a Rigol DM3068.\n");
  }

  std::printf("DMM ID string: %s\n", dmm_id.c_str());
  std::printf("Warning: You must manually set the Measurement Integration Time\n");
  std::printf("         to 10 NPLC as this setting is not accessible over SCPI.\n");
  std::printf("         Nearest options are 0.2 (not as accurate) and 100 (very\n");
  std::printf("         slow).\n\n");

  PSC_status psc_ret = set_PSC(dmm_com_port_handle);
  if (psc_ret == PSC_status::COM_ERROR)
  {
    std::printf("Error when trying to set DMM power-on status clear over COM port.\n\n");
    exit_cleanup();
    return EXIT_FAILURE;
  }
  if (psc_ret != PSC_status::PSC_ON)
  {
    std::printf("Warning: Unable to set DMM power-on status clear over COM port.\n");
    std::printf("         continuing anyway.\n\n");
  }

  KnownStateStatus known_state_ret = set_known_DMM_state(dmm_com_port_handle, true);
  if (known_state_ret != KnownStateStatus::ALL_OK)
  {
    std::printf("Error putting DMM into known state.\n\n");
    exit_cleanup();
    return EXIT_FAILURE;
  }

  OPC_status opc_ret = check_OPC(dmm_com_port_handle);
  if (opc_ret == OPC_status::OPC_FALSE)
  {
    std::printf("Error: DMM hung during attempt to establish known state.\n\n");
    exit_cleanup();
    return EXIT_FAILURE;
  }
  else if (opc_ret != OPC_status::OPC_TRUE)
  {
    std::printf("Error checking DMM command completion after setting known state.\n\n");
    exit_cleanup();
    return EXIT_FAILURE;
  }

  std::printf("DMM set to known state.\n");

  psu_com_port_handle = CreateFile(test_config.com_ports.at(static_cast<size_t>(SerialDevice::PSU)).c_str(), 
                               GENERIC_READ | GENERIC_WRITE,
                               0, NULL, OPEN_EXISTING, 0, NULL);

  if (psu_com_port_handle == INVALID_HANDLE_VALUE)
  {
    std::printf("Error opening COM port for PSU, %s.\n\n", test_config.com_port_printables.at(static_cast<size_t>(SerialDevice::PSU)).c_str());
    exit_cleanup();
    return EXIT_FAILURE;
  }

  psu_com_port_opened = true;

  dcbSerialParams = { 0 };
  dcbSerialParams.DCBlength = sizeof(dcbSerialParams);

  if (!GetCommState(psu_com_port_handle, &dcbSerialParams))
  {
    std::printf("Error: Could not retrieve parameters for PSU COM port, %s.\n\n", test_config.com_port_printables.at(static_cast<size_t>(SerialDevice::PSU)).c_str());
    exit_cleanup();
    return EXIT_FAILURE;
  }

  dcbSerialParams.BaudRate          = static_cast<DWORD>(test_config.baud_rates.at(static_cast<size_t>(SerialDevice::PSU)));
  dcbSerialParams.fBinary           = true;
  dcbSerialParams.fParity           = (test_config.parities.at(static_cast<size_t>(SerialDevice::PSU)) != ParityType::NONE);
  dcbSerialParams.fOutxCtsFlow      = false;
  dcbSerialParams.fOutxDsrFlow      = false;
  dcbSerialParams.fDtrControl       = DTR_CONTROL_DISABLE;
  dcbSerialParams.fDsrSensitivity   = false;
  dcbSerialParams.fTXContinueOnXoff = true;
  dcbSerialParams.fOutX             = false;
  dcbSerialParams.fInX              = false;
  dcbSerialParams.fErrorChar        = false;
  dcbSerialParams.fNull             = false;
  dcbSerialParams.fRtsControl       = RTS_CONTROL_DISABLE;
  dcbSerialParams.fAbortOnError     = false;
  dcbSerialParams.wReserved         = 0;
  dcbSerialParams.ByteSize          = 8;
  dcbSerialParams.Parity            = static_cast<DWORD>(test_config.parities.at(static_cast<size_t>(SerialDevice::PSU)));
  dcbSerialParams.StopBits          = ONESTOPBIT;
  
  if (!SetCommState(psu_com_port_handle, &dcbSerialParams))
  {
    std::printf("Error: Could not set parameters for PSU COM port, %s.\n\n", test_config.com_port_printables.at(static_cast<size_t>(SerialDevice::PSU)).c_str());
    exit_cleanup();
    return EXIT_FAILURE;
  }
  
  timeouts = { 0 };
  timeouts.ReadIntervalTimeout         = MAXDWORD;
  timeouts.ReadTotalTimeoutConstant    = 50;
  timeouts.ReadTotalTimeoutMultiplier  = MAXDWORD;
  timeouts.WriteTotalTimeoutConstant   = 10;
  timeouts.WriteTotalTimeoutMultiplier = static_cast<DWORD>(std::ceil(1.1 * 10.0 * 1000.0 / static_cast<double>(test_config.baud_rates.at(static_cast<size_t>(SerialDevice::PSU)))));
  
  if (!SetCommTimeouts(psu_com_port_handle, &timeouts))
  {
    std::printf("Error: Could not set timeouts for PSU COM port, %s.\n\n", test_config.com_port_printables.at(static_cast<size_t>(SerialDevice::PSU)).c_str());
    exit_cleanup();
    return EXIT_FAILURE;
  }  
  
  std::printf("Opened COM port for PSU, %s.\n", test_config.com_port_printables.at(static_cast<size_t>(SerialDevice::PSU)).c_str());

  std::string psu_id;
  Check_ID_status psu_id_ret = check_PSU_ID(psu_com_port_handle, psu_id);
  if (psu_id_ret == Check_ID_status::COM_ERROR)
  {
    std::printf("Error when trying to identify PSU over COM port.\n\n");
    exit_cleanup();
    return EXIT_FAILURE;
  }
  if (psu_id_ret == Check_ID_status::ZERO_DATA)
  {
    std::printf("Error: No reply to SCPI *IDN? (identify device) query on PSU COM port.\n");
    std::printf("       Check your connections, baud rate settings, and configuration file.\n\n");
    exit_cleanup();
    return EXIT_FAILURE;
  }
  if (psu_id_ret == Check_ID_status::ID_MISMATCH)
  {
    std::printf("Warning: Device on PSU COM port did not identify as an Itech IT6100B series\n");
    std::printf("         power supply. Other PSUs might not function properly with the\n");
    std::printf("         programmed command set. Continuing anyway.\n\n");
  }
  if (psu_id_ret == Check_ID_status::ID_MATCH)
  {
    std::printf("PSU identified as Itech IT6100B series device.\n");
  }

  std::printf("PSU ID string: %s\n", psu_id.c_str());

  psc_ret = set_PSC(psu_com_port_handle);
  if (psc_ret == PSC_status::COM_ERROR)
  {
    std::printf("Error when trying to set PSU power-on status clear over COM port.\n\n");
    exit_cleanup();
    return EXIT_FAILURE;
  }
  if (psc_ret != PSC_status::PSC_ON)
  {
    std::printf("Warning: Unable to set PSU power-on status clear over COM port.\n");
    std::printf("         continuing anyway.\n\n");
  }

  known_state_ret = set_known_PSU_state(psu_com_port_handle);
  if (known_state_ret != KnownStateStatus::ALL_OK)
  {
    std::printf("Error putting PSU into known state.\n\n");
    exit_cleanup();
    return EXIT_FAILURE;
  }

  opc_ret = check_OPC(psu_com_port_handle);
  if (opc_ret == OPC_status::OPC_FALSE)
  {
    std::printf("Error: PSU hung during attempt to establish known state.\n\n");
    exit_cleanup();
    return EXIT_FAILURE;
  }
  else if (opc_ret != OPC_status::OPC_TRUE)
  {
    std::printf("Error checking PSU command completion after setting known state.\n\n");
    exit_cleanup();
    return EXIT_FAILURE;
  }

  std::printf("PSU set to known state.\n");

  PSU_limits_t PSU_limits;
  GetDataStatus get_ret = get_PSU_limits(psu_com_port_handle, PSU_limits);
  if (get_ret != GetDataStatus::ALL_OK)
  {
    std::printf("Error while retrieving PSU limits.\n\n");
    exit_cleanup();
    return EXIT_FAILURE;
  }

  double volt_protect_level = std::min(std::round(PSU_limits.voltage_out_max) + 1.0, PSU_limits.voltage_protect_max);

  /* Set PSU to remote mode so we can start changing settings. */
  SCPIstatus SCPIret = SCPIwrite(psu_com_port_handle, "SYST:REM");
  if (SCPIret != SCPIstatus::ALL_OK)
  {
    std::printf("Error while setting PSU to remote mode.\n\n");
    exit_cleanup();
    return EXIT_FAILURE;
  }

  psu_modified = true;

  SetDataStatus set_ret = set_PSU_protection(psu_com_port_handle, volt_protect_level);
  if (set_ret != SetDataStatus::ALL_OK)
  {
    std::printf("Error while setting PSU voltage protection to %.3fV and turning it on.\n\n", volt_protect_level);
    exit_cleanup();
    return EXIT_FAILURE;
  }

  /* Determine max current based on resistor power. */
  double max_current = 0.0;
  for (size_t jResistor = 0u; jResistor < NUM_FIXTURE_RESISTORS; jResistor++)
  {
    max_current = std::max(max_current, std::sqrt(test_config.max_resistor_powers.at(jResistor) / NOMINAL_RESISTANCES.at(jResistor)));
  }
  max_current *= 1.1;
  max_current = 0.001 * std::round(1000.0 * max_current);

  set_ret = set_PSU_current(psu_com_port_handle, max_current);
  if (set_ret != SetDataStatus::ALL_OK)
  {
    std::printf("Error while setting PSU current to %.3fA.\n\n", max_current);
    exit_cleanup();
    return EXIT_FAILURE;
  }

  set_ret = set_PSU_sense(psu_com_port_handle, true);
  if (set_ret != SetDataStatus::ALL_OK)
  {
    std::printf("Error while setting PSU to remote sense mode.\n\n");
    exit_cleanup();
    return EXIT_FAILURE;
  }

  /**
   * The main loop.
   *
   * Iterate over installed Zeners and get the Vz/Iz curve for each.
   */
  for (std::set<ZenerSocket>::iterator zenitr = test_config.zeners_installed.begin();
       zenitr != test_config.zeners_installed.end();
       zenitr++)
  {
    if (ctrl_c_happened)
    {
      std::printf("Detected Ctrl + C; Exiting.\n\n");
      exit_cleanup();
      return EXIT_SUCCESS;
    }

    ZenerSocket this_zener = *zenitr;
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

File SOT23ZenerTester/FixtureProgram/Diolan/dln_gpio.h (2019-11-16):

#ifndef DLN_GPIO_H
#define DLN_GPIO_H
#include "dln.h"

#ifdef __cplusplus
extern "C" {
#endif

#if defined(__ICCARM__)
        #pragma pack(1)
        #define __PACKED_ATTR   /*nothing*/
        //#define __attribute__(...)
#elif defined(WIN32) || defined(_WIN32) || defined(__BORLANDC__)  || defined(WIN64)
        #pragma pack(push,1)
        #define __PACKED_ATTR   /*nothing*/
        //#define __attribute__(...)
#else
        #define __PACKED_ATTR __attribute__ ((packed))
#endif

/*!
\struct DLN_GPIO_PIN_CONFIG
This structure is used to store configuration of a single GPIO pin.
*/
typedef struct
{
    uint16_t cfg;								///< A bit field that defines the pin configuration.
    uint8_t eventType;							///< Defines the condition of event generation for the pin.
    uint16_t eventPeriod;       				///< Defines the repeat interval for DLN_GPIO_CONDIION_MET event generation on the pin.
} __PACKED_ATTR DLN_GPIO_PIN_CONFIG;			


/*!
\struct DLN_GPIO_PORT_CONFIG
This structure is used to store configuration of GPIO pins from a single port.
*/
typedef struct
{
    DLN_GPIO_PIN_CONFIG pins[8];				///< An 8-element array.
												///  Each of its elements corresponds to DLN_GPIO_PIN_CONFIG structure for each pin of the port.
} __PACKED_ATTR DLN_GPIO_PORT_CONFIG;

typedef struct
{
	uint8_t count;
	uint8_t eventTypes[8];
} __PACKED_ATTR DLN_GPIO_PIN_EVENT_TYPES;

/*!
Retrieves the total number of GPIO pins available in the DLN-series device.
\param handle - a handle to the DLN-series adapter;
\param count - a pointer to an unsigned 16-bit integer. This integer will be filled with the number of available pins after function execution;
\retval DLN_RES_SUCCESS - the pin count has been successfully retrieved.
*/
DLN_RESULT DlnGpioGetPinCount(HDLN handle, uint16_t *count);

/*!
Retrieves the total number of the GPIO ports available in the DLN-series device.
\param handle - a handle to the DLN-series adapter;
\param count - a pointer to an unsigned 8-bit integer. This integer will be filled with the number of available ports after function execution;
\retval DLN_RES_SUCCESS - the port count has been successfully retrieved.
*/
DLN_RESULT DlnGpioGetPortCount(HDLN handle, uint8_t *count);

/*!
Retrieves the pin output value, stored in the internal latch.
\param handle - a handle to the DLN-series adapter;
\param pin - a pin to get the output value from;
\param value - a pointer to an unsigned 8-bit integer. This integer will be filled with the pin output value after the function execution;
\retval DLN_RES_SUCCESS - the pin output value has been successfully retrieved;
\retval DLN_RES_INVALID_PIN_NUMBER - invalid pin number was specified.
*/
DLN_RESULT DlnGpioPinGetOutVal(HDLN handle, uint16_t pin, uint8_t *value);

/*!
Sets the output value for the specified GPIO pin.
\param handle - a handle to the DLN-series adapter;
\param pin - a pin to be configured;
\param value - a pin output value to be set;
\retval DLN_RES_SUCCESS - the pin output value has been successfully set;
\retval DLN_RES_INVALID_PIN_NUMBER - invalid pin number was specified.
*/
DLN_RESULT DlnGpioPinSetOutVal(HDLN handle, uint16_t pin, uint8_t value);
/*!
Retrieves the current value on the specified GPIO pin.
\param handle - a handle to the DLN-series adapter;
\param pin - a pin to get the value from;
\param value - a pointer to an unsigned 8-bit integer. This integer will be filled with the pin value after the function execution;
\retval DLN_RES_SUCCESS - the pin value has been successfully retrieved;
\retval DLN_RES_INVALID_PIN_NUMBER - invalid pin number was specified;
\retval DLN_RES_PIN_NOT_CONNECTED_TO_MODULE - the pin is not assigned to GPIO module of the adapter and its value cannot be retrieved.
*/
DLN_RESULT DlnGpioPinGetVal(HDLN handle, uint16_t pin, uint8_t *value);

/*!
Retrieves current level on the I/O lines from the specified port.
\param handle - a handle to the DLN-series adapter;
\param port - a port to get pin values from;
\param values - a pointer to an unsigned 8-bit integer. This integer will be filled with the pin values after function execution.
*/
DLN_RESULT DlnGpioPortGetVal(HDLN handle, uint8_t port, uint8_t *values);
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

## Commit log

2019-09-01 First commit
    Most design files are present. Still need to design enclosure lid and add readme, license, user manual, etc.
    [BufferBox.scad, BufferBox.stl, HighImpedanceBuffer.kicad_pcb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]
2019-09-01 mechanical update
    Extended edge of board with connectors 0.8mm so the connector faces sit flush with the front of the enclosure.
    [BufferBox.scad, BufferBox.stl, HighImpedanceBuffer.kicad_pcb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]
2019-09-15 Rev3, enclosure updates
    Rev3: Updating fuse for higher A^2s rating, fixing linear regulator footprint.
    Adding enclosure lid & label. Switching to 5/16" long screws for board. Updating diameter of hole for board screws so threads catch better.
    [BufferBox.scad, BufferBox.stl, BufferBoxLid.scad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]
2019-09-22 Adding SOT23 Zener Tester board
    Bill of Materials and CAD for board support plastic are still pending. This is a board for testing the reverse voltage / current curve of SOT23-3 package zener diodes using a programmable power supply, programmable voltage meter, and Diolan DLN-4ME or other programmable GPIO device.
    [SOT23ZenerTester.kicad_pcb, SOT23ZenerTester.sch]
2019-10-02 HighImpedanceBuffer Rev4, SOT23ZenerTester BoM, plate
    Improved layout, resistor value changes, and added capacitors to solve oscillation problem in high impedance buffer. Added BoM and CAD for 3D printed support plate to SOT23 Zener Tester.
    [HighImpedanceBuffer.kicad_pcb, HighImpedanceBuffer.sch, SOT23ZenerTester_Plate.scad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]
2019-10-03 SOT23 Zener Tester Rev1
    Fixing footprints of J2 and J4.
    [SOT23ZenerTester.kicad_pcb, SOT23ZenerTester.sch]
2019-11-16 initial commit
    Initial commit of a program that uses a SOT23ZenerTester board in conjunction with a Diolan DLN-4ME USB to GPIO/I2C/etc. Adapter, a Rigol DM3068 DMM, and an Itech 6100B serie PSU to measure the Voltage / Current curves of SOT23 package Zener diodes.
    The program files still require proper file header comments, and various desired features are missing:
    1. I would like to have the configuration file parser ignore the UTF8 byte order mark if it appears in the configuration file. UTF8 text files are not supposed to use the byte order mark, but Windows programs tend to add the byte order mark to UTF8 text files regardless.
    2. The output Office Open XML workbook file does not have a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
    [ExampleConfiguration.txt, example_test_results.xlsx]
2019-11-16 Various updates/fixes
    Replaced MIN_RECORDABLE_CURRENT constant in TestZeners.cpp with MIN_VALID_ZENER_CURRENT configuration field. Actually implemented POWER_LIMITED argument for MAX_CURRENT_{Zener Socket Name} fields in the configuration file. If the configuration file begins with a UTF8 byte order mark, that is now ignored.
    Added an end of test console message.
    [ExampleConfiguration.txt, example_test_results.xlsx]
2019-11-28 File reorganization, adding SingleShot test
    Reorganizing files so that files containing code shared between TestZeners and SingleShot are separated from files containing code specific to each test program.
    The SingleShot test sets up the power supply output voltage and closes the indicated test resistor relay before briefly closing the relay for each installed Zener diode, measuring the voltage, and op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
    [example_test_results.xlsx]
2020-02-15 adding TestSequencer
    README to follow later
    [TestSequencer.kicad_pcb, TestSequencer.sch, TestSequencer_BottomPlate.scad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]
2020-02-23 README, enclosure images, LICENSE touchup
    Finally adding a README file.
    Adding OpenSCAD image exports of the enclosure.
    Updating filenames and so forth in LICENSE.txt
2020-02-23 Adding README
    Adding a much needed README file.
    Touching up filenames in the LICENSE file.
    Adding a bottom assembly view, since this project does have some parts on the bottom of the PCB.
2020-02-24 Documentation updates
    Improving program file header comments, adding a README, and updating the file list in LICENSE.txt.
    [TestZeners_ExampleOutput.xlsx]
2020-06-26 First Commit
    Adding HH509R_Logger to the electronics repository.
    [example_data.xlsx]
2020-06-27 HH509R_Logger improvements
    1. More use of functions and fewer magic numbers.
    2. More comments (hopefully helpful).
    3. Added a mechanism that attempts to restart data collection if it stops.
    4. No longer putting the thermocouple reader in record mode; this appears to be unnecessary.
    5. Other minor touchups.
    [example_data.xlsx]
2020-06-29 Code cleanup, bad timestamp workaround
    Cleaned up the code some more:
    - Temperature format conversion is now in a function.
    - Using an enum to enumerate all possible commands to send to the thermocouple reader instead of constant strings.
    - Improved logic surrounding handling of incoming thermocouple reader data lines.
    Found a bug in the HH509R firmware: Timestamps past 9h 59m 59s device operation are invalid and contain a non-printable ASCII character. Since HH509R_Logger doesn't use the HH509R internal timestamps anyway, only the data validation code needed updating to accommodate this firmware bug. Validation testing is still running.
    Committing so this isn't just stored on my computer.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
2020-06-30 Code cleanup / improvement
    Simply not validating the most significant minutes digit works much better, allows data collection beyond 11 hours.
    Improved the logic for keeping the thermocouple reader out of special modes.
    Put data line validation into its own function.
    Line similarity comparisons no longer look at status data, which may change between lines that are otherwise the same in their temperature and timestamp. This avoids throwing out good data.
    Updated BasicWorkbook so that the default cell type is general; this makes it so that formulas actually work when you type them into other cells.
    Still haven't updated example_data.xlsx. Still haven't removed diagnostic logging. Those wi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
2020-07-02 Test Concluded
    Managed to log for 70 hours seemingly successfully. Removing diagnostic logging & updating example_data.xlsx.
    [example_data.xlsx]
2021-08-09 adding Big_Fast_Switch
    Adding the Big_Fast_Switch project and updating root readme.
    [703W-00-52_Qualtek.step, APT2012SURCK_I-V_298K.csv, APT2012SURCK_I-V_298K_Simulation.csv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]

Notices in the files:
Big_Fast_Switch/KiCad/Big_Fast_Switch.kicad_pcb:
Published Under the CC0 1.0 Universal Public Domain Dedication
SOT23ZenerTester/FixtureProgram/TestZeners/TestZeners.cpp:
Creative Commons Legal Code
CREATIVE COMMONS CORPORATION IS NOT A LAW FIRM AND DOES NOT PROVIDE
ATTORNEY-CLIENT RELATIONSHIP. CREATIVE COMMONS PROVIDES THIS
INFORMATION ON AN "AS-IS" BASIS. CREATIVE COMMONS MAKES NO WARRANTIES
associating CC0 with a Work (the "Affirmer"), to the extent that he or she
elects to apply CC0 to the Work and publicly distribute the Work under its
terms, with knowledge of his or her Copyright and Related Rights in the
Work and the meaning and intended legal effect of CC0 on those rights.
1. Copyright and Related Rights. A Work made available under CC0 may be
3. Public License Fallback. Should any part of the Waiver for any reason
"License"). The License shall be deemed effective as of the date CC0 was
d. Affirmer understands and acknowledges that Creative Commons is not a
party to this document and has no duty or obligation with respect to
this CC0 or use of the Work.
